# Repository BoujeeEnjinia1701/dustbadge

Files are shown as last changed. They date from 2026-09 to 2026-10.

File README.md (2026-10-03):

# DustBadge

     

**Area:** BioMedical · **TRL:** 3 of 9 (proof of concept on paper) · **Value-engineering target:** $91 USD · **Difficulty:** 3 of 5

A low-cost wearable dust monitor for workers in quarries, mines, stone fabrication and construction that estimates respirable dust exposure through the shift and warns before limits are reached.

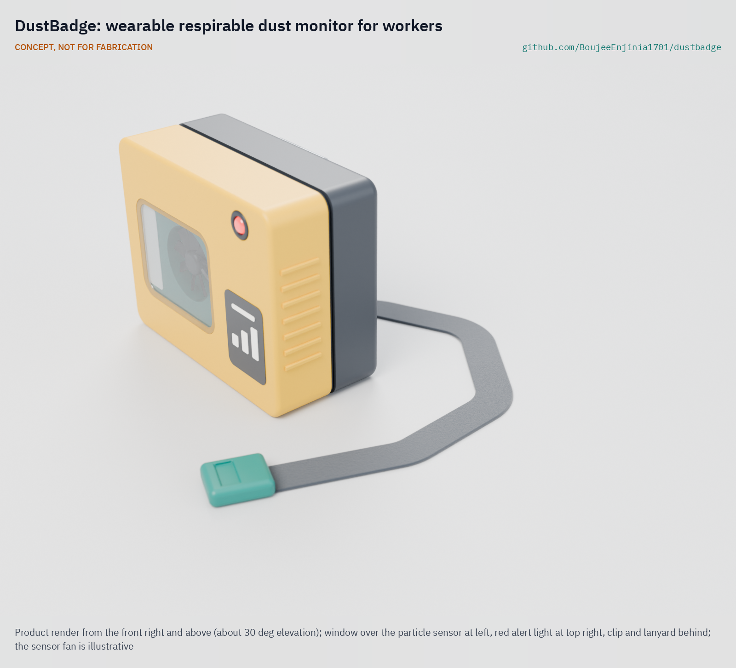
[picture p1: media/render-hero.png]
DustBadge: wearable respirable dust monitor for workers, product render


[Exploded render](media/render-exploded.png) · [Worn render](media/render-worn.png) · [Interactive 3D model](media/viewer.html) · [Concept blueprint (PDF)](media/concept-blueprint.pdf) · [General arrangement (PDF)](cad/drawings/DBG-DWG-001.pdf) · [Calculations](docs/04-calcs/01-sizing.md) · [Prototype build plan](docs/05-build-plan.md) · [Review note](docs/REVIEW.md)

## Concept rationale

A worker can only change what they can see. Filter sampling tells a site, days later, what one worker breathed on one day; a badge that vibrates when the shift average is heading over the limit tells the worker during the task, while there is still time to wet the cut, move upwind, put on a respirator or stop. An optical particle sensor cannot identify silica, so DustBadge measures respirable dust, corrects it with a site filter sample, and shows silica only as a labeled estimate. The result is a screening tool, not a compliance instrument. It is a research and educational prototype, not a medical device.

It is open and garage-buildable because the workers most exposed, in informal quarries, small stone workshops and artisanal mines, are the least likely to be covered by an employer's sampling program or to afford commercial personal dust monitors. One sensor module, one Bluetooth board, a phone-charger-sized cell and a 3D-printed case keep the parts at about $91, and worker organizations, clinics and universities can build, audit and adapt it under CERN-OHL-S-2.0.

## Burning platform

Silicosis killed more than 12,900 people worldwide in 2019 ([Chen, Liu and Xie, BMC Pulmonary Medicine, 2022](https://link.springer.com/article/10.1186/s12890-022-02040-9)), and it cannot be cured, only prevented. In the United States about 2.3 million workers are exposed to respirable crystalline silica, and OSHA estimated its 50 µg/m³ limit would prevent more than 600 deaths a year once fully effective ([US Department of Labor, 2016](https://www.dol.gov/newsroom/releases/osha/osha20160324)).

The burden is heaviest where monitoring is thinnest. An estimated 44 million people work in artisanal and small-scale mining, and a 2023 systematic review found a pooled silicosis prevalence of 23.9 % among those studied, with disease appearing after fewer than 6 years of work ([Howlett et al., PLOS Global Public Health, 2023](https://journals.plos.org/globalpublichealth/article?id=10.1371%2Fjournal.pgph.0002085)). Engineered stone has brought the disease back among young benchtop fabricators in high-income countries too: California's electronic case reporting found stone fabrication workers with silicosis in 2022 and 2023, one of whom died and two of whom needed lung transplants ([CDC MMWR, 2023](https://www.cdc.gov/mmwr/volumes/72/wr/mm7246a4.htm)).

## Where it could be used

### By industry

| Industry | Use |
| --- | --- |
| Quarrying and aggregates | Drillers, crusher and screen operators, and loader drivers checking exposure by task and location |
| Surface metal and non-metal mining | In-shift screening between regulatory samples (not underground coal or explosive atmospheres) |
| Stone benchtop fabrication | Warning when dry cutting, grinding or polishing pushes exposure up |
| Construction | Feedback when cutting concrete, brick, block or tile, and during demolition |
| Artisanal and small-scale mining | Low-cost exposure awareness for crews with no sampling at all, through NGOs and health programs |
| Occupational health research and training | A cheap, open screening tool for surveys, worker education and hygiene courses |

### By country or region

| Country or region | Why it matters there |
| --- | --- |
| India | A scoping review of Indian studies found a pooled silicosis prevalence of about 26 %, with 52 % radiological evidence among Rajasthan mine workers studied ([scoping review, PMC](https://pmc.ncbi.nlm.nih.gov/articles/PMC11776177/)). |
| South Africa | Among 14,221 employed gold miners surveyed, 3.8 % had silicosis, almost all more than 15 years after first exposure ([BMC Public Health, 2020](https://link.springer.com/article/10.1186/s12889-020-08876-2)). |
| Artisanal mining regions of Africa, Latin America and Asia | About 44 million artisanal and small-scale miners, with average respirable silica exposures reported from 0.19 to 89.5 mg/m³ in studies ([Howlett et al., 2023](https://journals.plos.org/globalpublichealth/article?id=10.1371%2Fjournal.pgph.0002085)). |
| United States | About 2.3 million exposed workers ([US Department of Labor, 2016](https://www.dol.gov/newsroom/releases/osha/osha20160324)); MSHA's 2024 rule applies a 50 µg/m³ limit and 25 µg/m³ action level to miners ([MSHA](https://www.msha.gov/regulations/rulemaking/silica)). |
| European Union | About 5.5 million workers are regularly exposed, mostly in construction, under a binding limit of 0.1 mg/m³ ([EU-OSHA OSHwiki](https://oshwiki.osha.europa.eu/en/themes/respirable-crystalline-silica)). |
| Australia | Banned the use, supply and manufacture of engineered stone benchtops, panels and slabs from 1 July 2024 after silicosis rose among fabricators ([SafeWork NSW](https://www.safework.nsw.gov.au/news/safework-public-notice/engineered-stone-prohibition-to-commence-1-july-2024)); removal and repair of installed stone still exposes workers. |

## What sparked the idea

The starting point was an instrument that already proves in-shift feedback works, and the narrow group it serves. Under MSHA's 2014 respirable coal mine dust rule, US underground coal operators have had to use the continuous personal dust monitor since February 1, 2016 for the miners in the dustiest occupations; the rule describes it as a device that "measures continuously, and in real-time, the concentration of respirable coal mine dust" and reports results during and at the end of the shift ([Federal Register, 79 FR 24814, 2014](https://www.federalregister.gov/documents/2014/05/01/2014-09084/lowering-miners-exposure-to-respirable-coal-mine-dust-including-continuous-personal-dust-monitors)). Quarry workers, stone fabricators and artisanal miners exposed to silica have no equivalent. DustBadge asks how much of that in-shift feedback an open, low-cost badge can deliver for silica, as a labeled estimate rather than a compliance measurement.

## Problem

Respirable crystalline silica causes silicosis, which is incurable. Personal exposure sampling is expensive and results arrive days later, so most workers never know their exposure.

## Concept

A chest-worn badge samples respirable dust (PM4) every second with an optical particle sensor, corrects it with a site filter sample, estimates silica from the site's silica fraction, keeps a running 8 h average and vibrates when the projected shift average is heading over the action level. The log goes to the worker's phone over Bluetooth, and the worker decides who sees it.

Full design precis: [docs/02-concept.md](docs/02-concept.md)

## Key components

- Optical particle sensor with a PM4 output (Sensirion SPS30 class, proposed)
- nRF52840 Bluetooth Low Energy module with flash for the shift log
- Vibration motor and red alert LED
- 2,000 mAh protected LiPo cell: 17.7 h of continuous sampling at the sensor's typical current, 12.8 h at its maximum current and 0 °C (DBG-CAL-001)
- Humidity and temperature sensor to flag readings that humidity or spray may bias
- 3D-printed high-visibility case with a downward, screened inlet and a spring clip, worn within 30 cm of the nose and mouth
- Phone app (web Bluetooth page or app) for the shift log

TRL 3 calculations ([DBG-CAL-001](docs/04-calcs/01-sizing.md)), updated for the recommendations Amish accepted on 2026-09-25 ([DBG-DDR-002](docs/decisions/0002-recommendations-accepted.md)): 64 x 52 x 31 mm (34 mm with the clip), about 121 g (limit 122 g), 17.7 h per charge typical and 12.8 h in the worst case, and an estimated $91.50 in parts, $0.50 over the $91 value-engineering target Amish set on 2026-09-26 (the foam pad of the worn version). On paper the design is not intrinsically safe. The working range is accepted as the sensor's 1 mg/m³ with over-range minutes flagged; accuracy at low dust levels depends on a larger reference sample and a per-task site factor; and in hot sun the badge must be worn shaded above 40 °C. See the [design precis](docs/02-concept.md) and [requirements](docs/03-requirements.md).

The working bill of materials is in [bom/bom.csv](bom/bom.csv).

## Building the prototype

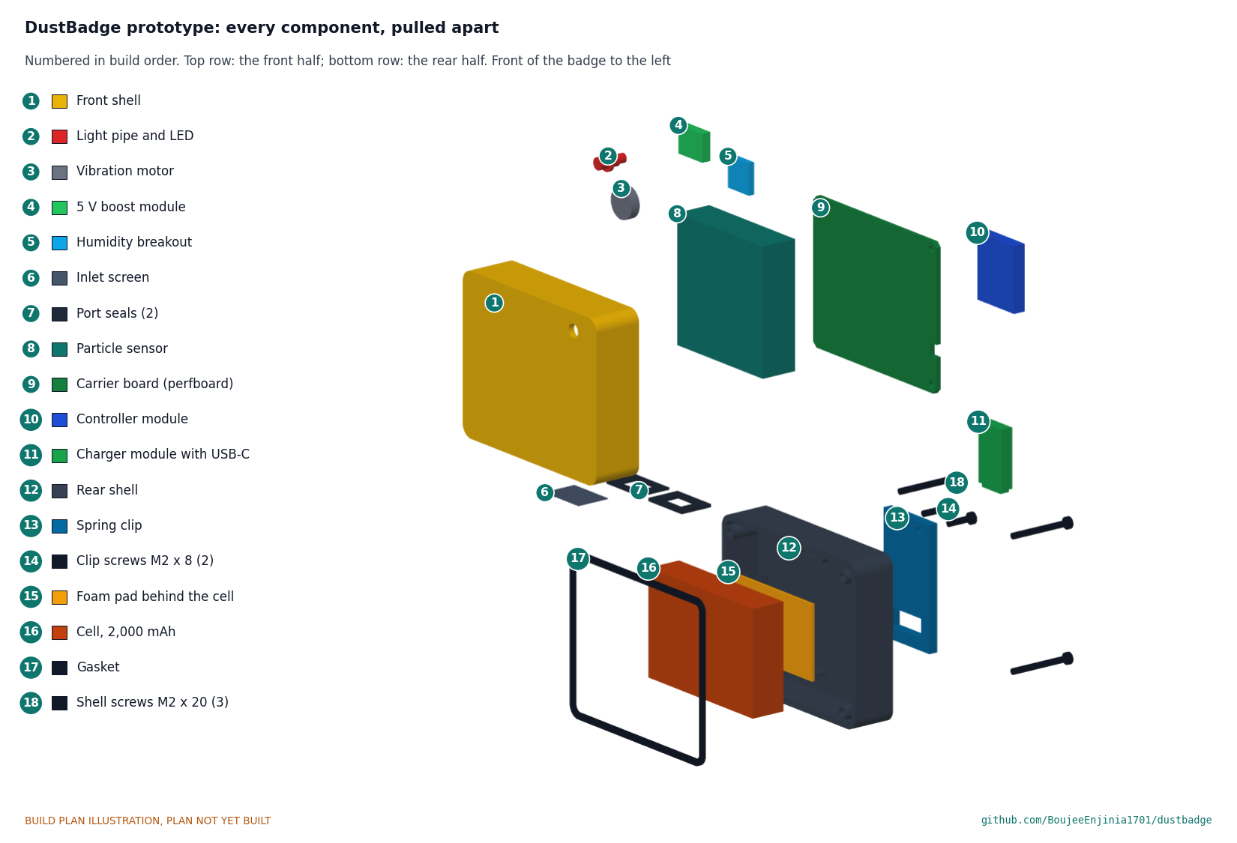
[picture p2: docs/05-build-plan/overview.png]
DustBadge prototype: every component pulled apart and numbered in build order


The [prototype build plan](docs/05-build-plan.md) (DBG-BLD-001) shows, in pictures, how to make each of the seventeen components and put them together in nine steps; nothing has been built yet. The made parts are two printed PETG shells, a printed TPU gasket and two port seals, a printed clear light pipe, a mesh inlet screen and a perfboard carrier; the sensor, cell, controller and small modules are bought and wired at block level. Writing the plan made the design buildable: the shells now close with three screws through a gasket, the sensor's ports are sealed to the floor slots, the sensor and cell are held by ribs, the clip is screwed on and the carrier board's modules have a place (DBG-DDR-003, open for Amish's review). Every picture is drawn from the model, and the model checks that each part touches what it should and clears what it should not.

## Safety

> A research and educational prototype, not a medical device and not certified monitoring or personal protective equipment. It does not replace regulatory sampling, dust controls or respirators, and a low reading does not mean the air is safe. It cannot measure silica directly; silica values are estimates.
>
> Not intrinsically safe: never use it in underground coal mines or anywhere flammable gas or combustible dust may be present.
>
> Lithium cells can overheat, vent and burn. Use a protected, fused cell, never charge the badge while it is worn, charge only between 0 and 45 °C, and never leave a first build charging unattended. In full sun above about 42 °C the badge can pass 60 °C; wear it shaded whenever the ambient is above 40 °C in full sun.

## Repository layout

| Folder | Contents |
| --- | --- |
| `docs/` | Problem, concept, requirements, calculations, prototype build plan, design decisions register and decision records |
| `cad/src/` | build123d Python source, the source of truth for all geometry |
| `cad/step/`, `cad/stl/` | Exported models for FreeCAD, other CAD tools and printing |
| `cad/drawings/` | 2D sketches and dimensioned drawings |
| `bom/` | Bill of materials |
| `electronics/` | KiCad schematics and PCB layouts |
| `firmware/` | Microcontroller code |
| `media/` | Renders, perspectives and photos |
| `build-log/` | Dated prototyping notes |

## Documentation

Controlled documents follow the portfolio [documentation standard](.kit/STANDARDS.md). Each carries a document ID (DBG-PRC-001 for the precis), a version and a revision history. Branded PDFs are built with `python .kit/render.py` and attached to GitHub Releases when a document is tagged, for example `DBG-PRC-001/v1.0`.

## Credits

Designed by Amish Chadha, with contributions from Dr. Geeti Chadha. See [CONTRIBUTORS.md](CONTRIBUTORS.md) for roles. To cite this design, use [CITATION.cff](CITATION.cff) (GitHub shows it as "Cite this repository").

AI assistance (Claude) was used to accelerate concept renders, prototype documentation and first-pass sizing calculations. Design direction and all decisions are Amish Chadha's, recorded in this repository's decision records (`docs/decisions/`).

## Licenses

- **Hardware** (CAD, drawings, BOM, electronics): [CERN-OHL-S v2](LICENSE)
- **Software** (firmware, scripts, notebooks): [MIT](LICENSE-SOFTWARE)

A project of the [Design Molecule](https://designmolecule.com) lab.

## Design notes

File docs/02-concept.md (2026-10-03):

---
doc_id: DBG-PRC-001
title: DustBadge design precis
project: DustBadge
doc_type: Design precis
version: "0.10"
status: Draft
date: '2026-10-02'
author: Amish Chadha
license: CERN-OHL-S-2.0
revisions:
- version: "0.1"
  date: '2026-09-25'
  author: Amish Chadha
  change: Initial scaffold
- version: "0.2"
  date: '2026-09-25'
  author: Amish Chadha
  change: Populate to TRL 2 (architecture, first-order numbers, safety, media)
- version: "0.3"
  date: '2026-09-25'
  author: Amish Chadha
  change: "TRL 3, design choices adopted per DBG-DDR-001; numbers checked against DBG-CAL-001; humidity sensor and thermistor charger added; general arrangement DBG-DWG-001"
- version: "0.4"
  date: '2026-09-25'
  author: Amish Chadha
  change: "Recommendations accepted by Amish (DDR-002): 2,000 mAh cell, R2 range accepted with over-range flag, R3 reference rule, sun use rule; numbers from DBG-CAL-001 v0.2; DBG-DWG-001 Rev P2"
- version: "0.5"
  date: '2026-09-26'
  author: Amish Chadha
  change: Budget approved by Amish; parts within the $91 budget
- version: "0.6"
  date: '2026-09-30'
  author: Amish Chadha
  change: "Design made constructable (DBG-DDR-003): fixings, gasket, seals and module positions; mass 119.9 g; build plan DBG-BLD-001 linked"
- version: "0.7"
  date: '2026-10-01'
  author: Amish Chadha
  change: Budget treated as a value-engineering target
- version: "0.8"
  date: '2026-10-01'
  author: Amish Chadha
  change: BioMedical area (DBG-DEC-001 v0.3); safety states a research and educational prototype, not a medical device
- version: "0.9"
  date: '2026-10-02'
  author: Amish Chadha
  change: 'Decisions of 2026-10-02 carried in: firmware on and off with a low-voltage cutoff, cell swelling rule, R9 at 122 g, site silica fraction method, first partner candidate'
- version: "0.10"
  date: '2026-10-02'
  author: Amish Chadha
  change: 'Worn version modelled (rear shell 1 mm deeper, foam pad): 120.7 g, 31 mm deep, USD 91.50; R15 over the target by USD 0.50; low-voltage cutoff 3.30 V'
---

# DustBadge design precis

## Summary

DustBadge is a chest-worn badge, 64 x 52 x 31 mm (34 mm with the clip) and about 121 g, that samples respirable dust continuously with an optical particle sensor, converts it to an estimate of respirable crystalline silica using a site calibration, keeps a running 8 h time-weighted average, and vibrates when the projected shift average is heading over the action level. The TRL 3 calculations (DBG-CAL-001 v0.7) show one off-the-shelf sensor, a Bluetooth module and a 2,000 mAh cell run a 12 h shift even at the sensor's maximum current and 0 °C (12.8 h; 17.7 h typical), for an estimated $91.50 in parts, $0.50 over the $91 value-engineering target Amish set on 2026-09-26 (DBG-DDR-002); the overage is the foam pad of the worn version. It cannot identify silica or replace compliance sampling. On paper it misses the hazardous-atmosphere requirement (R14) and, by $0.50, the cost requirement (R15); accuracy at low dust levels (R3) and operation in hot sun (R11) are at risk. The design choices below were decided by Amish on 2026-09-25 (DBG-DDR-002).

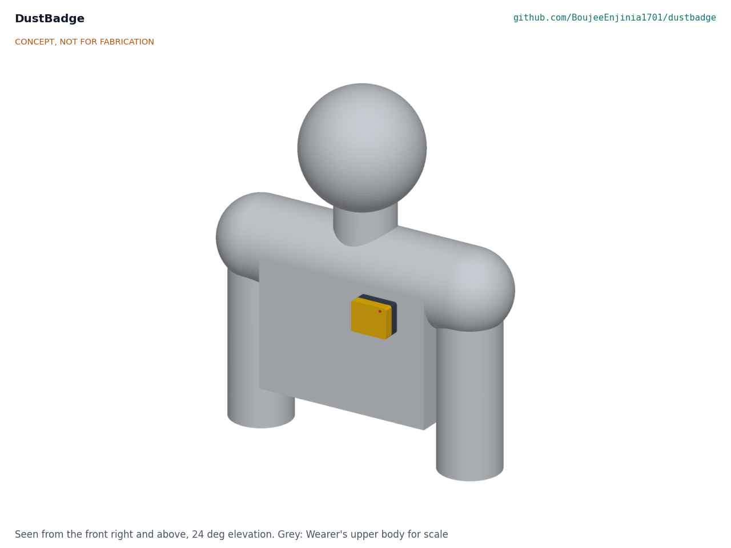
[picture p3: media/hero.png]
Figure 1. DustBadge worn on the upper chest, within the breathing zone. Grey is the wearer, for scale.


## How it works

1. **Sample.** A small fan in the particle sensor draws air in through a downward-facing screened inlet on the bottom of the badge. A laser counts and sizes particles, and the sensor reports mass concentration for particles up to 4 µm (PM4) every second.
2. **Calibrate.** A site factor, taken from at least one co-located filter sample, corrects the optical reading to a gravimetric respirable dust value. NIOSH notes that without such a factor, optical monitors can be off by up to 10 times ([Cauda, NIOSH, 2021](https://www.cdc.gov/niosh/nmam/pdf/chapter-am.pdf)). Chamber checks against a reference on the lab's CalRig calibration rig catch sensor drift between field samples.
3. **Estimate silica.** Calibrated respirable dust is multiplied by the site silica fraction (the quartz share of respirable dust for that site and task) to give an RCS estimate. With no fraction entered, the badge reports respirable dust only.
4. **Accumulate.** Every minute the firmware logs the 1 min average and updates the running TWA and a projection to the end of the shift at the current rate.
5. **Alert.** The badge vibrates and flashes when the projected 8 h RCS TWA passes the action level, and repeats at the limit. A short high peak (for example a dry cut) gives a separate brief alert so the worker can link the reading to the task.
6. **Sync.** At the end of the shift the worker's phone pulls the log over Bluetooth Low Energy (BLE). The worker decides whether to share it with a supervisor, hygienist or worker organization.

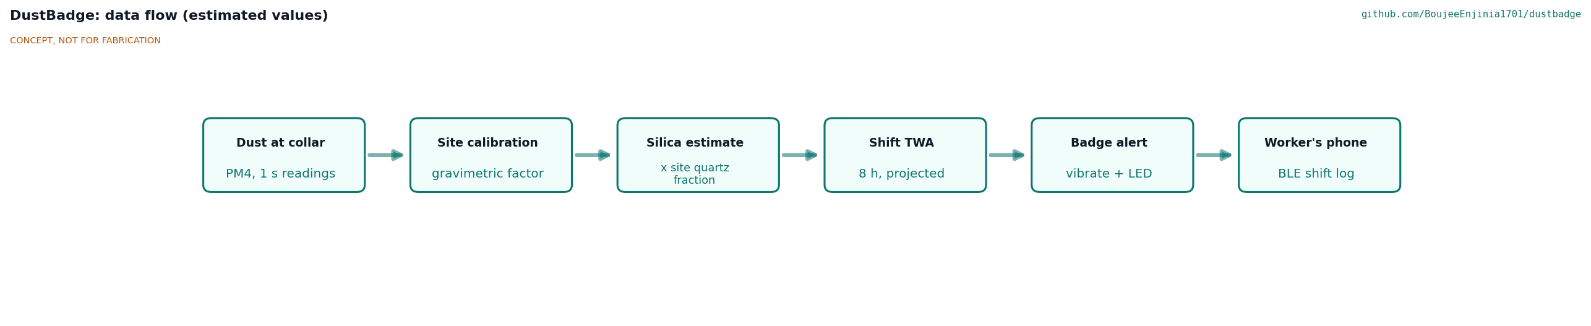
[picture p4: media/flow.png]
Figure 2. Data flow. Values are estimates.


## Main components

Table 1. Main components, numbered to match the exploded view and bom/bom.csv.

| # | Component | Proposed choice | Notes |
| --- | --- | --- | --- |
| 1 | Front shell | 3D-printed PETG, high-visibility yellow, with bottom inlet and outlet slots, USB-C opening and humidity vent; three screw bosses and two sensor stop ribs | Decided by Amish, 2026-09-25 (DBG-DDR-001, D7) |
| 2 | Inlet dust screen | Stainless mesh, about 1 mm aperture, a 16 x 11 mm square laid inside over the inlet slot and held by the inlet port seal | Keeps grit and splash out; must not act as a size selector for respirable particles |
| 3 | Particle sensor | Sensirion SPS30 class: PM1, PM2.5, PM4 and PM10 mass; 0 to 1,000 µg/m³; 41 x 41 x 12 mm; 26 g; 45 to 55 mA typical, 65 mA maximum at 5 V; PM4 precision ±25 µg/m³ below 100 µg/m³ and ±25 % above ([datasheet v2.0](https://sensirion.com/media/documents/8600FF88/64A3B8D6/Sensirion_PM_Sensors_Datasheet_SPS30.pdf)) | Chosen for its PM4 output. Decided by Amish, 2026-09-25 (DBG-DDR-001, D1) |
| 4 | Controller and BLE | nRF52840 module with 2 MB flash and LiPo charger (Seeed XIAO nRF52840 class) | Same module family as TremorTrace |
| 5 | Vibration motor | 10 mm coin motor, stuck to the inside of the front face | Felt through clothing when noise makes a beep useless |
| 6 | Alert LED | Red 3 mm LED in a printed clear light pipe with an inside flange, through the front face | Visible to the worker looking down and to coworkers |
| 7 | Carrier board | Perfboard carrying the controller and a 500 mA charger module with USB-C and a cell thermistor input; a 5 V boost module for the sensor and an SHT4x-class humidity and temperature breakout at a vent in the bottom face sit on the inside of the front face; polyfuse | Perfboard for the first build; humidity sensor and thermistor added at TRL 3 (DBG-CAL-001, sections B and C) |
| 8 | Battery | 2,000 mAh 3.7 V protected LiPo, about 50 x 34 x 11.5 mm, 38 g, with thermistor | Decided by Amish, 2026-09-25 (DBG-DDR-002, D8); was 1,500 mAh. Fills the space behind the carrier board; in the worn version 1.5 mm behind it, of which a 1 mm foam pad takes 1.0 mm (BOM line 13) |
| 9 | Rear shell | 3D-printed PETG with a flat printed TPU gasket and two TPU sensor port seals; three tubes that press the carrier board onto the front bosses, four cell locating ribs and two clip screw bosses | Holds the cell away from the body side; closed by three M2 x 20 screws from the rear face (DBG-DDR-003) |
| 10 | Clip | Stainless spring clip with strap loop, held by two M2 x 8 screws | For a shirt pocket, collar, harness or hi-vis vest |

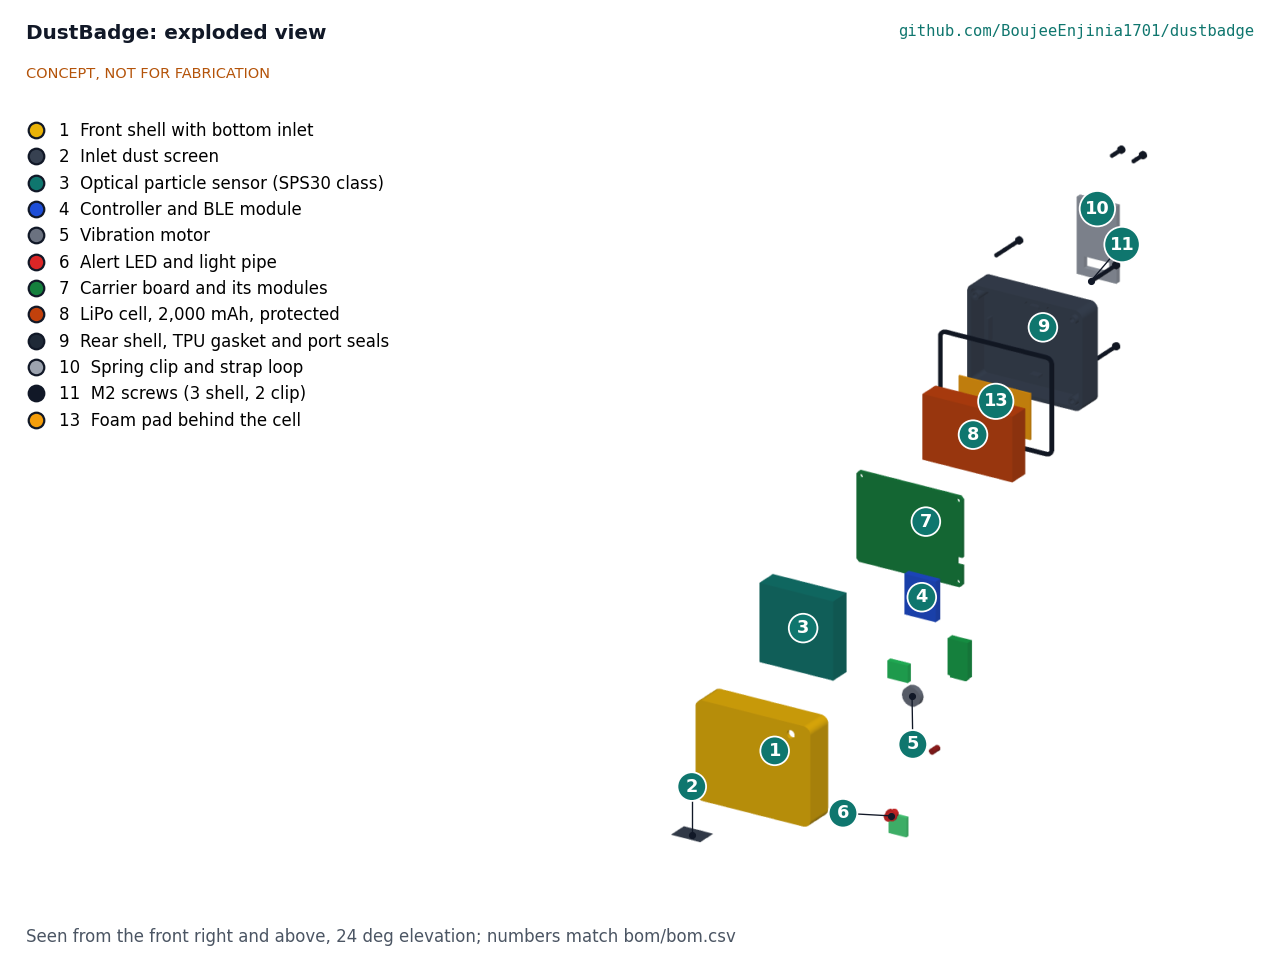
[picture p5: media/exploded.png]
Figure 3. Exploded view with BOM numbers.


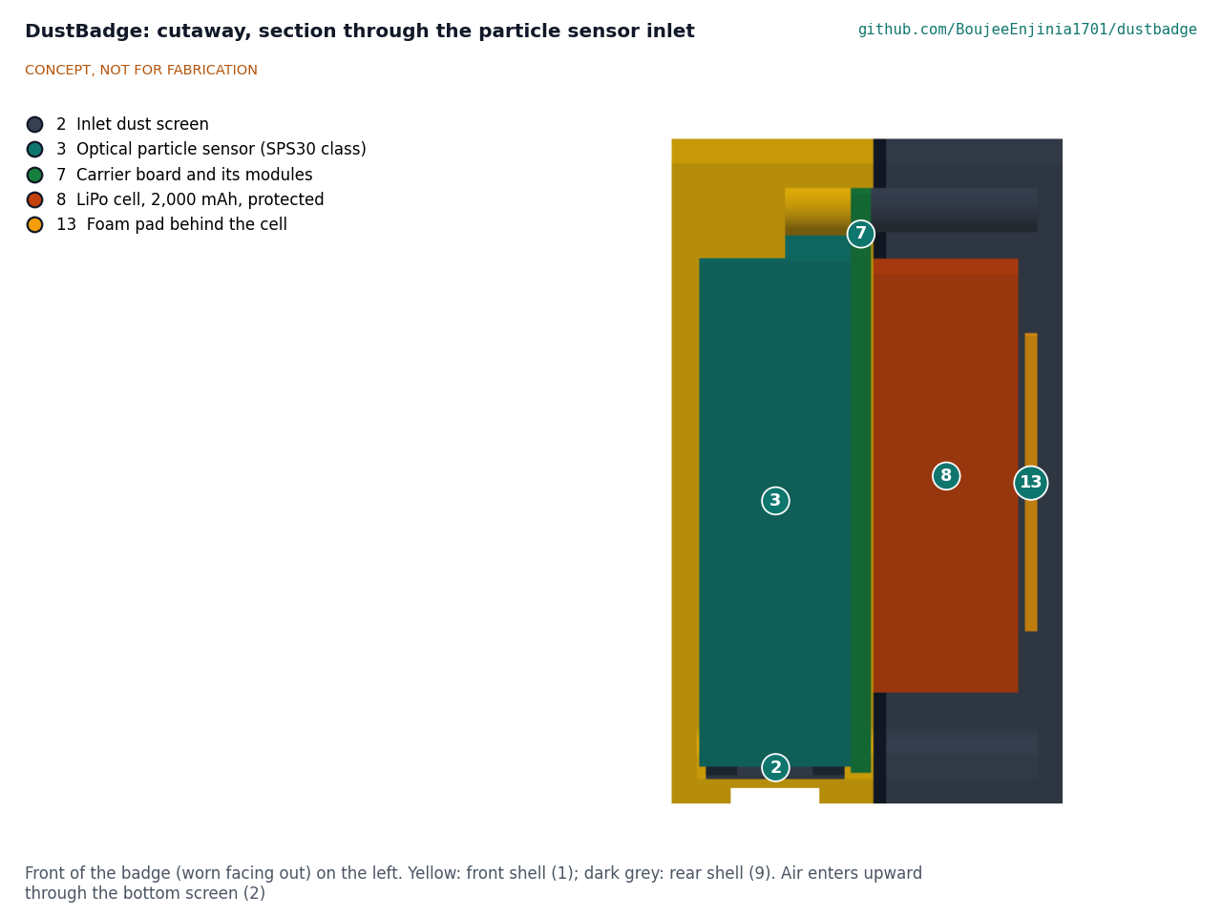
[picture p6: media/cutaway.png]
Figure 4. Section through the particle sensor, front of the badge on the left. Air enters through the bottom screen (2).


## Numbers checked at TRL 3

All values come from DBG-CAL-001 v0.2 and its script `docs/04-calcs/sizing.py`; the bracketed tags point to its output lines.

Table 2. Key numbers.

| Quantity | Value | Basis | Requirement |
| --- | --- | --- | --- |
| Power drawn from the cell | 335 mW typical, 393 mW maximum | Sensor 55 or 65 mA at 5 V through an 85 % boost, plus 11 mW for controller, BLE and humidity sensor [A3] | |
| Usable cell energy | 5.92 Wh; 5.03 Wh at 0 °C | 2,000 mAh x 3.7 V, 80 % usable, 85 % at 0 °C [A1] | |
| Run time, continuous sampling | 17.7 h typical; 12.8 h at maximum current and 0 °C | [A3] | R7 met |
| Cell for 12 h in the worst case | about 1,880 mAh; the 2,000 mAh cell gives a 7 % margin | [A4, A6] | |
| Charge time | 4.2 h at 500 mA | [B1] | |
| Shell temperature in full sun | about 48 °C at 30 °C ambient, 63 °C at 45 °C ambient; at most 57.8 °C under the use rule (shaded above 40 °C) | Solar and electrical heat against surface losses [C1, C3] | R11 at risk |
| Respirable dust at the action level | 250 µg/m³ at 10 % silica; 31 µg/m³ at 80 % silica | 25 µg/m³ RCS divided by the silica fraction [E2] | Within the 1 mg/m³ range |
| PM4 precision before site calibration | ±25 µg/m³ below 100 µg/m³ | Datasheet; 80 % of the dust level at the action level for quartz-rich stone [F4] | Site factor essential |
| Upper end of useful range | 1 mg/m³ with over-range flag; limit in range for silica fractions of 5 % or more | Sensor specification [E1, E3] | R2 met as restated |
| Shift average uncertainty after site calibration | ±21 to ±29 % (quarry); ±22 to ±30 % (quartz-rich stone with the 4.2 L/min, two-shift reference) | Root sum of squares, assumed terms [F2, F3] | R3 at risk |
| Log size | 11.5 kB per 12 h shift; about 182 shifts in 2 MB | 16-byte record each minute [H1] | R12 met |
| Inlet to nose and mouth | 242 mm | Model, collar or upper-strap mount [I1] | R8 met |
| Mass | 120.7 g | Shells, gasket and seals from model volume, parts from datasheets [J2] | R9 met against 122 g (relaxed from 120 g on 2026-10-02), 1.3 g margin with the deeper rear shell and foam pad needed before anyone wears the badge |
| Size | 64 x 52 x 31 mm; 34 mm deep with the clip | Model | R9 met |
| Parts cost | $91.50 | bom/bom.csv [L1, L2] | R15 not met: $0.50 over the value-engineering target ($91) |

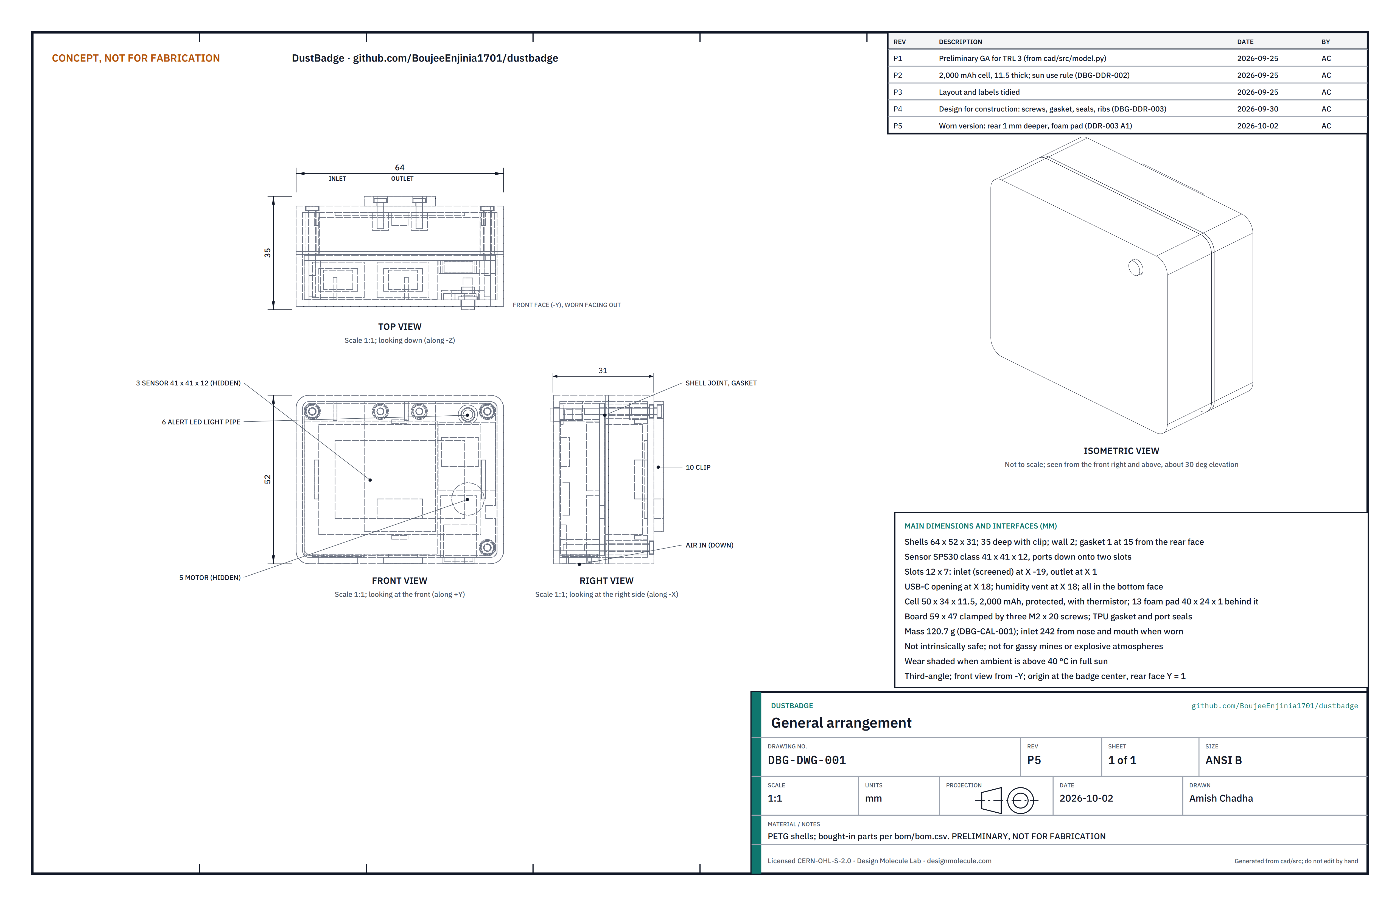
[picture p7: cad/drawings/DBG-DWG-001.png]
Figure 5. General arrangement DBG-DWG-001, Rev P3, from the parametric model.


## Key design choices

- **Estimate, never claim, silica.** The badge shows respirable dust as the measured quantity and RCS only as a labeled estimate from a site fraction. Decided by Amish, 2026-09-25 (DBG-DDR-001, D2).
- **PM4 sensor rather than a cheaper PM2.5 sensor.** The SPS30 class reports the size band closest to the respirable convention. A Plantower PMS5003 costs less but reports only up to PM10 with no PM4 bin. Decided by Amish, 2026-09-25 (DBG-DDR-001, D1).
- **Inlet facing down.** Reduces direct deposition of large chips and water spray into the sensor. Decided by Amish, 2026-09-25 (DBG-DDR-001, D7).
- **Continuous sampling.** Cutting and grinding tasks can last a minute or two, so the fan runs all shift rather than duty cycling, which the 2,000 mAh cell covers (R7 met on paper). Decided by Amish, 2026-09-25 (DBG-DDR-001, D4).
- **Default limits.** US OSHA and MSHA values by default (25 µg/m³ action level, 50 µg/m³ limit, 8 h TWA), configurable for other jurisdictions such as the EU 100 µg/m³. Decided by Amish, 2026-09-25 (DBG-DDR-001, D3).
- **Larger cell.** 2,000 mAh so that R7 holds at the sensor's maximum current and at 0 °C, at 8 g and $3. Decided by Amish, 2026-09-25 (DBG-DDR-002, D8).
- **Projected TWA alert.** Alerting on the projected shift average (dose so far plus the last 60 min mean rate) rather than on instantaneous readings avoids alarms every time a truck passes, while a separate brief peak alert (1 min mean over 250 µg/m³ RCS) still links dust to tasks. DBG-CAL-001 section G checks five scenarios.
- **Over-range readings count, not vanish.** A minute above the sensor's 1 mg/m³ range is logged at the range limit, flagged and counted toward the projection, so the badge alerts rather than going quiet. The 1 mg/m³ range with this flag is accepted for the first sectors (surface quarries and stone fabrication) instead of a wider-range sensor. Decided by Amish, 2026-09-25 (DBG-DDR-002, D11).
- **Reference sample at low-dust, high-silica sites.** Where respirable dust at the action level is below about 100 µg/m³, the site factor comes from a 4.2 L/min cyclone over two shifts, so the filter holds enough mass to weigh. Decided by Amish, 2026-09-25 (DBG-DDR-002, D9).
- **Sun use rule.** Wear the badge shaded, under a vest flap or out of direct sun, when the ambient is above 40 °C in full sun. A lighter shell is a later option, to be tested at TRL 4, which is on hold. Decided by Amish, 2026-09-25 (DBG-DDR-002, D10).
- **Humidity flag.** The added humidity sensor flags readings above 80 % RH, the sensor's best-performance limit, and sudden rises during wet cutting or spraying.
- **On and off in firmware.** There is no switch: the controller switches the boost off through its enable input and sleeps, waking on USB power, and a firmware low-voltage cutoff set above the cell protection threshold (3.30 V at the cell under load, against an assumed 2.75 V cut-out; DBG-CAL-001 [A7]) means the cell is never run down to the protection cut-out. Decided by Amish, 2026-10-02 (DBG-DDR-003, A2).
- **Cell swelling allowance.** The 0.7 mm of free depth round the cell is accepted only for bench work with nobody wearing the badge. Before anyone wears it, the badge is deepened 1 mm with a foam pad behind the cell, and R9 is relaxed to 122 g. The model and the drawings now show this worn version. Decided by Amish, 2026-10-02 (DBG-DDR-003, A1).
- **Site silica fraction.** By default, two or three cyclone filter samples per site go to an accredited laboratory for X-ray diffraction (as in NIOSH Method 7500), and the badge shows no silica estimate until a site fraction exists; field infrared analysis can come later where a partner has the instrument. Decided by Amish, 2026-10-02 (DBG-DDR-001, O2).
- **Worker-owned data.** Logs stay on the badge and the worker's phone unless the worker shares them, and are never used for discipline. Decided by Amish, 2026-09-25 (DBG-DDR-001, D5).

## Dependencies on other lab projects

- **CalRig** provides the chamber for periodic badge-to-badge and drift checks. Its TRL 2 design uses incense smoke from 5 to 300 µg/m³ and states that results will not transfer directly to mineral dust, so it cannot characterize the sensor above 1 mg/m³ or set a site factor. Field gravimetric samples are still needed for the site factor, because chamber aerosol is not site dust. The badge (64 x 52 x 33 mm) fits CalRig's 400 x 300 x 300 mm chamber.
- The badge does not use FieldNode, which is a fixed outdoor node; a FieldNode with the same sensor could log area dust at a site as a later option.

## Safety

> **Safety:** DustBadge is a research and educational prototype, not a medical device. It is not certified monitoring equipment or personal protective equipment, and it does not replace regulatory exposure sampling, engineering controls or respirators. A low reading does not mean the air is safe: the sensor cannot see silica directly, can drift, and can under-read outside its calibration.
>
> **Safety:** It is not intrinsically safe. Do not use it in underground coal mines or in any place where flammable gas or combustible dust may be present.
>
> **Safety:** The lithium cell is worn against the body. Use a protected cell with a fuse, never charge while worn, do not charge above 45 °C or below 0 °C, and stop use if the badge becomes warm or swollen or has been crushed. In full sun above about 42 °C ambient the shell can pass 60 °C (DBG-CAL-001, section C), above the cell's and the sensor's limits; wear it shaded or under a vest flap whenever the ambient is above 40 °C in full sun. Do not leave a first build charging unattended.
>
> **Safety:** Exposure logs are health-related personal data. Keep them with the worker, and never use them to discipline workers.

## Open questions

- Accuracy (R3): the error terms in DBG-CAL-001 section F are assumed, and a factor shared across badges misses ±25 % even with the larger reference. Measuring them is TRL 4 work, on hold.
- Range (R2): the sensor's response above 1 mg/m³ to mineral dust is unknown and cannot be checked on CalRig as designed.
- Humidity and water spray (R11): the size of the bias from wet cutting and dust suppression sprays is unknown; the badge can flag high humidity.
- Inlet: does the screened downward inlet change sampling efficiency for respirable particles when the worker moves?
- First co-design partner (DBG-DDR-001, O1): the first candidate to approach is a university industrial hygiene group that already samples respirable crystalline silica, for example one linked to a NIOSH Education and Research Center, with a stone fabrication shop or surface quarry as the site (decided by Amish, 2026-10-02); nothing is agreed.

Prototype build plan: [DBG-BLD-001](05-build-plan.md); design decisions: [DBG-DEC-001](06-design-decisions.md). Concept media: [blueprint sheet](../media/concept-blueprint.pdf), [interactive 3D model](../media/viewer.html). General arrangement: [DBG-DWG-001](../cad/drawings/DBG-DWG-001.pdf). Model: `cad/src/model.py`, exports in `cad/step/` and `cad/stl/`.

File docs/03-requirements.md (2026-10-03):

---
doc_id: DBG-REQ-001
title: DustBadge requirements
project: DustBadge
doc_type: Requirements
version: "0.9"
status: Draft
date: '2026-10-02'
author: Amish Chadha
license: CERN-OHL-S-2.0
revisions:
- version: "0.1"
  date: '2026-09-25'
  author: Amish Chadha
  change: Initial scaffold
- version: "0.2"
  date: '2026-09-25'
  author: Amish Chadha
  change: First measurable requirements for TRL 2, with status against the concept
- version: "0.3"
  date: '2026-09-25'
  author: Amish Chadha
  change: "TRL 3, status from DBG-CAL-001 for every requirement; R8 restated for the inlet; R6 defaults follow DBG-DDR-001 D3; R11 and R3 now not met, R10 not verifiable at TRL 3"
- version: "0.4"
  date: '2026-09-25'
  author: Amish Chadha
  change: "Recommendations accepted by Amish (DDR-002): R2 restated to 1 mg/m³ with over-range flag, R3 reference rule, R11 sun use rule; statuses from DBG-CAL-001 v0.2 with the 2,000 mAh cell"
- version: "0.5"
  date: '2026-09-26'
  author: Amish Chadha
  change: Budget approved by Amish; R15 target $91, status Not met to Met on paper
- version: "0.6"
  date: '2026-09-30'
  author: Amish Chadha
  change: "Design made constructable (DBG-DDR-003); R9 mass 119.9 g, 0.1 g margin; no status changed"
- version: "0.7"
  date: '2026-10-01'
  author: Amish Chadha
  change: Budget treated as a value-engineering target
- version: "0.8"
  date: '2026-10-02'
  author: Amish Chadha
  change: 'R9 relaxed to 122 g by Amish on 2026-10-02; site silica fraction assumption restated'
- version: "0.9"
  date: '2026-10-02'
  author: Amish Chadha
  change: 'R15 not met by USD 0.50 after the foam pad of the worn version; R9 met at 120.7 g against 122 g'
---

# DustBadge requirements

These are the requirements for the concept, with their status from the TRL 3 calculations in DBG-CAL-001 v0.7. On 2026-09-25 Amish accepted the review recommendations (DBG-DDR-002): R2 is restated to the sensor's 1 mg/m³ range with an over-range flag, R3 keeps ±25 % but requires a larger reference sample at low-dust, high-silica sites, R11 adds a use rule for full sun, and the cell grows to 2,000 mAh. On 2026-09-26 Amish set the value-engineering target at $91 to match the priced BOM (DBG-DDR-002, O3), so R15 was within the target. On 2026-10-02 the foam pad of the worn version took the parts cost to $91.50, so R15 is no longer met (by $0.50). On paper two requirements are not met (R14 intrinsic safety, out of scope, and R15 cost), two are at risk (R3 accuracy and R11 site conditions), one cannot be verified at TRL 3 (R10), and ten are met, six by calculation and four by design.

Table 1. Requirements and concept status.

| ID | Requirement | Target | Status at TRL 3 (DBG-CAL-001) | Verification (TRL 3 or later) |
| --- | --- | --- | --- | --- |
| R1 | Measure the respirable dust fraction | Mass concentration of particles up to 4 µm (PM4), a proxy for the ISO 7708 respirable convention | Met by design. PM4 is a proxy: for quartz, optical PM4 would include grains up to about 6.5 µm aerodynamic, while the sensor under-sees coarse grains (CAL-001, D) | Datasheet review; later comparison with a cyclone sampler |
| R2 | Cover the working range | 0 to 1 mg/m³ respirable dust; minutes above the range flagged, logged at the range limit and counted toward the projection. Restated from 0 to 5 mg/m³ for the first sectors in D6 (DBG-DDR-002 D11) | Met on paper. The RCS limit lies in range only for silica fractions of 5 % or more; above the range the badge reports only that dust was over range (CAL-001, E) | Calculation of expected site ranges; chamber test on CalRig |
| R3 | Accuracy after site calibration | Shift average within ±25 % of a co-located gravimetric sample. Where respirable dust at the action level is below about 100 µg/m³ (low-dust, high-silica sites such as quartz-rich stone), the reference is a 4.2 L/min cyclone over two shifts (DBG-DDR-002 D9) | **At risk.** Met on paper with a factor per task on the same badge: ±21 % (quarry), ±22 % (quartz-rich stone with the D9 reference). Not met with one factor shared across badges per site: ±29 to ±30 % (CAL-001, F). Error terms assumed | Error budget at TRL 3; later co-located field samples |
| R4 | Estimate silica exposure | RCS estimate = calibrated PM4 mass x site silica fraction, always labeled as an estimate; dust shown alone when no fraction is entered | Met by design | Firmware sketch review |
| R5 | Update often enough to catch tasks | 1 s readings, 1 min logged averages, running 8 h time-weighted average (TWA) updated every minute | Met by design; the sensor gives new readings every second | Firmware sketch review |
| R6 | Warn before a limit is reached | Vibration and LED when the projected 8 h RCS TWA exceeds the action level (default 25 µg/m³) and a repeated alert at the limit (default 50 µg/m³); both configurable | Met by design and on paper: five scenarios alert as intended, one early warning after a single heavy cut (CAL-001, G). Defaults per DBG-DDR-001 D3 | Firmware sketch review |
| R7 | Last a full shift | 12 h of continuous sampling per charge | Met on paper with the 2,000 mAh cell (DBG-DDR-002 D8): 17.7 h at the typical 55 mA and 25 °C; 12.8 h at the 65 mA maximum and 0 °C (CAL-001, A) | Power budget calculation |
| R8 | Wearable in the breathing zone | Inlet worn within 30 cm of the nose and mouth; clip or harness loop | Met on paper: inlet 242 mm from the nose and mouth at a collar or upper-strap mount; a mount more than 269 mm below them fails (CAL-001, I) | Massing model |
| R9 | Light and small | Mass 122 g or less (relaxed from 120 g by Amish, 2026-10-02, for the 1 mm deeper rear shell and foam pad needed before anyone wears the badge); no larger than 75 x 55 x 35 mm | Met on paper: 120.7 g with the worn version (rear shell 1 mm deeper, foam pad), a 1.3 g margin against 122 g; 64 x 52 x 34 mm with the clip (CAL-001, J) | Massing model, then weighing |
| R10 | Survive the site | Electronics splash and dust protected (IP54 target except the sensor air path); inlet facing down; survives a 1.5 m drop onto concrete | Not verifiable at TRL 3: 750 to 1,500 g deceleration on a 1.5 m drop; gasketed joint untested (CAL-001, K) | Design review; later drop and spray tests |
| R11 | Work in site conditions | 0 to 45 °C, 10 to 90 % RH non-condensing; readings flagged when humidity or spray may bias them. Use rule: worn shaded when the ambient is above 40 °C in full sun (DBG-DDR-002 D10) | **At risk.** Under the use rule the shell stays at or below 57.8 °C, 2.2 K under the sensor's 60 °C limit; without it, about 63 °C in full sun at 45 °C. Sensor best performance only to 40 °C and 80 % RH; humidity flag possible with the RH sensor (CAL-001, C) | Literature and datasheet review |
| R12 | Keep a shift log | At least 30 shifts of 1 min records on the badge; export over Bluetooth Low Energy to the worker's phone | Met on paper: 11.5 kB per 12 h shift, about 182 shifts in 2 MB (CAL-001, H) | Storage calculation |
| R13 | Protect the worker's data | Stored on the badge and the worker's phone; shared with an employer only by the worker's choice | Met by design (DBG-DDR-001 D5) | Design review |
| R14 | Safe in hazardous atmospheres | Certified intrinsically safe for gassy mines and explosive atmospheres | **Not met and out of scope** for this prototype; it must be labeled not for such use | Design review |
| R15 | Low cost and buildable | Parts $91 or less (was $90; DBG-DDR-002 O3); no custom PCB required for the first build | Not met: $91.50, $0.50 over the $91 target, because of the foam pad of the worn version (CAL-001, L) | Priced BOM |

## Assumptions

- The respirable convention in ISO 7708 has a 50 % cut near 4 µm aerodynamic diameter; PM4 from an optical sensor is used as a proxy.
- A site silica fraction (the quartz share of respirable dust) is available for each site and task from at least one filter sample analyzed by a laboratory or a field infrared method. Where no laboratory is near, two or three cyclone filter samples per site are sent to an accredited laboratory for X-ray diffraction (as in NIOSH Method 7500), and no silica estimate is shown until a site fraction exists (decided by Amish, 2026-10-02, DBG-DDR-001, O2).
- The wearer follows the sun use rule in R11; the badge cannot enforce it.
- Default limits follow US OSHA and MSHA (50 µg/m³ limit and 25 µg/m³ action level, 8 h TWA), decided by Amish on 2026-09-25 (DBG-DDR-001 D3, DBG-DDR-002). Other jurisdictions can be configured, for example the EU binding limit of 100 µg/m³.
- The calculation assumptions (sensor figures, cell, error terms, thermal coefficients) are listed in DBG-CAL-001, Table 1.
- Shifts are up to 12 h; the projected TWA is normalized to 8 h as the regulations define it.

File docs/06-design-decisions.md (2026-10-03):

---
doc_id: DBG-DEC-001
title: DustBadge design decisions register
project: DustBadge
doc_type: Design decisions register
version: "0.5"
status: Draft
date: '2026-10-02'
author: Amish Chadha
license: CERN-OHL-S-2.0
revisions:
  - version: "0.1"
    date: '2026-09-30'
    author: Amish Chadha
    change: Register opened with the open decisions from the review note, the decision records and the build plan work
  - version: "0.2"
    date: '2026-10-01'
    author: Amish Chadha
    change: Budget treated as a value-engineering target
  - version: "0.3"
    date: '2026-10-01'
    author: Amish Chadha
    change: Dr. Geeti Chadha added as a contributor and the project moved to the BioMedical (healthcare) area (decided by Amish)
  - version: "0.4"
    date: '2026-10-02'
    author: Amish Chadha
    change: 'Amish approved the recommendations for all ten open decisions (2026-10-02); DBG-DDR-003 accepted; moved to decisions made'
  - version: "0.5"
    date: '2026-10-02'
    author: Amish Chadha
    change: 'Worn version carried into the design: foam pad on the BOM (USD 91.50, USD 0.50 over the target); value engineering section restated; target change proposed'
---

# DustBadge design decisions register

Every design decision still to be made, and every decision made, in one place. Each decision is argued in full in its decision record under `docs/decisions/`; this register is the index Amish works from. The build plan (`docs/05-build-plan.md`) describes the design as it stands and does not list open decisions.

## Open decisions

| # | Decision | Options | Recommendation |
| --- | --- | --- | --- |
| 1 | Value-engineering target. The foam pad of the worn version (USD 0.50, BOM line 13) takes the estimated cost to USD 91.50, USD 0.50 over the USD 91 target, so R15 is not met. `budget_usd` is unchanged at 91. | (a) raise the target to USD 92; (b) keep USD 91 and look for USD 0.50 of savings when parts are bought; (c) keep USD 91 and accept R15 as not met. | (a), so that the target covers the worn version; the optional lanyard (about USD 1) would still sit outside it. **Proposed, awaiting Amish.** |

## To confirm when parts are bought

| # | What to confirm | Why it matters | Source |
| --- | --- | --- | --- |
| 1 | The cell, including its protection board, is no larger than 50 x 34 x 11.5 mm, its lead leaves at one short side, and its plug polarity matches the charger | The cell ribs, the swelling allowance (0.7 mm in the bench version, 1.7 mm with the foam pad of the worn version) and the board notch are sized for it | DBG-DDR-003, P8 |
| 2 | The charger module is no larger than 11 x 19 mm with its USB-C on a short edge, and its temperature window is 0 to 45 °C | It must fit beside the sensor with its USB-C in the opening, and the charge stop is part of the safety case | DBG-DDR-003, P6 |
| 3 | The boost module (11.4 x 9 mm or less, with an enable input) and the humidity breakout (10 x 10 mm or less, sensor at one edge) | They are taped into a strip 17 mm wide beside the sensor; the humidity sensor must sit over its vent | DBG-DDR-003, P6 |
| 4 | Where the particle sensor's cable leaves it, and the cable length | The model leaves room above and beside the sensor between the stop ribs; a connector on another face would need the ribs moved | DBG-DDR-003, P5 |
| 5 | The spring clip's base leaf is flat and wide enough for two holes 12 mm apart | The clip is held by two M2 x 8 screws | DBG-DDR-003, P9 |
| 6 | The pilot hole for the M2 thread-forming screws in PETG (1.7 mm assumed), from the screw maker's data | Too large a hole strips; too small cracks the boss | DBG-DDR-003, P1 |

## Value engineering

Value-engineering target: USD 91 (a hypothetical control target, not a limit). Estimated cost of the constructable design: USD 91.50 (USD 0.50 over the target). The estimate rests on indicative prices.

Main cost drivers: the optical particle sensor (USD 48.00, 52 % of the cost), the 2,000 mAh LiPo cell (USD 13.00; it added USD 3), the controller and BLE module (USD 10.00) and the carrier board (USD 9.00).

Savings worth trying: confirming prices when parts are bought. A 1,500 mAh cell would save USD 3 but returns R7 (a full shift) to at risk. The optional breakaway lanyard (decided on 2026-10-02 for TRL 4) would take the estimate about USD 1 over the target, and the foam pad of the deeper worn version (USD 0.50) is already in the estimate and is what takes it over the target.

## Decisions made

| Date | Decision | Decided by | Record |
| --- | --- | --- | --- |
| 2026-09-25 | TRL 2 review items D1 to D7: SPS30-class sensor, silica shown only as a labeled estimate, US OSHA and MSHA default limits, continuous sampling, worker-owned data, surface quarries and stone fabrication first, downward screened inlet with a yellow shell and clip | Amish: "i accept all your recommendations, go with them across all repos." | DBG-DDR-001, DBG-DDR-002 |
| 2026-09-25 | D8 to D11: 2,000 mAh cell; R3 reference rule (4.2 L/min cyclone over two shifts at low-dust, high-silica sites); sun use rule; R2 restated to 1 mg/m³ with an over-range flag | Amish, same instruction | DBG-DDR-002 |
| 2026-09-26 | Value-engineering target set to $91 to match the priced BOM (O3) | Amish: "i approve all the budget items." | DBG-DDR-002 v0.2 |
| 2026-10-01 | Dr. Geeti Chadha added as a contributor (CONTRIBUTORS.md, README Credits) and the project moved to the BioMedical (healthcare) area, with soft, non-clinical wording: a research and educational prototype, not a medical device | Amish: "yes add Dr. Geeti Chadha to breathebox and dustbadge and make those both healthcare projects" | `project.yaml`, `CONTRIBUTORS.md`, `README.md`, DBG-PRB-001 v0.7, DBG-PRC-001 v0.8 |
| 2026-10-02 | Design for construction accepted: P1 to P10 as made; the TRL 4 drop test also checks that the boost module, humidity board and motor stay on their foam tape | Amish: "i approve your recommendations for all 555 open decisions." | DBG-DDR-003, Table 1 |
| 2026-10-02 | Cell swelling: the 0.7 mm allowance (a) is accepted only for bench work with nobody wearing the badge; before anyone wears it, (b): the badge is deepened 1 mm with a foam pad behind the cell and R9 is relaxed to 122 g. Return to (a) only if the bought cell's datasheet states swelling under about 6 % | Amish: "i approve your recommendations for all 555 open decisions." | DBG-DDR-003, A1 |
| 2026-10-02 | On and off: firmware only (the boost switched off through its enable input, the controller asleep, waking on USB power), with a firmware low-voltage cutoff set above the cell protection threshold so the cell is never run down to the protection cut-out | Amish: "i approve your recommendations for all 555 open decisions." | DBG-DDR-003, A2 |
| 2026-10-02 | R9 mass margin: accepted, the prototype is weighed at TRL 4; with the deeper shell of the swelling decision the R9 limit is 122 g | Amish: "i approve your recommendations for all 555 open decisions." | DBG-DDR-003, A3; DBG-CAL-001 [J2] |
| 2026-10-02 | First co-design partner: a university industrial hygiene group that already samples respirable crystalline silica, for example one linked to a NIOSH Education and Research Center, working with a stone fabrication shop or surface quarry as the site. This is the first candidate type to approach, not an agreed partner | Amish: "i approve your recommendations for all 555 open decisions." | DBG-DDR-001, O1 |
| 2026-10-02 | Site silica fraction: by default two or three cyclone filter samples per site go to an accredited laboratory (X-ray diffraction, as in NIOSH Method 7500), and no silica estimate is shown until a site fraction exists; field infrared analysis is considered later where a partner has the instrument | Amish: "i approve your recommendations for all 555 open decisions." | DBG-DDR-001, O2 |
| 2026-10-02 | Clear front window: renders only; decided at TRL 4 | Amish: "i approve your recommendations for all 555 open decisions." | `docs/REVIEW.md`, 2026-09-26, item 1 |
| 2026-10-02 | Sensor fan in the renders: kept, with a caption saying it is illustrative | Amish: "i approve your recommendations for all 555 open decisions." | `docs/REVIEW.md`, 2026-09-26, item 2 |
| 2026-10-02 | Side grip ribs: appearance only; if adopted at TRL 4 they are recessed so the badge stays 64 mm wide | Amish: "i approve your recommendations for all 555 open decisions." | `docs/REVIEW.md`, 2026-09-26, item 4 |
| 2026-10-02 | Lanyard: an optional lanyard line is added at TRL 4, specified as breakaway only | Amish: "i approve your recommendations for all 555 open decisions." | `docs/REVIEW.md`, 2026-09-26, item 5 |

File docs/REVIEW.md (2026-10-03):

# Review note: DustBadge

## Session 2026-09-25: /populate to a strong TRL 2

### What was done

- `docs/01-problem.md` (DBG-PRB-001 v0.2): problem with cited burden figures, prior work and the gap, users and context, constraints, out of scope, open questions; co-design checklist kept.
- `docs/03-requirements.md` (DBG-REQ-001 v0.2): 15 measurable requirements (R1 to R15) with targets, status against the concept and planned verification; assumptions.
- `docs/02-concept.md` (DBG-PRC-001 v0.2): how it works, numbered components, first-order numbers (power, run time, range, mass, cost), design choices, dependencies on CalRig, safety, open questions.
- `cad/src/concept_media.py`: massing model of the badge (10 numbered parts) with the wearer's upper body as the scale context. The kit's cutaway cuts only across Y, so the script turns the badge 90 degrees and renders a labeled side section through the sensor itself.
- `media/`: `hero.png`, `concept-blueprint.png`, `.pdf` and `.svg`, `exploded.png` with BOM callouts, `cutaway.png`, `flow.png` (data flow), `model.glb` and `viewer.html`. Temporary `_views` folders removed.
- `bom/bom.csv`: 12 lines with indicative prices; lines 1 to 10 match the exploded view. `bom/bom-notes.md` updated.
- `README.md`: hero and links line; concept rationale, burning platform, industry and region tables, trigger, concept, key components and safety expanded with cited sources.
- `docs/pdf/`: branded PDFs of the three controlled documents.

### Key results (estimates, to be checked at TRL 3)

| Quantity | Estimate | Requirement |
| --- | --- | --- |
| Run time, continuous sampling | about 13 h typical, about 11 h worst case | R7 (12 h) at risk |
| Useful range | up to about 1 mg/m³ (sensor specification) | **R2 (5 mg/m³) not met** |
| Respirable dust at the RCS action level | about 250 µg/m³ at 10 % silica; about 30 to 50 µg/m³ for quartz-rich stone | Within range |
| Size and mass | 64 x 52 x 30 mm, about 110 g | R9 met, thin margin on mass |
| Distance to the nose | about 220 mm | R8 met |
| Shift log | about 12 kB per 12 h shift | R12 met |
| Parts cost | about $85 against the $90 budget | R15 met; no budget change proposed |

Requirements not met or unverified:

- **R2 (range) not met:** the SPS30 class is specified to 1 mg/m³; quarry and artisanal mining peaks can be far higher.
- **R14 (intrinsic safety) not met and out of scope:** the badge must not be used in underground coal or explosive atmospheres.
- **R7 (run time) at risk** at the sensor's maximum current.
- **R3 (±25 % accuracy after site calibration), R10 (ingress and drop) and R11 (humidity and spray bias)** are unverified.

`project.yaml` is unchanged: pitch and problem remain accurate. The problem line says results "arrive days later"; NIOSH FAST can give same or next day results, but it is not widely available, so the line was left as is.

### Proposed, awaiting Amish

Status update: items 1 to 7 are now "Decided by Amish, 2026-09-25: go with recommendation" (DBG-DDR-002); the partner in item 6 had no recommendation and stays "Proposed, awaiting Amish".

1. **Particle sensor.** Options: (a) Sensirion SPS30 class with a PM4 output, about $48; (b) Plantower PMS5003, about $15 to $20, no PM4 bin and larger; (c) a wider-range sensor to meet R2, likely over budget. Recommendation: (a), and characterize it above 1 mg/m³ on CalRig at TRL 3.
2. **How silica is shown.** Options: (a) respirable dust always, RCS only as a labeled estimate once a site silica fraction is entered; (b) respirable dust only. Recommendation: (a).
3. **Default limits and alerts.** Options: US OSHA and MSHA values (25 µg/m³ action level, 50 µg/m³ limit) by default, configurable for other jurisdictions such as the EU 100 µg/m³; or a stricter default. Recommendation: US values by default, configurable.
4. **Sampling mode.** Continuous (catches short tasks, about 13 h) or duty-cycled (longer life, misses short peaks). Recommendation: continuous.
5. **Data ownership.** Logs kept by the worker and shared only by consent, with a stated rule that they are not used for discipline. Recommendation: adopt.
6. **First sector and partner.** Surface quarries and stone fabrication first, through a worker organization, NGO or university hygiene group; underground coal and explosive atmospheres excluded. Recommendation: adopt, partner to be chosen by Amish.
7. **Case details.** Downward screened inlet, high-visibility yellow front shell, spring clip with strap loop. Recommendation: adopt for the TRL 3 model.

### Safety concerns

- False reassurance is the main hazard: a low reading from a drifted or uncalibrated sensor could lead a worker to skip a respirator. The documents say plainly that silica is estimated and that the badge does not replace controls, respirators or sampling.
- Not intrinsically safe; must be labeled against use in gassy mines or explosive atmospheres.
- LiPo cell worn on the body in hot, dusty sites: protected and fused cell, no charging while worn, charging between 0 and 45 °C only.
- Exposure logs are sensitive personal data and could be misused by an employer.

### Problems and notes

- `.kit/concept.py` centers its cutaway cutter on the origin, so assemblies placed far from the origin produce an empty cutaway. The badge is modeled at the origin and the wearer placed around it. Worth fixing in the kit.
- The legacy `cad/src/model.py` placeholder is untouched (TRL 3 work).
- Some prevalence figures come from studies of selected groups and should not be read as national rates.

### Recommended next step

Review this note and the media, then decide items 1, 2 and 6. If approved, run `/advance-trl3` to build the error budget for R3, the power budget for R7, the range question for R2 and the parametric model and drawing sheet.

## Session 2026-09-25: TRL 3

On 2026-09-25 Amish asked for this batch to be taken through the usual process with the instruction "you know the drill, nothing gets past TRL 3". He has not reviewed this repo's TRL 2 items one by one, so every item above that carried a recommendation is adopted as recommended for TRL 3 under that instruction and stays open for his review. This session ran `/advance-trl3` on that basis and stopped at TRL 3.

### What was done

- `docs/decisions/0001-trl2-review-decisions.md` (DBG-DDR-001 v0.1, status proposed): items D1 to D7 adopted as recommended for TRL 3 under Amish's 2026-09-25 instruction, open for his review; O1 and O2 left as "Proposed, awaiting Amish".
- `docs/04-calcs/01-sizing.md` (DBG-CAL-001 v0.1) and `docs/04-calcs/sizing.py`: power and run time, charging, badge temperature in sun, PM4 against the ISO 7708 respirable convention, working range, an error budget for the shift average, alert logic in five scenarios, log size, breathing zone, mass, drop loads and cost, with a status for every requirement. The script imports the model's parameters and mass breakdown and reads the BOM and `project.yaml`; every number in the note is printed by it. Sensor figures were checked against the Sensirion SPS30 datasheet v2.0 (June 2023) with WebFetch.
- `cad/src/model.py`: parametric build123d model (rounded shells with the joint, three screw bosses, inlet and outlet slots, screen, sensor with its ports over the slots, controller, motor, LED light pipe, carrier board with USB-C, cell, clip, plus the wearer interface parameters). Exports `cad/step/` and `cad/stl/` for `dustbadge-assembly`, `front-shell` and `rear-shell`. No part interferences.
- `cad/src/sheets.py` and `cad/drawings/DBG-DWG-001.svg`, `.pdf`, `.png`: general arrangement at Rev P1, 1:1, marked "CONCEPT, NOT FOR FABRICATION" and "PRELIMINARY, NOT FOR FABRICATION". DBG-DWG-001 was free because the concept blueprint is DBG-DWG-010.
- `bom/bom.csv` (12 lines, all priced with a supplier or supplier type, $88.00 against $90) and `bom/bom-notes.md`.
- `cad/src/concept_media.py` now builds from the model; all of `media/` was re-rendered and every image checked. The kit's cutaway cut at the mean part center, which fell on the outlet slot and hid the screen, so the script now cuts on the inlet plane itself (project-side; the kit is unchanged). The exploded view's LED and screen offsets were moved so their callouts no longer sit on the front shell.
- DBG-PRB-001, DBG-PRC-001 and DBG-REQ-001 revised to v0.3; `README.md` (TRL badge, numbers, links, one sun safety line; required sections kept in order) and `project.yaml` (`trl: 3`, `trl_target: 3`, evidence list) updated. PDFs rebuilt in `docs/pdf/`.

Design changes found necessary by the calculations: an SHT4x-class humidity and temperature sensor on the carrier board, because R11 requires a humidity flag and the TRL 2 design had no way to sense humidity; and a charger with a cell thermistor input, because nothing enforced the 0 to 45 °C charging rule. Together they add $3. The TRL 2 precis quoted the PM2.5 precision (±5 µg/m³ plus 5 %) for PM4; the datasheet gives ±25 µg/m³ below 100 µg/m³ for PM4, and the precis is corrected. R8 is restated to apply to the inlet (a clarification, not a relaxed target).

### Requirement status (DBG-CAL-001, Table 6)

4 not met, 1 at risk, 1 not verifiable at TRL 3, 5 met on paper, 4 met by design.

| ID | Status | Key number |
| --- | --- | --- |
| R2 Range | **Not met** | 0 to 1 mg/m³ against 5 mg/m³; the RCS limit is in range only for silica fractions of 5 % or more; over-range minutes flagged and counted |
| R3 Accuracy | **Not met** on paper | ±34 % for quartz-rich stone at the action level (the 8 h filter collects 0.037 mg); ±21 to ±29 % for a quarry at 10 % silica; ±22 % with a 4.2 L/min, two-shift reference. Error terms assumed |
| R11 Site conditions | **Not met** in full sun above about 42 °C | Shell about 63 °C at 45 °C in full sun (sensor limit 60 °C); best performance only to 40 °C and 80 % RH |
| R14 Hazardous atmospheres | **Not met**, out of scope | Must be labeled not for gassy mines or explosive atmospheres |
| R7 Run time | At risk | 13.3 h typical at 25 °C; 11.3 h at the 65 mA maximum or at 0 °C; worst case needs about 1,880 mAh |
| R10 Drop and ingress | Not verifiable at TRL 3 | 750 to 1,500 g on a 1.5 m drop; sensor needs 194 to 387 N of retention |
| R6, R8, R9, R12, R15 | Met on paper | Alert logic correct in five scenarios (one early warning); inlet 242 mm from nose and mouth; 111.8 g, 64 x 52 x 33 mm; 182 shifts in flash; $88.00 of $90 |
| R1, R4, R5, R13 | Met by design | PM4 proxy (its size cut is offset both ways for quartz); labeled RCS estimate; 1 s readings; worker-held data |

### Decisions recorded (DBG-DDR-001)

Adopted as recommended for TRL 3 under Amish's 2026-09-25 instruction, open for his review (now "Decided by Amish, 2026-09-25: go with recommendation", DBG-DDR-002): D1 SPS30-class sensor; D2 respirable dust always, RCS only as a labeled estimate; D3 US OSHA and MSHA defaults, configurable; D4 continuous sampling; D5 worker-owned data, never used for discipline; D6 surface quarries and stone fabrication first, underground coal and explosive atmospheres excluded; D7 downward screened inlet, yellow front shell, spring clip with strap loop. No budget change, pitch or problem rewording was recommended, so `budget_usd` stays at $90 and the pitch and problem lines are unchanged.

### Still awaiting Amish

Status update: items 3 to 6 are now "Decided by Amish, 2026-09-25: go with recommendation" (DBG-DDR-002, D8 to D11). Items 1 and 2 had no recommendation and stay "Proposed, awaiting Amish"; the budget figure in item 3 is a new open item (O3).

1. **O1, first co-design partner.** No recommendation was made.
2. **O2, how a site silica fraction is obtained.** DBG-PRB-001 proposed one filter sample per site and task analyzed by a partner laboratory; it was not in the TRL 2 review list, so it was not adopted.
3. **New, cell size (R7).** Options: (a) keep 1,500 mAh and accept R7 at risk; (b) a 1,900 to 2,000 mAh cell up to 11.5 mm thick, which fits the shells, adds about 8 g (119.8 g, 0.2 g under R9) and about $3 (about $91, $1 over `budget_usd`). Recommendation: (b), with the budget question for Amish. Not applied.
4. **New, R3 accuracy.** Options: (a) keep ±25 % and require a 4.2 L/min cyclone over two shifts for low-dust, high-silica sites (±22 % on paper); (b) relax R3 to ±35 % at dust levels below 100 µg/m³; (c) both. Recommendation: (a). Not applied.
5. **New, sun exposure (R11).** Options: a lighter shell color, a vented sun hood, or a use rule to wear the badge shaded above 40 °C. Recommendation: the use rule now, and a lighter shell tested at a later TRL. Not applied beyond a safety line.
6. **New, range (R2).** Options: accept the 1 mg/m³ range with the over-range flag (adopted in the firmware logic as a fail-safe), or a wider-range sensor, likely over budget. Recommendation: accept with the flag for the first sectors in D6.

### Cross-repo note (CalRig)

The TRL 2 recommendation for D1 said to characterize the SPS30 above 1 mg/m³ on CalRig. CalRig's TRL 2 design (CLR-PRC-001 v0.2, and its own review item 4) uses incense smoke decaying from 300 to 5 µg/m³ and says results will not transfer directly to mineral dust. The two are inconsistent: CalRig can serve DustBadge only for badge-to-badge and drift checks at low levels. Characterization above 1 mg/m³ with mineral dust needs a dust generator or a partner laboratory. The badge (64 x 52 x 33 mm) fits CalRig's 400 x 300 x 300 mm chamber. CalRig was not edited.

### Safety concerns

- False reassurance remains the main hazard. R3 is not met on paper at low dust levels, and the sensor under-sees coarse grains, so a low reading must never be read as safe air. Silica stays a labeled estimate.
- Heat: in full sun above about 42 °C the shell passes the sensor's 60 °C limit and typical LiPo discharge limits. A safety line was added to the precis and README.
- Lithium cell: charging is now blocked outside 0 to 45 °C by the thermistor charger; still never charge while worn.
- Not intrinsically safe; must be labeled against use in gassy mines or explosive atmospheres.
- Exposure logs are health-related personal data (D5).

### Gaps and notes

- Citations: the SPS30 datasheet figures were verified by WebFetch; the other citations were not listed as unchecked and were not re-fetched.
- Every error term in the R3 budget, the thermal coefficients and the drop crush distance are assumptions that only tests can settle.
- The kit's cutaway cuts at the mean part center; this repo now cuts on its own plane in `concept_media.py`. Worth fixing in the kit.
- The flow diagram content is unchanged from TRL 2.
- Existing material beyond TRL 3: `build-log/README.md` (scaffold) is present, untouched and not extended. No test, build or firmware material exists; the alert logic lives only in the calculation script.

### Recommended next step

TRL 4 is on hold by Amish's instruction; this repo stops at TRL 3. Amish's review is needed on D1 to D7 and on items 1 to 6 above, especially the cell size and budget. For the record only, TRL 4 would need: a bench build of the badge; a lab test report (TST, `environment: lab`) of run time at temperature, sensor response to mineral dust against a gravimetric reference including above 1 mg/m³, humidity and spray bias, shell temperature under a solar lamp, and drop and splash; and build log entries. None of this has been started.

## Session 2026-09-25: recommendations accepted

On 2026-09-25 Amish wrote: "i accept all your recommendations, go with them across all repos." Every item with a recommendation is now "Decided by Amish, 2026-09-25: go with recommendation", recorded in `docs/decisions/0002-recommendations-accepted.md` (DBG-DDR-002 v0.1). TRL stays at 3.

### Decisions applied and what changed

- **D1 to D7** (DBG-DDR-001 and the TRL 2 list): SPS30-class sensor, silica as a labeled estimate, US defaults, continuous sampling, worker-owned data, surface quarries and stone fabrication first, downward screened inlet with yellow shell and clip. Wording only; DBG-DDR-001 v0.1 to v0.2.
- **D8, cell size (R7):** option (b). Cell 1,500 mAh, 10 mm, 30 g to 2,000 mAh, 11.5 mm, 38 g in `cad/src/model.py` (STEP and STL re-exported, no interferences). Worst-case run time 9.6 h to 12.8 h; typical 13.3 h to 17.7 h; charge 3.4 h to 4.2 h; mass 111.8 g to 119.8 g; BOM line 8 $10.00 to $13.00, total $88.00 to $91.00 against $90.
- **D9, R3 accuracy:** option (a). ±25 % kept; a 4.2 L/min cyclone over two shifts required at low-dust, high-silica sites. Quartz-rich stone ±34 % to ±22 % (factor per task); shared-factor case ±39 % to ±30 %; quarry unchanged at ±21 to ±29 %.
- **D10, sun (R11):** use rule, wear shaded above 40 °C ambient in full sun. Worst shell temperature 62.8 °C to 57.8 °C, 2.2 K under the 60 °C limit. Added to R11, the precis safety note, the README and the GA notes. The lighter shell test is TRL 4, on hold.
- **D11, range (R2):** accepted. R2 restated from 0 to 5 mg/m³ to 0 to 1 mg/m³ with over-range minutes flagged and counted.
- `budget_usd` unchanged at $90; no pitch or problem rewording was recommended, so `project.yaml` only gains DBG-DDR-002 in `trl_evidence`.
- Documents: DBG-PRB-001 v0.4, DBG-PRC-001 v0.4, DBG-REQ-001 v0.4, DBG-CAL-001 v0.2 (script rerun, every table updated), DBG-DDR-001 v0.2, new DBG-DDR-002 v0.1; DBG-DWG-001 Rev P1 to P2 (cell note and sun rule); `bom/bom.csv` and `bom/bom-notes.md`; media regenerated from the model (key figures updated; the LED's exploded offset moved so its callout clears the front shell); all PDFs rebuilt.
- README: new "What sparked the idea" (MSHA's 2014 coal dust rule and the continuous personal dust monitor, required from February 1, 2016, which gives coal miners in-shift feedback that silica-exposed workers lack), replacing the text about a portfolio review. DBG-PRB-001 had no such attribution.
- Job 2: all generated files re-rendered so they show designmolecule.com; superseded PDFs removed from `docs/pdf/`.

### Requirement status (DBG-CAL-001 v0.2)

2 not met, 2 at risk, 1 not verifiable at TRL 3, 6 met on paper, 4 met by design (was 4, 1, 1, 5, 4).

| ID | Status | Key number |
| --- | --- | --- |
| R14 Hazardous atmospheres | **Not met**, out of scope | Not intrinsically safe |
| R15 Cost | **Not met** (was met) | $91.00 against $90 (O3) |
| R3 Accuracy | At risk (was not met) | ±21 to ±22 % with a factor per task; ±29 to ±30 % with a shared factor |
| R11 Site conditions | At risk (was not met) | Shell at most 57.8 °C under the use rule; relies on the wearer |
| R10 Drop and ingress | Not verifiable at TRL 3 | Cell now needs 280 to 559 N of retention |
| R2, R6, R7, R8, R9, R12 | Met on paper | 1 mg/m³ with flag; five alert scenarios; 12.8 h worst case; 242 mm; 119.8 g (0.2 g margin); 182 shifts |
| R1, R4, R5, R13 | Met by design | Unchanged |

### Still awaiting Amish

1. **O1, first co-design partner.** No recommendation.
2. **O2, how a site silica fraction is obtained where no laboratory is near.** No recommendation.
3. **O3, budget figure for the larger cell.** $91.00 against $90; no recommended figure, so `budget_usd` stays at $90 and R15 is not met. **Decided by Amish, 2026-09-26: budget set to $91** (DBG-DDR-002).

### Cross-repo actions

- **CalRig:** D1's recommendation to characterize the SPS30 above 1 mg/m³ on CalRig cannot be done with CalRig's incense-smoke chamber (5 to 300 µg/m³). CalRig's documents should say it serves DustBadge only for badge-to-badge and drift checks at low levels; mineral dust above 1 mg/m³ needs a dust generator or partner laboratory. CalRig was not edited from this repo.

### Safety

Unchanged hazards (false reassurance, heat, lithium cell, not intrinsically safe, personal data). The sun use rule lowers the heat risk only if the wearer follows it; the badge cannot enforce it. The heavier cell raises the retention load in a drop.

### TRL 4

TRL 4 remains on hold by Amish's instruction. Sensor characterization with mineral dust, the lighter shell under a solar lamp, drop and spray tests, a bench build, buying parts and firmware beyond a sketch are recorded as decided where recommended but not started.

## Session 2026-09-26: budget approved

Amish wrote on 2026-09-26: "i approve all the budget items." Budget set to $91 to cover the priced BOM: decided by Amish, 2026-09-26. This closes O3.

- `project.yaml` `budget_usd` $90 to **$91**. The priced BOM is unchanged at $91.00 (12 lines).
- R15 (cost): target $90 to $91; status **Not met to Met on paper**. Requirement status is now 1 not met (R14, out of scope), 2 at risk (R3, R11), 1 not verifiable at TRL 3 (R10), 7 met on paper, 4 met by design.
- Files changed: `project.yaml`, `README.md`, DBG-PRB-001 v0.5, DBG-PRC-001 v0.5, DBG-REQ-001 v0.5, DBG-CAL-001 v0.3 (`sizing.py` rerun), DBG-DDR-002 v0.2, `bom/bom-notes.md`, `cad/src/concept_media.py` (blueprint key figure); media and PDFs regenerated, temporary `media/_views*` folders deleted.
- Still awaiting Amish: O1 (co-design partner) and O2 (site silica fraction without a nearby laboratory). `trl: 3` and `trl_target: 3` are unchanged; TRL 4 remains on hold.

## Session 2026-09-26: product appearance model and photoreal renders

Amish chose this repo for the first batch of product renders on 2026-09-26. This session adds an appearance model for photoreal renders. It does not change the design, the BOM, the calculations or `cad/src/model.py`.

### What was added

- `cad/src/product_model.py`: `product_parts()` (28 parts: 11 shell, 10 internal, 3 accessory, 4 context), `TITLE` and `RENDER_VIEWS` (hero, exploded and worn). All main dimensions and interfaces come from `PARAMS`, `derived()` and `build_parts()` in `model.py`.
  - Filleted hi-vis yellow front shell (3 mm front perimeter) and dark rear shell (2.5 mm rear perimeter), with 0.6 mm fillets either side of the shell joint and a TPU gasket band showing in the parting line.
  - Ribbed grip texture on both side faces of the front shell.
  - Clear acrylic front window over the particle sensor, showing a sensor fan and a printed label on the sensor face.
  - Lit red alert light pipe (emissive) in a dark bezel; printed status label with three level bars.
  - Three M2 screws in the rear face; stainless inlet screen in the bottom inlet slot.
  - Internals rendered as finished parts: controller module with shield can, vibration motor, carrier board with components, 2,000 mAh pouch cell with label.
  - Stainless spring clip (riveted base leaf, hinge barrel, tongue with the strap-loop slot) inside the `model.py` clip envelope.
  - Accessory: webbing lanyard through the strap loop with a crimp and a teal breakaway buckle.
  - Context for the worn view: curved fabric chest panel with a harness strap, stitching and reflective tape.
- `README.md`: hero image now points to `media/render-hero.png`, with a link to `media/render-exploded.png`. The render files are produced separately.

### Differences from model.py (each Proposed, awaiting Amish)

1. **Front window over the sensor (30 x 24 mm).** `model.py` has a solid front face. The window shows the sensor for the renders but adds a sealing joint that bears on R10 (drop and ingress). Recommendation: keep it in the renders only; decide at TRL 4 whether to adopt it, and if so, add it to BOM line 1 and the drawing.
2. **Visible sensor fan.** An SPS30-class sensor encloses its fan; the recess and fan on the sensor face are illustrative. Recommendation: keep, and describe it as illustrative in any caption that calls out the fan.
3. **Rear screws at the three boss positions.** `model.py` has the bosses but no shell closure fasteners. Recommendation: adopt three M2 screws through the rear shell into the front bosses (BOM line 11 already covers M2 screws).
4. **Side grip ribs stand 0.6 mm proud**, so the rendered width is about 65.2 mm against 64 mm. Recommendation: accept for appearance; if adopted, recess the ribs so the 64 mm envelope holds.
5. **Lanyard and breakaway buckle** have no BOM line. A breakaway is the safer choice near rotating machinery. Recommendation: add an optional BOM line (about $1) at TRL 4, subject to the budget Amish approved.
6. **TPU gasket shown as a visible band.** BOM line 9 lists the gasket; `model.py` does not model it. Recommendation: accept as shown.

### Status

Appearance only: no tolerances, no fabrication detail, no PCB layout. `trl` and `trl_target` stay at 3, and TRL 4 remains on hold.

## Session 2026-09-27: kit 1.5.0 and image quality

- Kit 1.5.0 synced: STANDARDS v1.5 (sections 12 to 15: product renders, storefront images and image quality, public release, authorship and signing), `.kit/cards.py`, `.kit/image_qc.py`, `.kit/release_gate.py`, issue templates, and the `/render-product` and `/release` commands. `CLAUDE.md` now matches `.kit/CLAUDE.md`.
- Every `media/render-*.png` recaptioned from its original render with the new layout: the title, concept label and repository sit in a band above the render and the view note in a band below it, each line wrapped to the image width, so no text overlaps other text or the render or runs off the image. `media/card.png` and `media/social-preview.png` regenerated with the same rules.
- `python .kit/image_qc.py` and `python .kit/release_gate.py` pass. trl stays 3.

## Session 2026-09-30: kit 1.7.0, design for construction and the illustrated build plan

Under Amish's 2026-09-30 instruction ("If you are realising that the design cannot be built as per concept - fix the design assumptions to match and be physically feasible as you draw the illustrations"), the model was checked for how every part is made and fixed, made buildable, and the illustrated build plan written. Kit 1.7.0 installed; `CLAUDE.md` now matches `.kit/CLAUDE.md`. `trl` stays 3; `design_state: constructable`.

### Design changes made for construction (DBG-DDR-003, Draft, open for Amish's review)

1. **Shell closure:** three 4.5 mm tubes in the rear shell and three M2 x 20 thread-forming screws from the rear face (4.2 mm counterbores) clamp the rear shell, gasket and board onto the front bosses, which now reach the board (they stopped 0.2 mm short).
2. **Gasket:** a flat printed TPU frame, 1 mm squeezed; the rear shell is 1 mm shallower (13 mm) so the badge stays 30 mm deep.
3. **Sensor port seals:** two printed TPU seals (0.7 mm inlet, 1.0 mm outlet) join the sensor's ports to the floor slots; before, the fan could draw air from inside the badge.
4. **Inlet screen:** a 16 x 11 x 0.3 mm mesh square on the inner floor, held by the inlet seal (was a 1.2 mm screen loose in the slot; BOM line 2 was 30 x 8 mm).
5. **Sensor retention:** two 1.2 mm stop ribs in the front shell, 0.2 mm above the sensor.
6. **Electronics placed:** charger module with USB-C on the board's right strip; boost module, humidity breakout and vibration motor taped inside the front face; USB-C opening moved 16 to 18.1 mm right and enlarged to 9.6 x 3.8 mm; humidity vent moved from under the sensor (8 mm right) to 18.5 mm right, 3 mm behind the front face; controller moved 0.2 mm to clear the wall.
7. **Carrier board:** 56 x 44 to 59 x 47 mm with 1.5 mm corner cuts, so the screw holes no longer break its edges; a notch for the cell lead.
8. **Cell retention:** four locating ribs on the rear shell.
9. **Clip fixing:** two M2 x 8 screws through the clip's base leaf into two bosses above the cell.
10. **Light pipe:** printed clear PETG with an inside flange and a pocket for the 3 mm LED on leads.

The model now runs 43 constructability checks (`python cad/src/model.py --check`); all pass.

### Results and knock-ons

- Mass 119.8 to **119.9 g**; R9 margin 0.2 to **0.1 g** (gasket and seals now from the model volume in TPU). Cost unchanged at an estimated **$91.00** against the $91 value-engineering target; BOM specifications of lines 2, 6, 7, 9, 10 and 11 updated, no price changed. Requirement status unchanged: 1 not met (R14, out of scope), 2 at risk (R3, R11), 1 not verifiable at TRL 3 (R10), 7 met on paper, 4 met by design.
- Documents: DBG-CAL-001 v0.4, DBG-PRC-001 v0.6, DBG-REQ-001 v0.6, new DBG-DDR-003 v0.1, new DBG-BLD-001 v0.1 (`docs/05-build-plan.md`), new DBG-DEC-001 v0.1 (`docs/06-design-decisions.md`). DBG-DWG-001 Rev P3 to **P4**; making sketches DBG-DWG-101 to 108 added.
- Pictures: `cad/src/build_plan_media.py` writes the overview, 8 making sketches, 6 joint close-ups, 9 step pictures, the bottom-face layout and the wiring diagram. STEP, STL, `media/model.glb` and the concept media were regenerated from the model; the exploded view's key now names one part per BOM line.
- `README.md`: build plan link and a "Building the prototype" section. `project.yaml`: `design_state: constructable`, the DDR, build plan, register and overview picture added to `trl_evidence`.

### Proposed, awaiting Amish (all in DBG-DEC-001)

- Review of the design-for-construction changes (DBG-DDR-003).
- A1 cell swelling allowance (0.7 mm, about 6 %); A2 on and off control (no switch in the concept); A3 the 0.1 g mass margin.
- O1 co-design partner and O2 site silica fraction, still open.
- Product render differences 1, 2, 4 and 5 of 2026-09-26 (front window, visible fan, grip ribs, lanyard). Items 3 (rear screws) and 6 (gasket band) are now part of the design through DBG-DDR-003.

### Stale images (made on Amish's Mac, not regenerated here)

`media/render-hero.png`, `media/render-exploded.png`, `media/render-worn.png`, `media/card.png` and `media/social-preview.png` show the concept: the USB-C opening and humidity vent have moved, the clip now has two screws and the gasket is a flat 1 mm band. They need regenerating with `/render-product` on the Mac. `cad/src/product_model.py` still runs against the new model.

### Safety

The lithium cell now has a located, swappable position with a 0.7 mm swelling allowance (open decision 2), a polarity check and charge-stop checks before first charge (build plan section 6). The badge still has no switch (open decision 3). Not intrinsically safe; the readings remain research estimates.

### Kit notes

- The making sketches round dimensions to whole millimetres, so the 0.3 mm screen shows "0" and the 1.6 mm board "2"; the sketch notes and the build plan give the true sizes. The light pipe flange was made 6 mm (not 6.5 mm) so its sketch reads true. A finer dimension format in `.kit/drawing.py` would help small parts.
- `build123d.scale` keeps a located box at its original position, so scaled pictures misplace simple parts; `cad/src/build_plan_media.py` scales with an OCP transform instead.

### Recommended next step

Amish reviews DBG-DDR-003 and the open decisions in DBG-DEC-001. TRL 4 (buying parts and building to DBG-BLD-001) stays on hold until he says otherwise.

## Session 2026-10-01: Dr. Geeti Chadha added; BioMedical (healthcare) area

Instruction from Amish, 2026-10-01: "yes add Dr. Geeti Chadha to breathebox and dustbadge and make those both healthcare projects". Matched to the TremorTrace worked example.

### What was done

- `project.yaml`: `area` changed from Mining to BioMedical, the portfolio's healthcare area; tags now lead with `biomedical`, keeping `mining` after it.
- `CONTRIBUTORS.md`: row added for Dr. Geeti Chadha, Contributor.
- `README.md`: area line now BioMedical; Credits name Dr. Geeti Chadha as contributors; the concept rationale and the Safety section state that DustBadge is a research and educational prototype, not a medical device.
- `CITATION.cff`: `biomedical` keyword added. Dr. Geeti Chadha is not added to the authors, matching TremorTrace, where only Amish is listed.
- `docs/01-problem.md` (DBG-PRB-001 v0.7) and `docs/02-concept.md` (DBG-PRC-001 v0.8): the not-a-medical-device statement added to the existing scope and safety wording.
- `docs/06-design-decisions.md` (DBG-DEC-001 v0.3): the decision recorded under "Decisions made".
- `docs/pdf/`: PDFs of the changed controlled documents rebuilt.

### Wording

No clinical claims were found that needed softening: the documents already call the badge a screening tool, not a compliance instrument, that estimates exposure and does not replace sampling, controls or respirators. The changes add the not-a-medical-device statement only. Design, requirements, numbers and safety content are unchanged.

### Stale media (on Amish's Mac; not regenerated here)

`media/card.png` and `media/social-preview.png` show the area (Mining) and must be regenerated on Amish's Mac with `python .kit/cards.py .`.

### Proposed, awaiting Amish

- None new. The `pitch` and `problem` lines in `project.yaml` are unchanged.

### Recommended next step

Regenerate the card and social preview on the Mac, then continue with the open items in DBG-DEC-001.

## Session 2026-10-02: open decisions decided by Amish

Authority: Amish, 2026-10-02: "i approve your recommendations for all 555 open decisions." The recommendations approved are those written for the open decisions in the design decisions register. No model, BOM quantity or price, or picture was changed; where a decision needs one, it is listed below as a follow-up. `trl` and `trl_target` stay at 3. No commit or push.

### Decisions recorded

10, all moved to "Decisions made" in `docs/06-design-decisions.md`, dated 2026-10-02:

1. Design for construction (DBG-DDR-003) accepted: P1 to P10, with the TRL 4 drop test also checking that the boost module, humidity board and motor stay on their foam tape.
2. Cell swelling: the 0.7 mm allowance only for bench work with nobody wearing the badge; before anyone wears it, the badge is deepened 1 mm with a foam pad and R9 is relaxed to 122 g.
3. On and off: firmware only, with a low-voltage cutoff above the cell protection threshold.
4. R9 mass margin: accepted, weighed at TRL 4; limit 122 g with the deeper shell.
5. First co-design partner: first candidate type a university industrial hygiene group sampling respirable crystalline silica (for example one linked to a NIOSH Education and Research Center), with a stone fabrication shop or surface quarry as the site.
6. Site silica fraction: two or three cyclone filter samples per site to an accredited laboratory (X-ray diffraction, NIOSH Method 7500); no silica estimate until a site fraction exists.
7. Clear front window: renders only; decided at TRL 4.
8. Sensor fan in the renders: kept, captioned as illustrative.
9. Side grip ribs: appearance only; recessed to keep 64 mm if adopted at TRL 4.
10. Lanyard: optional line at TRL 4, breakaway only.

### Documents changed

- `docs/06-design-decisions.md` (DBG-DEC-001 v0.4)
- `docs/decisions/0003-design-for-construction.md` (DBG-DDR-003 v0.3): accepted; A1 to A3 recorded; status stays Draft
- `docs/decisions/0001-trl2-review-decisions.md` (DBG-DDR-001 v0.3): O1 and O2 decided
- `docs/decisions/0002-recommendations-accepted.md` (DBG-DDR-002 v0.3): O1 and O2 decided
- `docs/02-concept.md` (DBG-PRC-001 v0.9): firmware on and off, swelling rule, silica fraction method, partner candidate, R9
- `docs/03-requirements.md` (DBG-REQ-001 v0.8): R9 relaxed to 122 g; silica fraction assumption
- `docs/04-calcs/01-sizing.md` (DBG-CAL-001 v0.6): R9 target in the requirement table
- `docs/05-build-plan.md` (DBG-BLD-001 v0.3): safety stop S7: bench work only until the deeper shell and foam pad are fitted

### Follow-up actions to carry approved decisions into the design

1. Decision 1 (docs): Add to the TRL 4 drop test (when a test plan is written) a check that the boost module, humidity board and motor stay on their foam tape; record it in the build plan's first checks if Amish wants it there now.
2. Decision 2 (model): Model the worn version: rear shell 1 mm deeper with a foam pad behind the cell, in `cad/src/model.py`, with the constructability checks re-run.
3. Decision 2 (drawings): Regenerate DBG-DWG-001 and the rear shell making sketch for the deeper shell.
4. Decision 2 (bom): Add the foam pad to the BOM with a price.
5. Decision 2 (calcs): Add the deeper shell and foam pad to the mass estimate (about 1.5 g) and re-judge R9 against 122 g and R15 against the value-engineering target in DBG-CAL-001.
6. Decision 3 (calcs): Write the low-voltage cutoff, set above the cell protection threshold, into the firmware sketch and its threshold into DBG-CAL-001.
7. Decision 8 (pictures): Caption the sensor fan as illustrative in the photoreal renders (`media/render-*.png`) when they are regenerated on Amish's Mac.
8. Decision 10 (bom): At TRL 4, add an optional breakaway-only lanyard line to the BOM (about USD 1).

### Points found in the review

- The USD 91 value-engineering target was set on 2026-09-26 to equal the priced BOM, so 'on target' carries no information; any addition (the lanyard, a foam pad) goes over it.
- Items 2 and 4 are linked: the swelling allowance and the R9 mass margin cannot both be decided as recommended in the register, since (b) on item 2 breaks R9.
- Decided on 2026-10-02 together as linked: decision 2 takes option (b) before anyone wears the badge, and decision 4 moves the R9 limit to 122 g with it.

## Session 2026-10-02: approved follow-ups carried out

Authority: Amish, 2026-10-02, approved every follow-up action from the open-decision sign-off. `trl` and `trl_target` stay at 3; `budget_usd` is unchanged at 91. No commit or push.

### Follow-ups

1. Decision 1, drop test check on the foam-taped parts: not done, TRL 4 test plan work (no test plans at TRL 3). Not added to the build plan's first checks either, pending Amish.
2. Decision 2, model: done. `cad/src/model.py` now models the worn version: rear shell 1 mm deeper (rear face 1 mm further back, tubes, bosses and cell ribs lengthened to suit), a 40 x 24 x 1 mm foam pad on the rear wall, 0.5 mm clear of the cell. Constructability checks: 47 of 47 pass (4 new for the pad). STEP and STL regenerated.
3. Decision 2, drawings: done. DBG-DWG-001 now Rev P5; DBG-DWG-102 (rear shell making sketch), overview, joint pictures, steps 8 and 9, bottom-face picture and the concept media regenerated.
4. Decision 2, BOM: done. Line 13, foam pad, USD 0.50 (basis in the BOM note: a 1 mm adhesive-backed sheet at about USD 6 to 8 gives many pads; allowance for a part-used sheet). Total USD 91.50.
5. Decision 2, calcs: done. Mass 120.7 g (the worn version adds 0.8 g, not the 1.5 g first estimated), margin 1.3 g to the 122 g limit, so R9 stays met. R15 re-judged: not met.
6. Decision 3, low-voltage cutoff: threshold done in DBG-CAL-001 and `sizing.py` [A7]: 3.30 V at the cell under load, restart above 3.50 V, against an assumed 2.75 V protection cut-out. The firmware sketch part is not done: the repo has no firmware (TRL 3 cap), so the figure is recorded for the sketch to use later.
7. Decision 8, caption the fan as illustrative: done in the render scenes (all three view notes in `cad/src/product_model.py` now say so); the captions are applied when the renders are made on Amish's Mac.
8. Decision 10, optional breakaway lanyard line: not done, TRL 4 (about USD 1; not in the estimate).

### Requirement status changes

- R15 (cost): met on paper to **not met**, by USD 0.50 (USD 91.50 against the USD 91 target). Value-engineering target: USD 91. Estimated cost of the constructable design: USD 91.50 (USD 0.50 over the target).
- R9 (mass and size): stays met; 120.7 g against 122 g, 64 x 52 x 34 mm with the clip (35.0 mm with the light pipe, exactly the limit).
- No other status changed.

### Documents changed and new versions

DBG-CAL-001 v0.7; DBG-REQ-001 v0.9; DBG-PRC-001 v0.10; DBG-PRB-001 v0.8; DBG-BLD-001 v0.4 (worn version, pad making and step 8, no bench-only wording); DBG-DEC-001 v0.5 (value engineering restated; one decision proposed, awaiting Amish: raise the target to USD 92, or keep USD 91). Also `README.md`, `bom/bom.csv`, `bom/bom-notes.md`, `cad/src/model.py`, `sheets.py`, `build_plan_media.py`, `concept_media.py`, `product_model.py`, `docs/04-calcs/sizing.py`.

### Render scenes

`cad/src/product_model.py` updated to the worn version (rear-side parts moved with the deeper shell, foam pad added). Scenes exported to `/home/claude/renders/dustbadge` for the views hero, exploded and worn, with `dustbadge__jobs.json`. Photoreal images, `card.png` and `social-preview.png` are to be made on Amish's Mac.

### Cross-repo actions

None for other repos.

### Decisions proposed and awaiting Amish

- Value-engineering target: raise to USD 92 (recommended), or keep USD 91 and find USD 0.50, or accept R15 not met.

## 2026-10-02: photoreal renders redone on the constructable design

Rendered with Blender Cycles on Amish's Mac from the updated appearance model; captioned with `.kit/photo_caption.py`; `media/card.png` and `media/social-preview.png` regenerated with `.kit/cards.py`. Views: hero, exploded, worn. image_qc passes. Appearance deviations are those logged above as proposed, awaiting Amish.

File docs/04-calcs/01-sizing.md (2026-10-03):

---
doc_id: DBG-CAL-001
title: DustBadge sizing calculations
project: DustBadge
doc_type: Calculation
version: "0.7"
status: Draft
date: '2026-10-02'
author: Amish Chadha
license: CERN-OHL-S-2.0
revisions:
- version: "0.1"
  date: '2026-09-25'
  author: Amish Chadha
  change: First issue for TRL 3 (power and run time, charging, badge temperature, PM4 against the respirable convention, range, error budget, alert logic, log, breathing zone, mass, drop, cost)
- version: "0.2"
  date: '2026-09-25'
  author: Amish Chadha
  change: "Recommendations accepted by Amish (DDR-002): 2,000 mAh cell, R2 restated, R3 reference rule, R11 sun use rule; results table updated"
- version: "0.3"
  date: '2026-09-26'
  author: Amish Chadha
  change: Budget approved by Amish; budget $91 covers the priced BOM, so R15 is met (DBG-DDR-002 v0.2)
- version: "0.4"
  date: '2026-09-30'
  author: Amish Chadha
  change: "Design made constructable (DBG-DDR-003): shell screws, gasket, port seals, ribs and clip screws added; mass 119.9 g, margin 0.1 g; drop retention paths stated"
- version: "0.5"
  date: '2026-10-01'
  author: Amish Chadha
  change: Budget treated as a value-engineering target
- version: "0.6"
  date: '2026-10-02'
  author: Amish Chadha
  change: 'R9 target 122 g (decided by Amish, 2026-10-02) in the requirement table'
- version: "0.7"
  date: '2026-10-02'
  author: Amish Chadha
  change: 'Worn version in the mass estimate (rear shell 1 mm deeper, foam pad): 120.7 g against 122 g; cost USD 91.50, USD 0.50 over the target, so R15 is not met; low-voltage cutoff threshold added (section A)'
---

# DustBadge sizing calculations

On paper, DustBadge meets ten of its fifteen requirements (six by calculation, four by design), has two at risk, cannot verify one at TRL 3 and misses two (R14 and, by USD 0.50 against the value-engineering target, R15). This version applies the recommendations Amish accepted on 2026-09-25 (DBG-DDR-002). The 2,000 mAh cell (was 1,500 mAh) runs 12.8 h at the sensor's maximum current and 0 °C (was 9.6 h), so R7 moves from at risk to met, at the cost of 8 g and $3. The design for construction (DBG-DDR-003, v0.4 of this note) adds the shell and clip screws, the gasket, the port seals and the locating ribs, which brought the badge to 119.9 g against 120 g and the estimated parts cost to $91.00, $1 over the $90 value-engineering target; on 2026-09-26 Amish set the target at $91 to match the priced BOM (DBG-DDR-002). The worn version decided on 2026-10-02 (v0.7 of this note) deepens the rear shell by 1 mm and adds a foam pad behind the cell: the badge is 120.7 g against the relaxed limit of 122 g, so R9 stays met, but the parts cost is $91.50, $0.50 over the $91 target, so R15 is no longer met. The firmware low-voltage cutoff is set at 3.30 V (section A). R2 is restated to the sensor's 0 to 1 mg/m³ range with over-range minutes flagged and counted, and is met on paper. R3 keeps ±25 % with a 4.2 L/min, two-shift reference at low-dust, high-silica sites: ±21 to ±22 % with a factor per task on the same badge, but ±29 to ±30 % with one factor shared across badges, so it is at risk. R11 now carries the use rule to wear the badge shaded above 40 °C in full sun, which keeps the shell at or below 57.8 °C, under the sensor's 60 °C limit; it is at risk because the rule depends on the wearer and the sensor is outside its best-performance range in sun above about 22 °C. Intrinsic safety (R14) remains not met and out of scope. The TRL 3 calculations had already added a humidity and temperature sensor and a thermistor charger to the TRL 2 concept. Every number in this note is printed by `docs/04-calcs/sizing.py`; the tag in brackets, for example [A3], is the line of that script's output that carries it.

> **Safety:** These are first-principles estimates for a paper proof of concept. They do not show that a worker's air is safe, and they are not a substitute for co-located filter sampling, chamber checks or electrical safety checks on the lithium cell. See DBG-PRC-001, Safety.

## Scope and method

The note checks every requirement in DBG-REQ-001 v0.4 against the design in DBG-PRC-001 v0.4 and the parametric model `cad/src/model.py`. The script imports the model's `PARAMS`, derived dimensions and mass breakdown, so the envelope, shell volumes, inlet position and cell space used here are the ones in the STEP files and in drawing DBG-DWG-001. It also reads `bom/bom.csv` and `budget_usd` in `project.yaml`. Run it from the repo root with `python docs/04-calcs/sizing.py`.

The design case is a worker in a surface quarry or a stone fabrication shop on a 12 h shift, badge worn at the collar or on an upper harness strap, ambient 0 to 45 °C, 10 to 90 % RH, US OSHA and MSHA limits by default (decision D3 in DBG-DDR-001, decided by Amish on 2026-09-25 in DBG-DDR-002).

## Assumptions

*Table 1. Main assumptions.*

| Area | Assumption | Basis |
| --- | --- | --- |
| Particle sensor | 45 to 55 mA typical and 65 mA maximum at 4.5 to 5.5 V; 0 to 1,000 µg/m³; PM4 precision ±25 µg/m³ below 100 µg/m³ and ±25 % from 100 to 1,000 µg/m³; drift 1.25 µg/m³ or 1.25 % per year; best performance at 10 to 40 °C and 20 to 80 % RH; operating -10 to 60 °C and 0 to 95 % RH; new readings every second; 26.3 g | [Sensirion SPS30 datasheet, v2.0, June 2023](https://sensirion.com/media/documents/8600FF88/64A3B8D6/Sensirion_PM_Sensors_Datasheet_SPS30.pdf) |
| Electronics | 5 V boost 85 % efficient; controller, BLE and humidity sensor 3 mA from the cell; vibration motor 80 mA at 3 V, 20 alerts of 2 s per shift | Typical module figures; to confirm by measurement at a later TRL |
| Cell | 2,000 mAh, 3.7 V, 11.5 mm thick, 38 g (DBG-DDR-002 D8; was 1,500 mAh, 30 g); 80 % usable; 85 % of capacity at 0 °C; charged at 500 mA; protection cut-out assumed at 2.75 V | Typical LiPo data; the protection value is to be taken from the bought cell's datasheet |
| Badge temperature | Combined surface coefficient 10 W/(m²·K); solar absorptance of yellow PETG 0.45; 1,000 W/m² on the front face; rear face against the wearer treated as adiabatic | Screening values (assumed) |
| Reference sample | Cyclone at 2.5 L/min for 8 h; at low-dust, high-silica sites a 4.2 L/min cyclone over two shifts (DBG-DDR-002 D9); weighing and blank uncertainty 0.010 mg per filter; gravimetric method ±10 % | Assumed typical values |
| Error terms | Site factor change between days and tasks ±10 % (factor per task) or ±20 % (per site); position and screen ±10 %; humidity below 80 % RH ±5 %; non-linearity after the site factor ±10 %; badge-to-badge after a CalRig check ±10 % | Assumed; each to be measured |
| Silica fractions | 10 % for a typical quarry, 80 % for quartz-rich engineered stone | Assumed for illustration; a site filter sample sets the real value |

## A. Power and run time (R7)

The 2,000 mAh cell holds 7.40 Wh, of which 5.92 Wh is usable, and 5.03 Wh at 0 °C [A1]. The motor adds only 2.7 mWh per shift [A2]. The sensor's fan and laser dominate.

*Table 2. Run time by sensor current [A3].*

| Sensor current | Power from the cell | Run time at 25 °C | Run time at 0 °C |
| --- | --- | --- | --- |
| 45 mA (typical, low) | 276 mW | 21.5 h | 18.2 h |
| 55 mA (typical, high) | 335 mW | 17.7 h | 15.0 h |
| 65 mA (maximum) | 393 mW | 15.0 h | 12.8 h |

Covering 12 h at the maximum current and 0 °C needs about 1,880 mAh [A4], or about 1,600 mAh at 25 °C [A5]. The 2,000 mAh cell, 11.5 mm thick, leaves 1.5 mm to the rear wall in the worn version (0.5 mm in the bench version), of which the 1 mm foam pad takes 1.0 mm, and a 122 mAh (7 %) margin over the worst case [A6]. With the 1,500 mAh cell of v0.1 the run time was 13.3 h typical and 9.6 h in the worst case, and R7 was at risk. R7 is now met on paper.

The firmware stops the cell short of its own protection cut-out (decision of 2026-10-02, DBG-DDR-003 A2): the controller switches the boost off through its enable input and sleeps when the cell reaches 3.30 V under load, which is 0.55 V above the assumed protection cut-out of 2.75 V, and it restarts the boost only above 3.50 V or on USB power [A7]. The cutoff does not change the 80 % usable fraction behind the run times above; that is an assumption to confirm against the bought cell's discharge curve. The threshold is the figure a future firmware sketch must use; no firmware exists at TRL 3.

## B. Charging

At 500 mA (0.25 C) the 2,000 mAh cell charges in about 4.2 h, 3.2 h at constant current plus about 1 h of taper [B1] (3.4 h for the 1,500 mAh cell), so a badge charged after a 12 h shift is still ready for the next. The charger module now takes the cell's thermistor so that charging stops outside 0 to 45 °C; at TRL 2 this rule was written but nothing enforced it.

## C. Badge temperature (R11)

In shade the electronics warm the badge by 3.3 K. In full sun on the front face the rise is 17.8 K: the shell reaches about 48 °C at 30 °C ambient and about 63 °C at 45 °C ambient [C1]. The sensor's 60 °C operating limit is therefore passed in full sun above about 42 °C ambient, and its 40 °C best-performance limit above about 22 °C ambient [C2]. The sensor draws outside air through its own path, so the air it measures stays near ambient, but its electronics and the cell sit at shell temperature. Without a rule, R11 is not met in full sun at 45 °C. Amish accepted the use rule on 2026-09-25 (DBG-DDR-002 D10): wear the badge shaded, under a vest flap or out of direct sun, when the ambient temperature is above 40 °C in full sun. The worst case is then 57.8 °C in full sun at 40 °C, or 48.3 °C shaded at 45 °C, both under the 60 °C operating limit with a 2.2 K margin [C3]. R11 is at risk: the rule depends on the wearer, the margin is small and the screening coefficients are assumed, and in sun above about 22 °C the sensor's electronics are above their 40 °C best-performance limit. A lighter shell tested under a solar lamp is TRL 4 work and is on hold.

## D. PM4 against the respirable convention (R1)

The ISO 7708 respirable convention passes half of particles at 4.0 µm aerodynamic diameter [D1]. For quartz (2.65 g/cm³), geometric and aerodynamic diameters differ by a factor of about 1.6: a 2.5 µm grain is 4.1 µm aerodynamic and about half respirable, and a 4 µm grain is 6.5 µm aerodynamic and only 12 % respirable [D2]. An optical PM4 channel would therefore over-include coarse quartz if it sized it correctly. In practice the SPS30 calculates PM4 from the distribution of the particles it detects best, which are fine, so it tends to under-see coarse grains. The two errors act in opposite directions and neither is known for site dust [D3]. PM4 remains the closest available output, so R1 is met by design as a proxy, and the site factor must absorb the difference.

## E. Working range (R2)

The sensor covers 0 to 1,000 µg/m³. R2 is restated (DBG-DDR-002 D11) to this range with over-range minutes flagged and counted, for the first sectors in D6; the TRL 2 target of 5 mg/m³ was only 20 % covered [E1]. What matters for the alert is where the silica limits fall in dust terms.

*Table 3. Respirable dust at the RCS action level and limit, by silica fraction [E2].*

| Silica fraction | Dust at the 25 µg/m³ action level | Dust at the 50 µg/m³ limit | Limit in range |
| --- | --- | --- | --- |
| 2.5 % | 1,000 µg/m³ | 2,000 µg/m³ | No |
| 5 % | 500 µg/m³ | 1,000 µg/m³ | Yes, at the edge |
| 10 % | 250 µg/m³ | 500 µg/m³ | Yes |
| 30 % | 83 µg/m³ | 167 µg/m³ | Yes |
| 80 % | 31 µg/m³ | 62 µg/m³ | Yes |

For dust with 5 % silica or more the limit lies inside the range, and for 2.5 % or more the action level does [E3]. Above the range, readings are not trustworthy, so the firmware logs an over-range minute at the range limit, flags it and counts it toward the projection at no less than that limit, which makes the badge alert rather than go quiet [E4]. R2 as restated is met on paper. Peaks in quarries and artisanal mines can be far above 1 mg/m³, and the badge will report only that they were over range; for dust below 5 % silica the limit lies above the range, so the badge can say only that the dust was over range, not by how much.

## F. Error budget for the shift average (R3)

A site factor from a co-located filter sample is what turns the optical reading into a respirable dust value. The filter sample itself limits the result at low concentrations: 2.5 L/min for 8 h draws 1.20 m³ of air [F1], so at the action level for quartz-rich stone (31 µg/m³ of dust) the filter collects only 0.037 mg, and a 0.010 mg weighing uncertainty is already 27 %.

*Table 4. Combined uncertainty of the shift average at the action level (root sum of squares) [F2, F3].*

| Case | Dust | Filter mass | Same badge, factor per task | Factor shared across badges, per site |
| --- | --- | --- | --- | --- |
| Quartz-rich stone, 80 % silica | 31 µg/m³ | 0.037 mg | ±34 % | ±39 % |
| Quarry, 10 % silica | 250 µg/m³ | 0.300 mg | ±21 % | ±29 % |
| Quartz-rich stone, 4.2 L/min cyclone over 2 shifts (D9 rule) | 31 µg/m³ | 0.126 mg | ±22 % | ±30 % |

Amish accepted on 2026-09-25 keeping the ±25 % target and requiring a 4.2 L/min cyclone over two shifts at low-dust, high-silica sites (DBG-DDR-002 D9). With that rule the target is met on paper in both cases when the reference is taken on the same badge for each task (±21 % quarry, ±22 % quartz-rich stone), and missed when one factor is shared across badges per site (±29 %, ±30 %) [F2, F3]. Without any site factor the PM4 precision alone is ±25 µg/m³, 80 % of the dust level at the action level for quartz-rich stone [F4]. R3 is at risk. Every term except the sensor's own figures is assumed and must be measured.

## G. Silica estimate and alert logic (R4, R5, R6)

The sensor gives new readings every second; the firmware logs 1 min means, multiplies calibrated PM4 by the site silica fraction to give the RCS estimate, and projects the 8 h TWA as the dose so far plus the last 60 min mean rate for the rest of the shift. The projection starts once 60 min of data exist; before that the badge alerts only on the dose so far and on peaks. A brief peak alert fires when a 1 min mean exceeds 250 µg/m³ RCS, ten times the action level [G2]. Five scenarios on an 8 h shift test the logic [G1].

*Table 5. Alert behavior in five scenarios (RCS, µg/m³) [G1].*

| Scenario | 8 h TWA | Action-level alert | Limit alert | Peak alerts | Correct? |
| --- | --- | --- | --- | --- | --- |
| S1 steady 30 all shift | 30.0 | Minute 60 | None | 0 | Yes |
| S2 background 10, 2 min dry cut at 1,000 each hour | 43.0 | Minute 60 | None | 8 | Yes |
| S3 background 15, one 1 min truck pass at 110 | 15.2 | None | None | 0 | Yes, no nuisance alert |
| S4 background 5 | 5.0 | None | None | 0 | Yes |
| S5 background 10, one 2 min dry cut at 1,000 | 14.1 | Minute 60 | None | 1 | Early warning; the shift ends below the action level |

The logic warns before the limit in every case where the shift ends above the action level, and it ignores a passing truck. S5 shows the cost of projecting: a single heavy cut in the first hour projects over the action level although the shift ends at 14 µg/m³. That is acceptable for a warning, since the same cut repeated each hour gives S2, but workers should be told what the alert means. R4, R5 and R6 are met by design; R6 is also met on paper for these scenarios.

## H. Shift log (R12)

At 16 bytes per minute a 12 h shift takes 11.5 kB, and 30 shifts take 346 kB, 16 % of the module's 2 MB flash, so the badge holds about 182 shifts [H1]. At a conservative 2 kB/s a shift transfers to a phone in about 6 s [H2]. R12 is met on paper.

## I. Breathing zone (R8)

With the badge worn 210 mm below and 70 mm to the side of the nose and mouth, the inlet is 242 mm from them [I1]. The badge center may sit up to 269 mm below the nose and mouth before the 300 mm limit is passed [I2], so a collar or upper-strap position meets R8 and a low shirt pocket may not. R8 is met on paper for the stated mount.

## J. Size and mass (R9)

The printed shells weigh 16.5 g (front) and 16.0 g (rear) from the model volumes. The rear shell was 15.4 g in the bench version; the worn version (decided on 2026-10-02, DBG-DDR-003 A1) deepens it by 1 mm and lengthens its tubes, bosses and locating ribs to suit. The foam pad behind the cell adds 0.2 g. The gasket and the two port seals, from the model volume in TPU, weigh 0.8 g. The sensor (26.3 g) and the 2,000 mAh cell (38 g) are more than half the badge [J1]. The total is 120.7 g (119.9 g in the bench version), 1.3 g under the relaxed 122 g limit and 0.7 g over the former 120 g; the worn version adds 0.8 g, not the 1.5 g first estimated in DBG-DDR-003. The envelope is 64 x 52 x 34 mm including the clip against 75 x 55 x 35 mm [J2, J3]; the light pipe stands 1 mm proud of the front face, so the greatest depth is 35.0 mm, exactly the limit and the same 1 mm that was there in the bench version. R9 is met on paper against 122 g.

## K. Drop and ingress (R10)

A 1.5 m drop reaches 5.42 m/s with 1.78 J. If the shell corner crushes 1 to 2 mm, the mean deceleration is 750 to 1,500 g, so the sensor needs 194 to 387 N of retention and the heavier cell 280 to 559 N (was 221 to 441 N) [K1]. The model now gives each a load path (DBG-DDR-003): the sensor sits on its two port seals, under two stop ribs in the front shell, with the carrier board behind it; the board is clamped between the three front bosses and three tubes in the rear shell by M2 screws; the cell sits between the board and the rear shell, located by four ribs; whether PETG bosses and a foam-backed cell survive these loads, and whether the gasketed joint reaches IP54 for the electronics, cannot be shown without a test. R10 is not verifiable at TRL 3.

## L. Cost (R15)

The BOM has 13 lines totaling an estimated $91.50 against the value-engineering target of $91 (`budget_usd`, a hypothetical control target, not a limit), $0.50 over it; the particle sensor is 52 % of the cost [L1]. Value-engineering target: USD 91. Estimated cost of the constructable design: USD 91.50 (USD 0.50 over the target) [L2]. The $0.50 is the foam pad (line 13) added for the worn version on 2026-10-02; the extra PETG in the deeper rear shell is about a cent and is inside line 9. The 2,000 mAh cell added $3 earlier (was $88.00), and Amish moved the target to $91 on 2026-09-26 to match the priced BOM (DBG-DDR-002, O3). R15 is not met on paper: raising the target to $92 is proposed to Amish in the design decisions register. The optional breakaway lanyard decided for TRL 4 (about $1) is not in this estimate.

## M. Results against every requirement

*Table 6. Requirement status from this note (v0.7).*

| ID | Requirement | Value | Target | Status |
| --- | --- | --- | --- | --- |
| R14 | Safe in hazardous atmospheres | Not intrinsically safe | Certified intrinsically safe | **Not met**, out of scope |
| R3 | Accuracy after site calibration | ±21 % (quarry), ±22 % (quartz-rich stone, D9 reference) with a factor per task; ±29 to ±30 % with a shared factor | ±25 % of a gravimetric shift average; D9 reference at low-dust, high-silica sites | **At risk** (was not met; assumed terms) |
| R11 | Work in site conditions | Shell at most 57.8 °C under the use rule; best performance only to 40 °C and 80 % RH; humidity flag | 0 to 45 °C, 10 to 90 % RH, readings flagged; worn shaded above 40 °C in full sun | **At risk** (was not met) |
| R10 | Survive the site | 750 to 1,500 g on a 1.5 m drop; IP54 by gasket, untested | IP54 electronics; 1.5 m drop | Not verifiable at TRL 3 |
| R2 | Cover the working range | 0 to 1,000 µg/m³; over-range flagged and counted | 0 to 1 mg/m³ with over-range flag (restated) | Met on paper (was not met against 5 mg/m³) |
| R6 | Warn before a limit is reached | Five scenarios behave as intended; one early warning (S5) | Projected TWA alerts at 25 and 50 µg/m³ | Met on paper |
| R7 | Last a full shift | 17.7 h typical at 25 °C; 12.8 h at maximum current and 0 °C | 12 h continuous | Met on paper (was at risk) |
| R8 | Wearable in the breathing zone | Inlet 242 mm from nose and mouth | 300 mm or less | Met on paper |
| R9 | Light and small | 120.7 g with the worn version; 64 x 52 x 34 mm | 122 g (relaxed from 120 g by Amish, 2026-10-02); 75 x 55 x 35 mm | Met on paper, 1.3 g margin |
| R12 | Keep a shift log | 11.5 kB per shift; 182 shifts; 6 s transfer | 30 shifts; BLE export | Met on paper |
| R15 | Low cost and buildable | $91.50; perfboard carrier | $91; no custom PCB | **Not met** by $0.50 (foam pad added 2026-10-02; was within the target at $91.00) |
| R1 | Measure the respirable fraction | PM4 as proxy; size cut offset in both directions (section D) | PM4 as ISO 7708 proxy | Met by design |
| R4 | Estimate silica exposure | Calibrated PM4 x site fraction, labeled | As stated | Met by design |
| R5 | Update often enough | 1 s readings, 1 min log, TWA every minute | As stated | Met by design |
| R13 | Protect the worker's data | Badge and phone only; sharing by the worker | As stated | Met by design |

Counts: 2 not met (R14, R15), 2 at risk, 1 not verifiable at TRL 3, 6 met on paper, 4 met by design (v0.6: 1 not met, 2 at risk, 1 not verifiable, 7 met on paper, 4 met by design; v0.1: 4 not met, 1 at risk, 1 not verifiable, 5 met on paper, 4 met by design).

## Checks against the TRL 2 figures

*Table 7. TRL 2 claims checked (as issued in v0.1, with the 1,500 mAh cell; the v0.2 values are in Table 6).*

| TRL 2 claim (DBG-PRC-001 v0.2) | This note | Action |
| --- | --- | --- |
| About 335 mW from the cell | 335 mW at 55 mA; 393 mW at 65 mA | Stands |
| About 13 h typical, about 11 h worst case | 13.3 h and 11.3 h; also 11.3 h at 0 °C | Precis updated with the cold case |
| Charge about 3.5 h | 3.4 h | Stands |
| Sensor precision ±5 µg/m³ plus 5 % at the action level for quartz-rich stone | That is the PM2.5 figure; PM4 is ±25 µg/m³ below 100 µg/m³ | Precis corrected |
| Log about 12 kB per shift, 30 shifts about 350 kB | 11.5 kB and 346 kB | Stands |
| About 220 mm from badge to nose | Inlet 242 mm from the nose and mouth midpoint | Precis and requirements updated |
| About 110 g | 111.8 g | Precis updated |
| 64 x 52 x 30 mm | 64 x 52 x 30 mm shells, 33 mm with the clip | Precis updated |
| About $85 | $88.00 with the humidity sensor and thermistor charger | Precis, BOM notes and README updated |
| Badge temperature not estimated | About 63 °C shell in full sun at 45 °C | R11 status changed to not met |

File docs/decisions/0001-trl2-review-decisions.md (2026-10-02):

---
doc_id: DBG-DDR-001
title: DustBadge TRL 2 review decisions
project: DustBadge
doc_type: Design decision record
version: "0.3"
status: Draft
date: '2026-10-02'
author: Amish Chadha
license: CERN-OHL-S-2.0
revisions:
- version: "0.1"
  date: '2026-09-25'
  author: Amish Chadha
  change: Record the TRL 2 review recommendations adopted for TRL 3 work under Amish's 2026-09-25 instruction, and the items that remain open
- version: "0.2"
  date: '2026-09-25'
  author: Amish Chadha
  change: "Recommendations accepted by Amish (DDR-002): D1 to D7 decided; O1 and O2 stay open"
- version: "0.3"
  date: '2026-10-02'
  author: Amish Chadha
  change: 'O1 and O2 decided by Amish on 2026-10-02'
---

# 0001: TRL 2 review decisions

- **Date:** 2026-09-25
- **Status:** items D1 to D7 decided by Amish on 2026-09-25 ("i accept all your recommendations, go with them across all repos"), recorded in DBG-DDR-002; items O1 and O2 decided by Amish on 2026-10-02 ("i approve your recommendations for all 555 open decisions."), recorded in DBG-DEC-001.

## Context

The TRL 2 review note (`docs/REVIEW.md`, session 2026-09-25, /populate) listed seven items as "Proposed, awaiting Amish", each with options and a recommendation. On 2026-09-25 Amish asked for this batch of repos to be taken through the usual process with the instruction "you know the drill, nothing gets past TRL 3". He has not reviewed this repo's items one by one. Every item that carries a recommendation is therefore adopted as recommended for TRL 3 under that instruction and stays open for his review. Items without a recommendation stay "Proposed, awaiting Amish". Later on 2026-09-25 Amish accepted all the recommendations, so D1 to D7 are now decided (DBG-DDR-002).

## Options considered

The options for each item are those listed in `docs/REVIEW.md` (session 2026-09-25, /populate) and in DBG-PRC-001 v0.2, Key design choices.
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

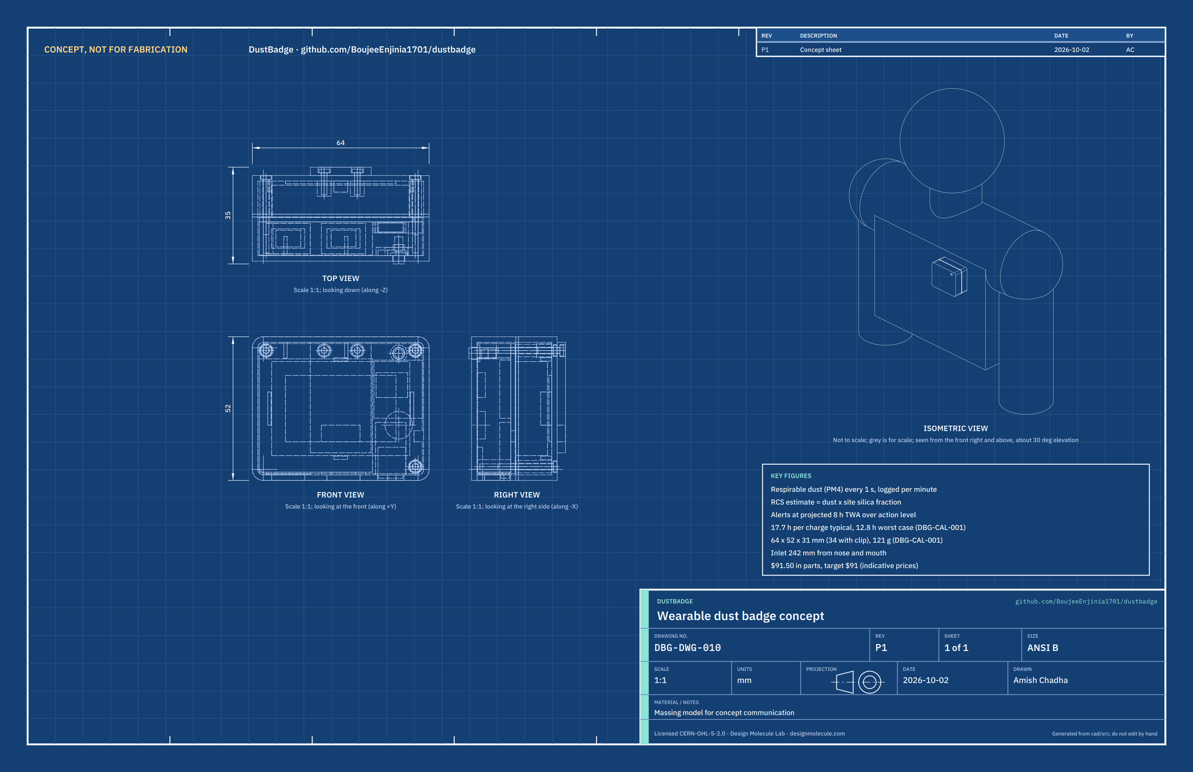
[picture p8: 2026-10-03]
media/concept-blueprint.png

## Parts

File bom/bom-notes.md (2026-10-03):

# BOM notes

- Prices are indicative single-unit prices in USD from September 2026 catalog searches and typical distributor listings. They are not quotes.
- Line numbers 1 to 11 and 13 match the numbered callouts in `media/exploded.png`; line 12 is software and is not modeled.
- Every line is priced. Total parts cost is now $91.50 (see the 2026-10-02 change below); it was $91.00, equal to the $91 `budget_usd` (approved by Amish on 2026-09-26 to cover the priced BOM, DBG-DDR-002; it was $90), as checked by `docs/04-calcs/sizing.py` (DBG-CAL-001 v0.2, section L). The particle sensor is 53 % of the cost; the SPS30 class was decided by Amish on 2026-09-25 (DBG-DDR-001, D1; DBG-DDR-002).
- TRL 3 change: line 7 now includes an SHT4x-class humidity and temperature sensor (R11 flag) and a charger with a cell thermistor input (0 to 45 °C charging), adding $3. Line 8 specifies a cell with a thermistor lead.
- 2026-09-25 change (DBG-DDR-002, D8): line 8 is now a 2,000 mAh cell, 11.5 mm thick, at $13.00 (was 1,500 mAh at $10.00), so R7 is met in the worst case. It takes the total from $88.00 to $91.00. The budget figure for the larger cell (DBG-DDR-002, O3) was decided by Amish on 2026-09-26: `budget_usd` $90 to $91.
- Supplier types are given where no single supplier is needed; the SPS30 and SHT4x are sold by major electronics distributors.
- Not included: the filter sample and laboratory analysis needed to set a site silica fraction, and access to CalRig for chamber checks.
- 2026-09-30 change (DBG-DDR-003, design for construction): specifications of lines 2, 6, 7, 9, 10 and 11 now describe the parts as the build plan uses them (screen size, flanged light pipe, the carrier board's modules, the TPU gasket and port seals, the drilled clip, the five M2 screws and foam tape). No price changed: the gasket and seals are printed from the TPU already in line 9, and the screws and tape fall within line 11. The total stays $91.00.
- 2026-10-02 change (DBG-DDR-003 A1, worn version): line 13, a 40 x 24 x 1 mm closed-cell foam pad behind the cell, USD 0.50 (a 1 mm adhesive-backed sheet at about USD 6 to 8 gives many pads; the price allows for a part-used sheet). The 1 mm deeper rear shell adds about a cent of PETG inside line 9. The total is $91.50, $0.50 over the $91 value-engineering target (DBG-CAL-001 v0.7, section L). The optional breakaway lanyard (about $1) is decided for TRL 4 and is not in the total.

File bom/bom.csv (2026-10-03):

item | qty | spec | supplier | unit_cost_usd | make_buy | notes
1 Front shell with bottom inlet | 1 | 3D-printed PETG, high-visibility yellow, about 64 x 52 x 16 mm | Self | 1.50 | make | Material cost only
2 Inlet dust screen | 1 | Stainless mesh, about 1 mm aperture, cut to a 16 x 11 mm square | Hardware store | 1.00 | buy | Indicative price
3 Optical particle sensor | 1 | Sensirion SPS30 class, PM1 to PM10 including PM4, 0 to 1000 ug/m3, 5 V | Electronics distributor | 48.00 | buy | Indicative price; adopted for TRL 3 (DBG-DDR-001 D1)
4 Controller and BLE module | 1 | nRF52840 with 2 MB flash and LiPo charger (Seeed XIAO nRF52840 class) | Seeed Studio or distributor | 10.00 | buy | Indicative price
5 Vibration motor | 1 | 10 mm coin, 3 V | Online retailer | 1.50 | buy | Indicative price
6 Alert LED and light pipe | 1 | Red 3 mm LED; light pipe printed in clear PETG, 4 mm rod with a 6 mm flange | Electronics distributor | 0.50 | buy | Indicative price
7 Carrier board | 1 | Perfboard 59 x 47 mm; 500 mA charger module with USB-C and cell thermistor input (about 11 x 19 mm); 5 V boost module with enable input (about 11 x 9 mm); polyfuse; small N-MOSFET, diode and resistors for the motor and LED; SHT4x-class humidity and temperature breakout (about 10 x 10 mm) | Electronics distributor | 9.00 | buy | Indicative price; humidity sensor and thermistor charger added at TRL 3 (DBG-CAL-001 sections B and C); no custom PCB for the first build; modules placed for construction (DBG-DDR-003)
8 LiPo cell | 1 | 2000 mAh 3.7 V protected, about 50 x 34 x 11.5 mm, with 10 kohm thermistor lead | Hobby electronics distributor | 13.00 | buy | Indicative price; 2000 mAh adopted (DBG-DDR-002 D8; was 1500 mAh at $10.00)
9 Rear shell | 1 | 3D-printed PETG, about 64 x 52 x 13 mm, with a printed TPU flat gasket (1 mm) and two printed TPU sensor port seals | Self | 1.50 | make | Material cost only
10 Spring clip and strap loop | 1 | Stainless spring clip, about 40 mm, base leaf drilled for two M2 screws 12 mm apart | Online retailer | 2.00 | buy | Indicative price
11 Hardware and consumables | 1 | Three M2 x 20 and two M2 x 8 thread-forming pan-head screws, wire, heat shrink, double-sided foam tape, adhesive | Self | 3.00 | buy | Indicative price; screws modeled from DBG-DDR-003
12 Phone app for shift log | 1 | Open-source web Bluetooth page or app (software) | Self | 0.00 | make | Software; no parts cost
13 Foam pad behind the cell | 1 | Closed-cell polyethylene foam, 1 mm, adhesive backed, cut to 40 x 24 mm and stuck to the inside of the rear wall behind the cell | Online retailer | 0.50 | buy | Indicative price: a 1 mm adhesive-backed sheet sold for about USD 6 to 8 gives many 40 x 24 mm pads; USD 0.50 allows for a part-used sheet; added 2026-10-02 for the worn version (DBG-DDR-003 A1)

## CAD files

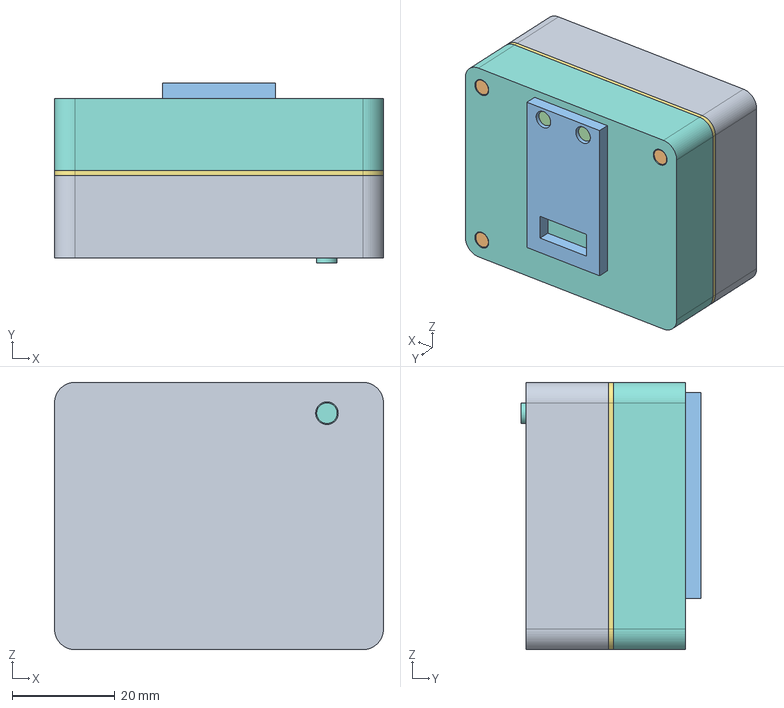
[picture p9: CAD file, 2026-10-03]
cad/step/dustbadge-assembly.step
64.0 x 35.0 x 52.0 mm

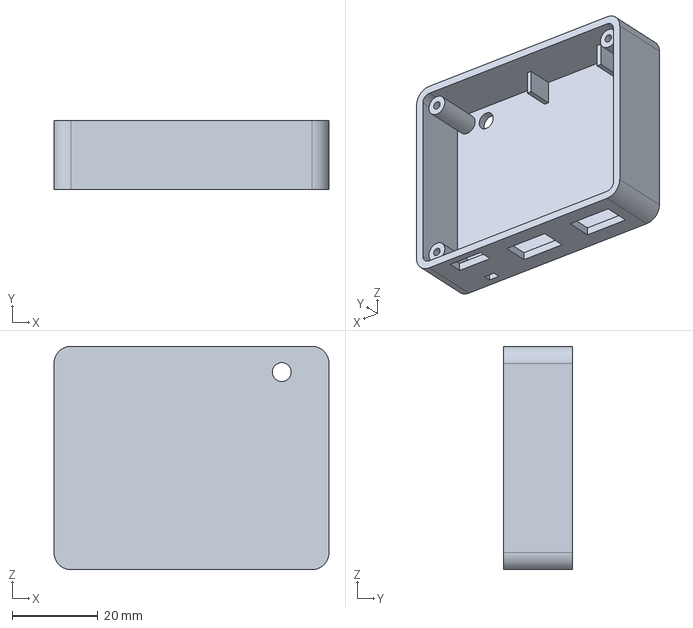
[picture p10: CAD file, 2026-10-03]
cad/step/front-shell.step
64.0 x 16.0 x 52.0 mm

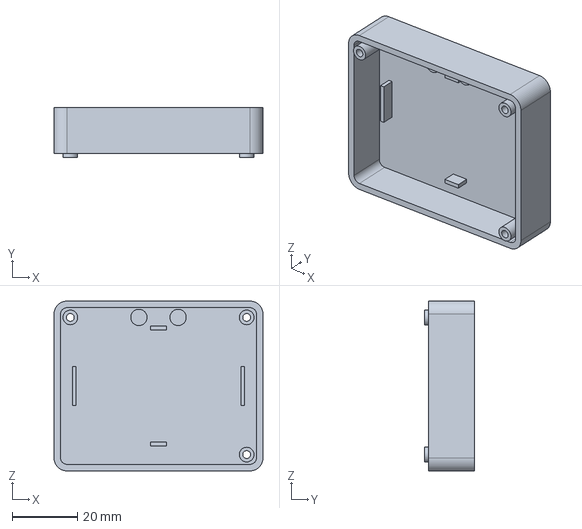
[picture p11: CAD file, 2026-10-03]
cad/step/rear-shell.step
64.0 x 15.2 x 52.0 mm

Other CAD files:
cad/stl/dustbadge-assembly.stl
cad/stl/front-shell.stl
cad/stl/rear-shell.stl

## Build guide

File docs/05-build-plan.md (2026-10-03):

---
doc_id: DBG-BLD-001
title: DustBadge prototype build plan
project: DustBadge
doc_type: Build plan
version: "0.4"
status: Draft
date: '2026-10-02'
author: Amish Chadha
license: CERN-OHL-S-2.0
revisions:
  - version: "0.1"
    date: '2026-09-30'
    author: Amish Chadha
    change: First build plan; design made constructable (DBG-DDR-003)
  - version: "0.2"
    date: '2026-10-01'
    author: Amish Chadha
    change: Budget treated as a value-engineering target; cross-references updated
  - version: "0.3"
    date: '2026-10-02'
    author: Amish Chadha
    change: 'Safety stop S7: badge as built is for bench work only; deeper rear shell and foam pad before anyone wears it (decided by Amish, 2026-10-02)'
  - version: "0.4"
    date: '2026-10-02'
    author: Amish Chadha
    change: 'Worn version: rear shell 1 mm deeper (64 x 52 x 31 mm), foam pad behind the cell (BOM line 13), pictures regenerated; bench-only note removed from S7'
---

# DustBadge prototype build plan

**Plan, not yet built.** How to build the first proof-of-concept prototype, component by component. Building and testing to it is TRL 4 work. Decisions are kept in the design decisions register ([docs/06-design-decisions.md](06-design-decisions.md)), not here.

## 1. What you are building

Figure 1. Every component, pulled apart and numbered in build order

*Figure 1. Every component pulled apart and numbered in build order: the front half above, the rear half below.*

The prototype is one DustBadge: a hi-vis yellow printed front shell and a dark printed rear shell, 64 x 52 x 31 mm, closed by three small screws from the back, with a spring clip on the back for a collar, pocket or harness strap. Inside, a bought particle sensor sits on two soft seals over two slots in the bottom face, so its fan draws air up through a mesh screen; behind it a perfboard carries the controller and a charger, and behind that a 2,000 mAh lithium polymer cell sits in the rear shell. A coin motor, a 5 V boost module and a humidity sensor are taped to the inside of the front face, and a red LED shines through a light pipe. Figure 1 shows the 18 components in the order you make or fit them. Six are printed (the two shells, the gasket, two port seals and the light pipe), the screen is cut from mesh, the foam pad is cut from a foam sheet, the perfboard is cut and drilled and the bought clip may need two holes; everything else is bought and wired. The work is 3D printing in PETG and TPU, cutting and drilling perfboard, small soldering, and fitting with screws and tape. The parts cost about $91.50 from the bill of materials.

> **Safety:** The badge holds a 2,000 mAh lithium polymer cell and is worn against the body. Keep the cell out of the badge until the stop points of section 6 say otherwise, never charge it while worn, below 0 °C or above 45 °C, and never leave a first build charging unattended. The badge is not intrinsically safe: do not take it into a gassy mine or any place with flammable gas or combustible dust. Its readings are a research estimate, not a safety measurement. Soldering and printing give off fumes; work in a ventilated space.

## 2. What changed to make it buildable

The concept showed what the badge does; some of its parts could not be made, fixed or sealed as drawn. Each change below keeps what the badge does and its size, and all of them are recorded in decision record DBG-DDR-003, accepted by Amish on 2026-10-02.

*Table 1. Changes from the concept.*

| Component | The concept had | The buildable design has | Why |
| --- | --- | --- | --- |
| Shell closure | Bosses in the front shell only, with a 14 mm gap behind the board and no screws | Three tubes in the rear shell and three M2 x 20 screws from the rear face that clamp the rear shell, gasket and board onto the front bosses (Figure 15) | The badge closes, and the board is held, with one set of screws |
| Gasket | Listed, but no room for it | A flat printed TPU frame 1 mm thick between the rims; the rear shell is 1 mm shallower (Figure 18) | Seals the joint |
| Sensor air path | Sensor ports 1 mm above the slots, open to the inside | Two printed TPU seals between the ports and the slots (Figure 7) | The fan draws only outside air |
| Inlet screen | A 1.2 mm screen sitting loose in the slot | A 16 x 11 mm mesh square on the inner floor, held by the inlet seal (Figure 7) | Held and sealed without glue in the air path |
| Sensor and cell | Nothing holding the sensor up or the cell sideways | Two stop ribs over the sensor; four ribs round the cell (Figures 11 and 14) | Each has a load path for a drop |
| Electronics | Boost, charger and humidity sensor not placed; the humidity vent opened under the sensor | Charger with USB-C on the board; boost, humidity sensor and motor taped inside the front face; USB-C opening and vent moved (Figures 3 and 12) | The only free space is beside the sensor; the vent now opens under the humidity sensor |
| Carrier board | 56 x 44 mm, screw holes breaking its edges | 59 x 47 mm with cut corners and a notch for the cell lead (Figure 9) | Material round every hole |
| Clip | No fixing | Two M2 x 8 screws into bosses above the cell (Figure 17) | The only place above the cell clear of the shell screws |
| Cell room | 0.7 mm of free depth round the cell | The rear shell is 1 mm deeper and a 1 mm foam pad is stuck behind the cell (Figures 13 and 14); the badge is 31 mm deep, 34 mm with the clip | Room for the cell to swell as it ages; this is the version to wear |
| Light pipe | A loose rod with no LED behind it | A printed clear pipe with an inside flange and a pocket for the LED (Figure 5) | Held in, and lit where it needs to be |

## 3. Making the components

Make and check each component before the assembly step that needs it. Sizes are in millimetres. "Left" and "right" are as seen looking at the front of the badge (the yellow face, worn facing out); "up" is toward the top edge as worn. Print tolerance is 0.2 mm unless a step says otherwise; drawings do not carry tolerances before TRL 4.

### 3.1 Front shell

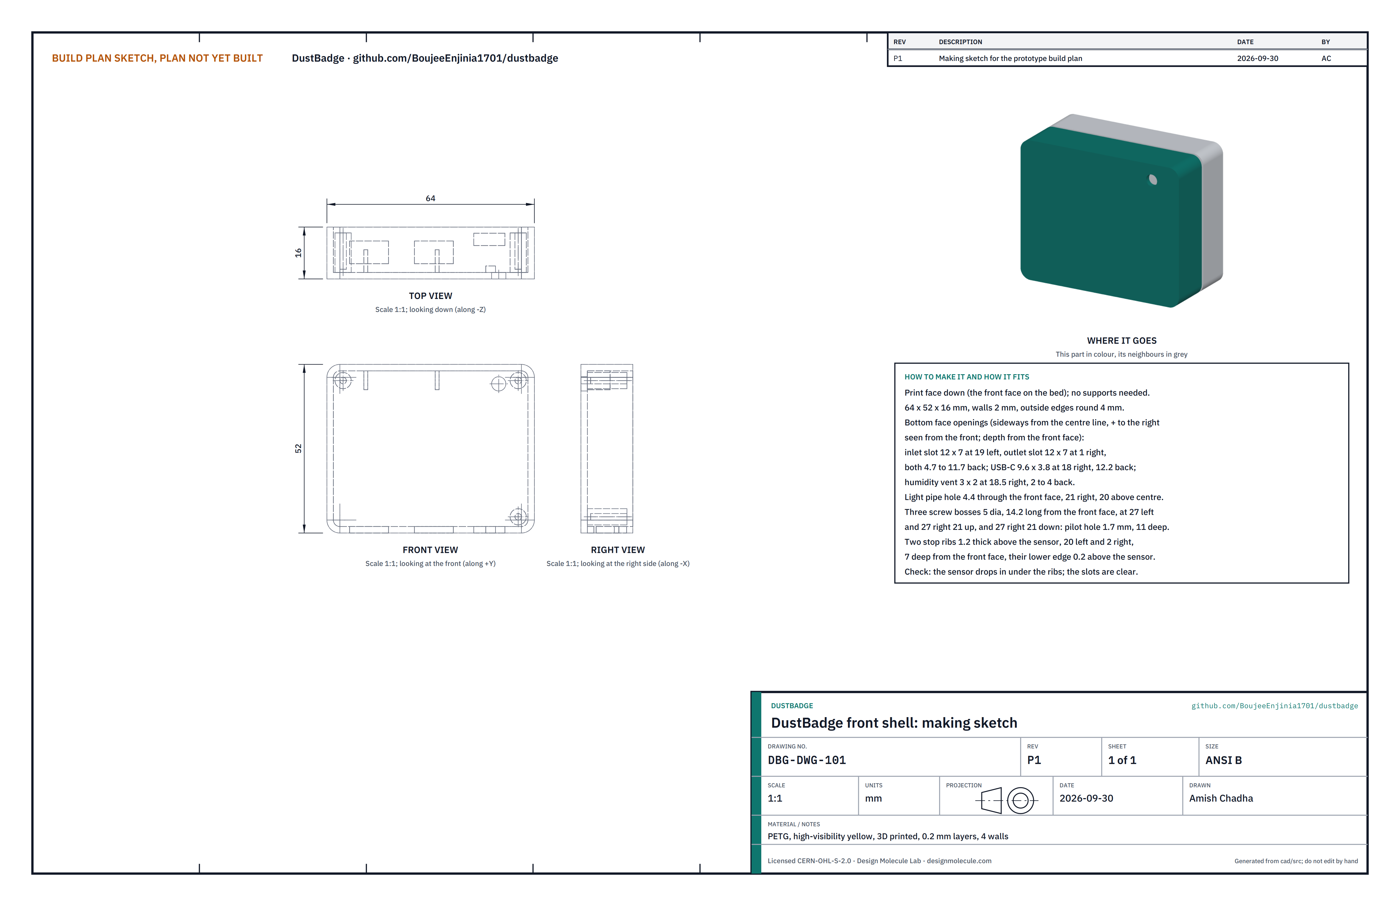
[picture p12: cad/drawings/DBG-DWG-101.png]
Figure 2. Making sketch of the front shell


*Figure 2. Front shell making sketch (DBG-DWG-101).*

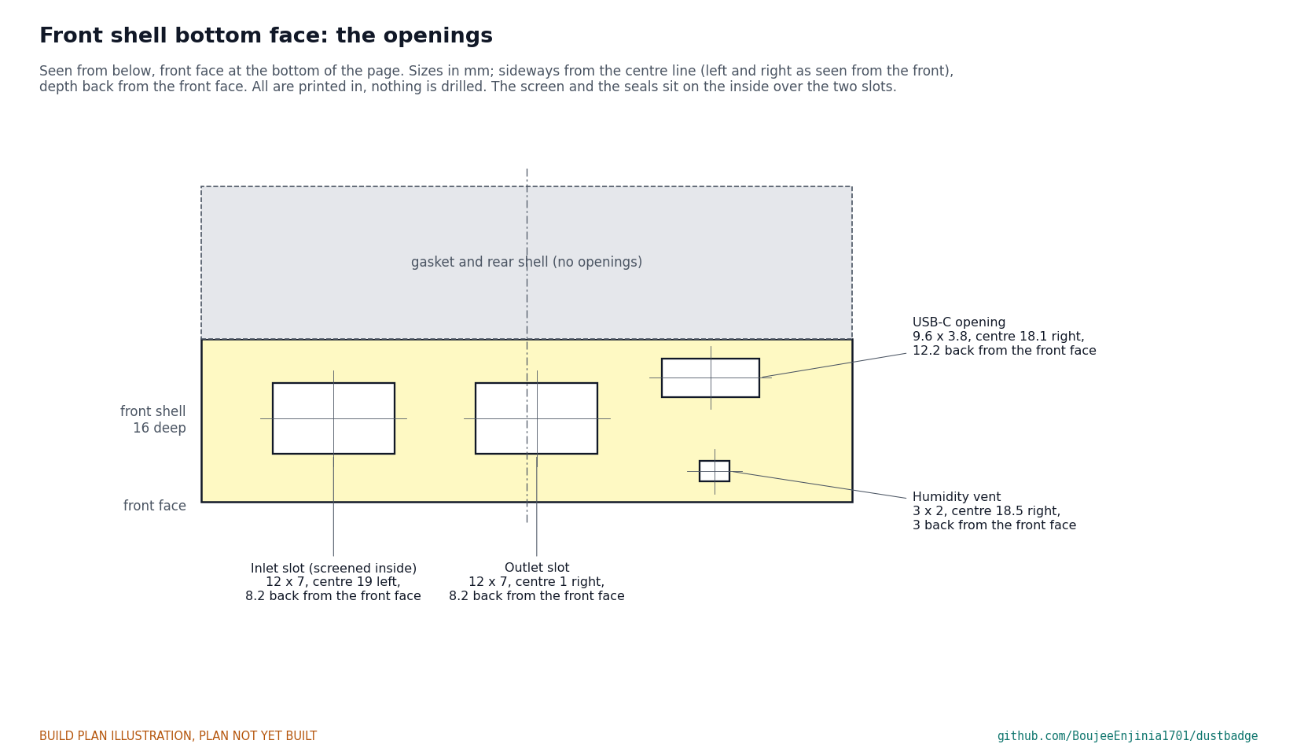
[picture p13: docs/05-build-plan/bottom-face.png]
Figure 3. The openings in the bottom face


*Figure 3. The four openings in the bottom face, seen from below, front face at the bottom of the page.*

**What it is and what it is made from.** The yellow front half of the badge, 64 x 52 x 16 mm, open at the back, with the inlet and outlet slots, the USB-C opening and the humidity vent in its bottom face, a hole for the light pipe in its front face, three screw bosses and two stop ribs inside. PETG, high-visibility yellow, printed at 0.2 mm layers with four walls.

**How to make it.**

1. Print it face down (the front face on the bed). No supports are needed: the openings in the bottom face bridge 12 mm at most.
2. Check the four bottom openings against Figure 3 and the 4.4 mm light-pipe hole, 21 right and 20 up from the centre of the front face. Clear any stringing with a craft knife.
3. Open the three bosses (27 left and 27 right, 21 up; 27 right, 21 down, seen from the front) to 1.7 mm, 11 deep, with a hand drill, so the thread-forming screws start straight.
4. Check the two stop ribs above the sensor's place: 1.2 thick, 20 left and 2 right of centre, their lower edges 42.2 mm above the inner floor.

**How it fits the parts next to it.** The light pipe goes through its hole from inside (Figure 5). The screen and the two seals sit on the inner floor over the slots, and the sensor rests on the seals under the ribs (Figure 7). The board rests on the ends of the three bosses, with the charger module's USB-C sitting in its opening 0.8 mm inside the bottom face. The gasket sits on the rim (Figure 18).

**Check before moving on.** The sensor, set in by hand without the seals, drops under the ribs with about 1.2 mm to spare; a USB-C plug enters its opening square.

### 3.2 Light pipe and LED

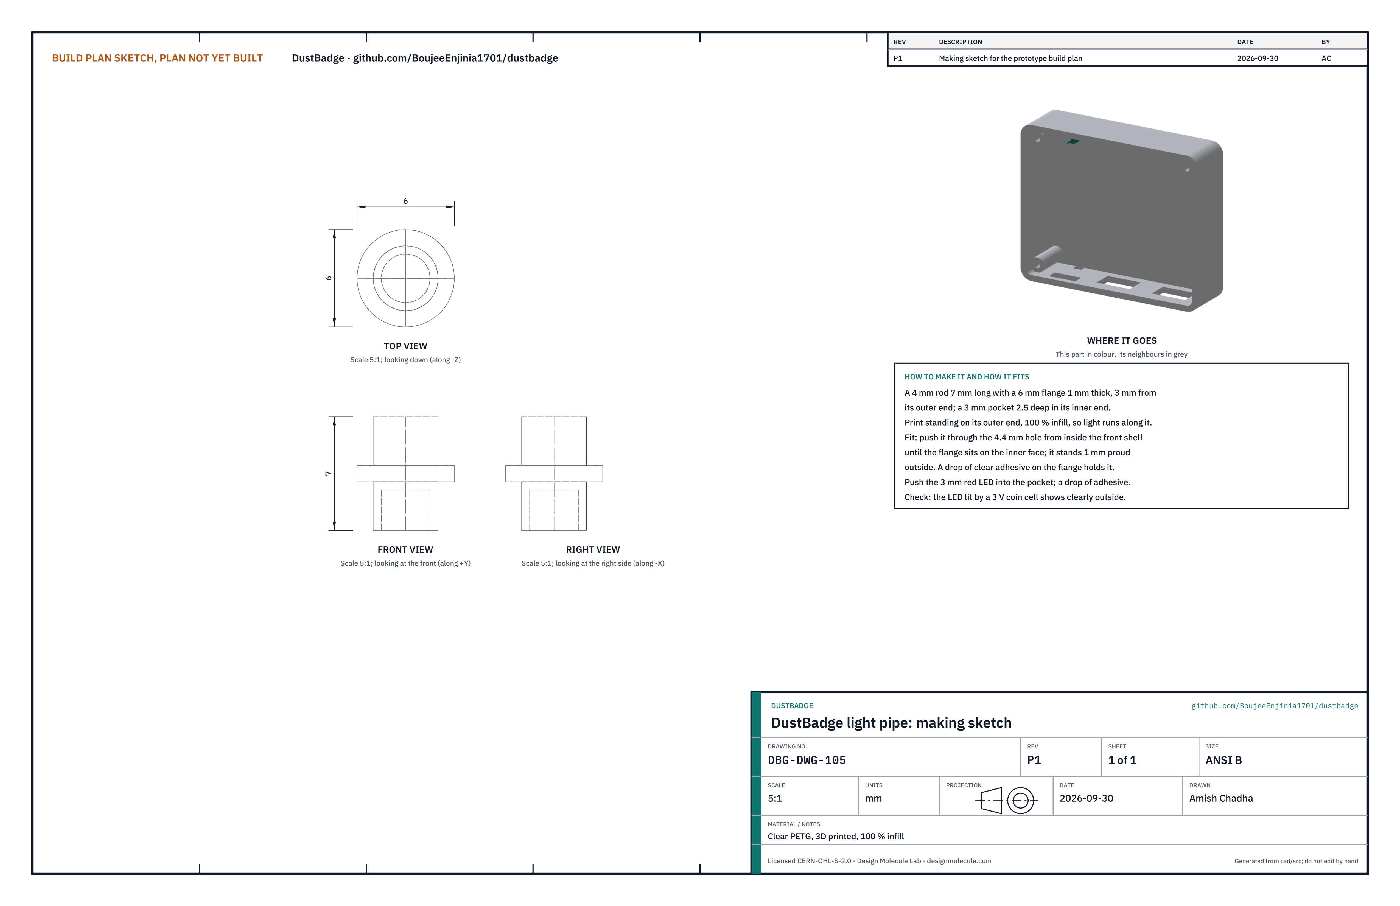
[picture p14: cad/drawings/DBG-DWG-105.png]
Figure 4. Making sketch of the light pipe


*Figure 4. Light pipe making sketch (DBG-DWG-105).*

**What it is and what it is made from.** A short clear rod that carries the alert LED's light through the front face. Clear PETG, printed at 100 % infill; a bought red 3 mm LED.

**How to make it.**

1. Print the pipe standing on its outer end: a 4 mm rod 7 mm long, with a 6 mm flange 1 mm thick 3 mm from the outer end, and a 3 mm pocket 2.5 deep in the inner end.
2. Solder 60 mm leads to the LED and sleeve them; mark the positive lead.
3. Push the LED into the pocket with a drop of clear adhesive.

**How it fits the parts next to it.**

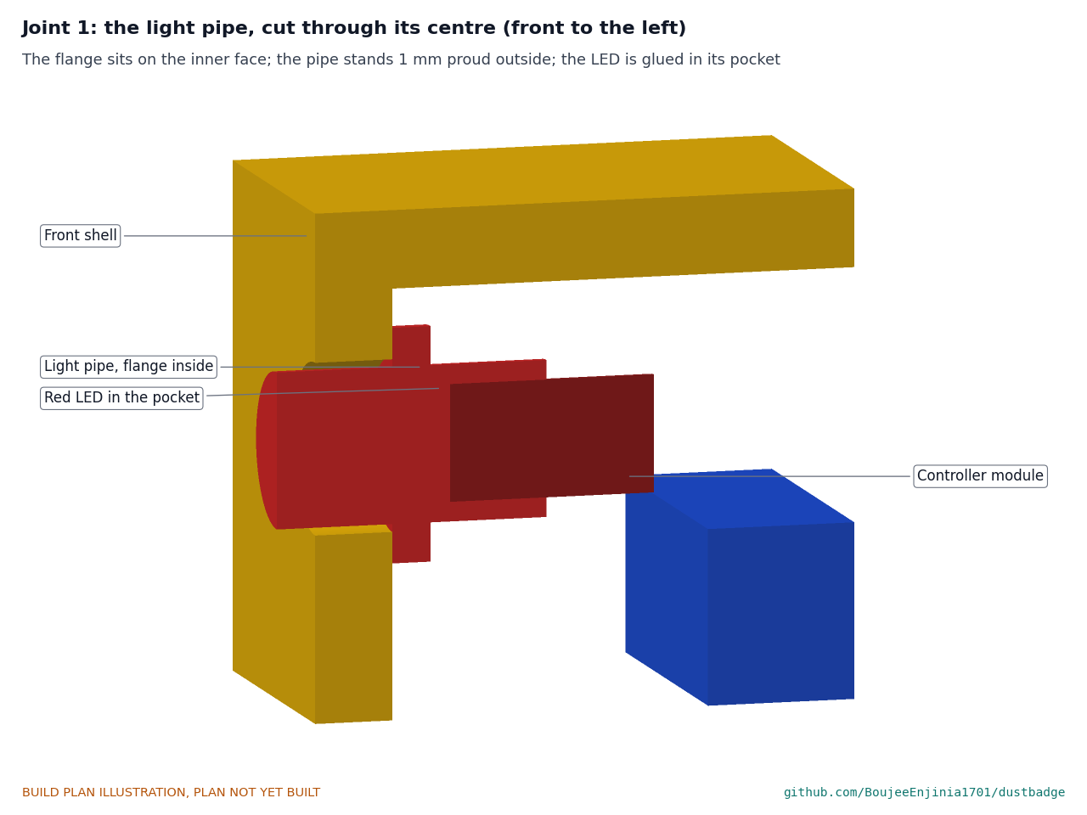
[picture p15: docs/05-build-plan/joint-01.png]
Figure 5. Joint 1: the light pipe in the front face


*Figure 5. The flange sits on the inside of the front face; the pipe stands 1 mm proud outside; the LED is in the pocket.*

The pipe goes through the 4.4 mm hole from inside until the flange sits flat on the inner face; a drop of clear adhesive on the flange holds it. The LED leads go back to the board past the controller module, 1.7 mm clear of it.

**Check before moving on.** Lit from a 3 V coin cell through a 100 Ω resistor, the light shows clearly from outside.

### 3.3 Inlet screen

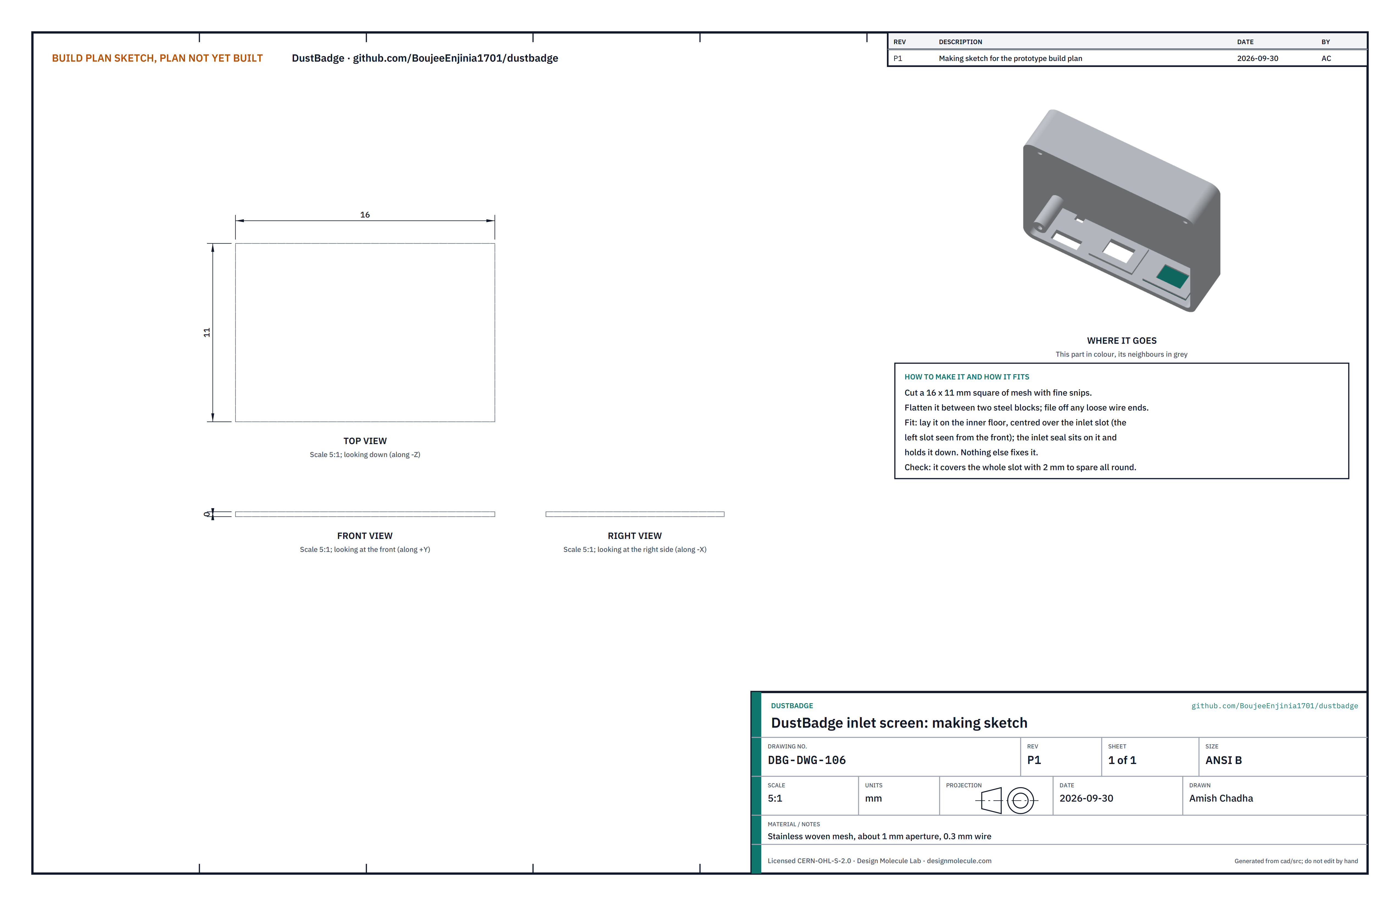
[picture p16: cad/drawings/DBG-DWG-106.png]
Figure 6. Making sketch of the inlet screen


*Figure 6. Inlet screen making sketch (DBG-DWG-106). The 0.3 mm thickness is shown rounded on the drawing.*

**What it is and what it is made from.** A square of mesh over the inlet slot that keeps grit and splash out of the sensor. Stainless woven mesh with about 1 mm openings and 0.3 mm wire; it must not act as a size filter for respirable particles, so do not use a finer mesh.

**How to make it.**

1. Cut a 16 x 11 mm square with fine snips.
2. Flatten it between two steel blocks and file off any loose wire ends.

**How it fits the parts next to it.**

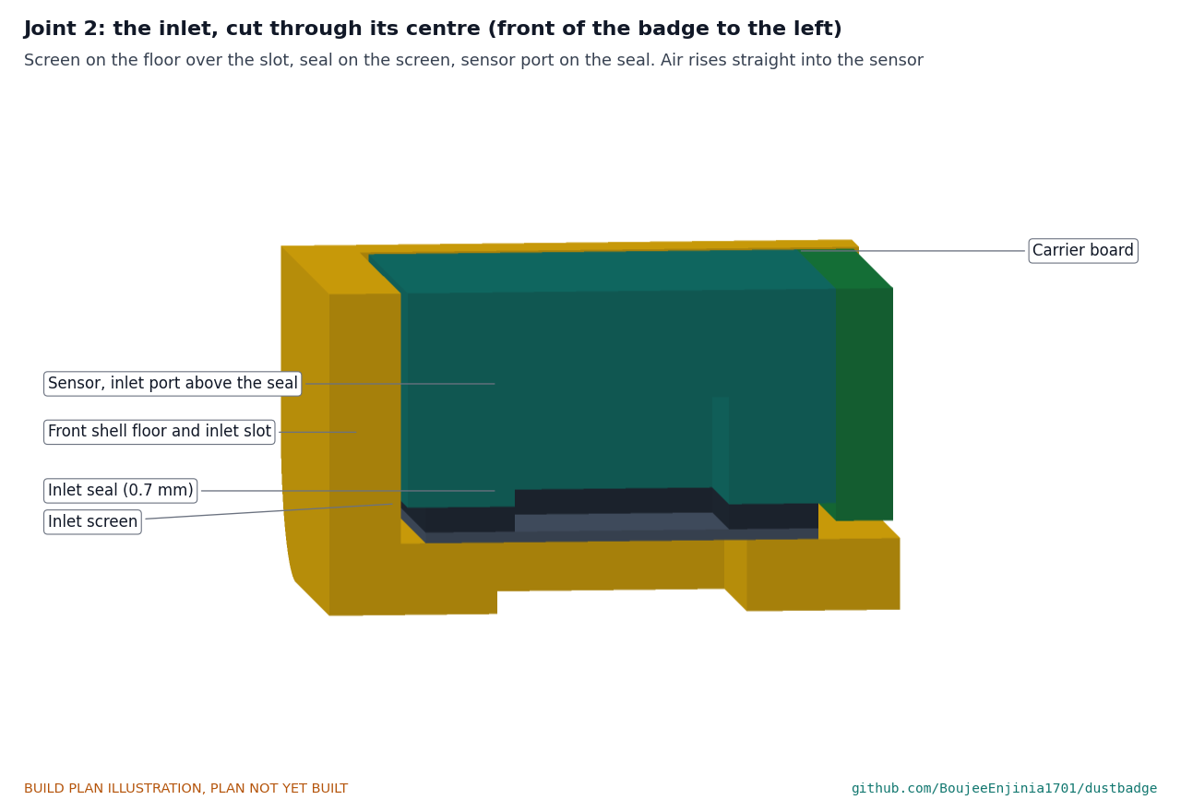
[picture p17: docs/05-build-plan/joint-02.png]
Figure 7. Joint 2: the inlet, cut through its centre


*Figure 7. Screen on the floor over the inlet slot, the thin seal on the screen, the sensor's inlet port on the seal.*

The screen lies on the inner floor centred over the inlet slot (the left-hand slot, 19 left of centre and 8.2 back from the front face), covering it with 2 mm to spare all round. The inlet seal sits on it and holds it down; nothing else fixes it.

**Check before moving on.** The screen lies flat with no wire ends standing up.

### 3.4 Port seals (make 2)

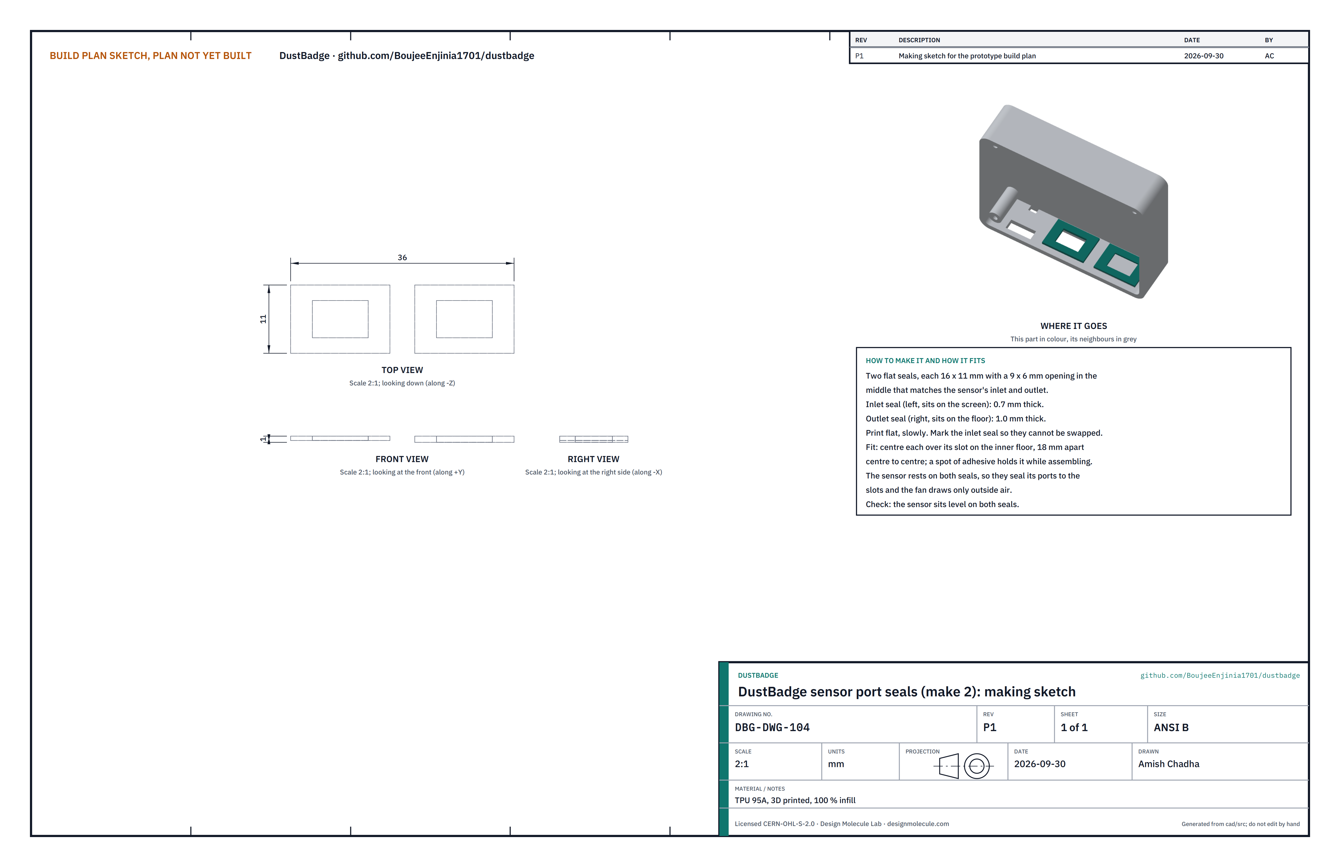
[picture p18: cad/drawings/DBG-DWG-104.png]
Figure 8. Making sketch of the port seals


*Figure 8. Port seal making sketch (DBG-DWG-104).*

**What they are and what they are made from.** Two flat seals that join the sensor's inlet and outlet ports to the slots in the floor, so the fan draws only outside air. TPU 95A, printed at 100 % infill.

**How to make them.**

1. Print both flat and slowly: each 16 x 11 mm with a 9 x 6 mm opening in the middle. The inlet seal is 0.7 mm thick; the outlet seal is 1.0 mm.
2. Mark the inlet seal with a dot so the two cannot be swapped.

**How they fit the parts next to them.** The inlet seal sits on the screen; the outlet seal sits on the floor over the outlet slot (1 right of centre), 18 mm centre to centre from the inlet seal (Figure 7). A small spot of adhesive at one corner of each, away from the opening, holds them while you assemble. The sensor rests on both, so the different thicknesses keep it level.

**Check before moving on.** With the sensor set on them, it sits level and does not rock.

### 3.5 Carrier board, with the controller and charger

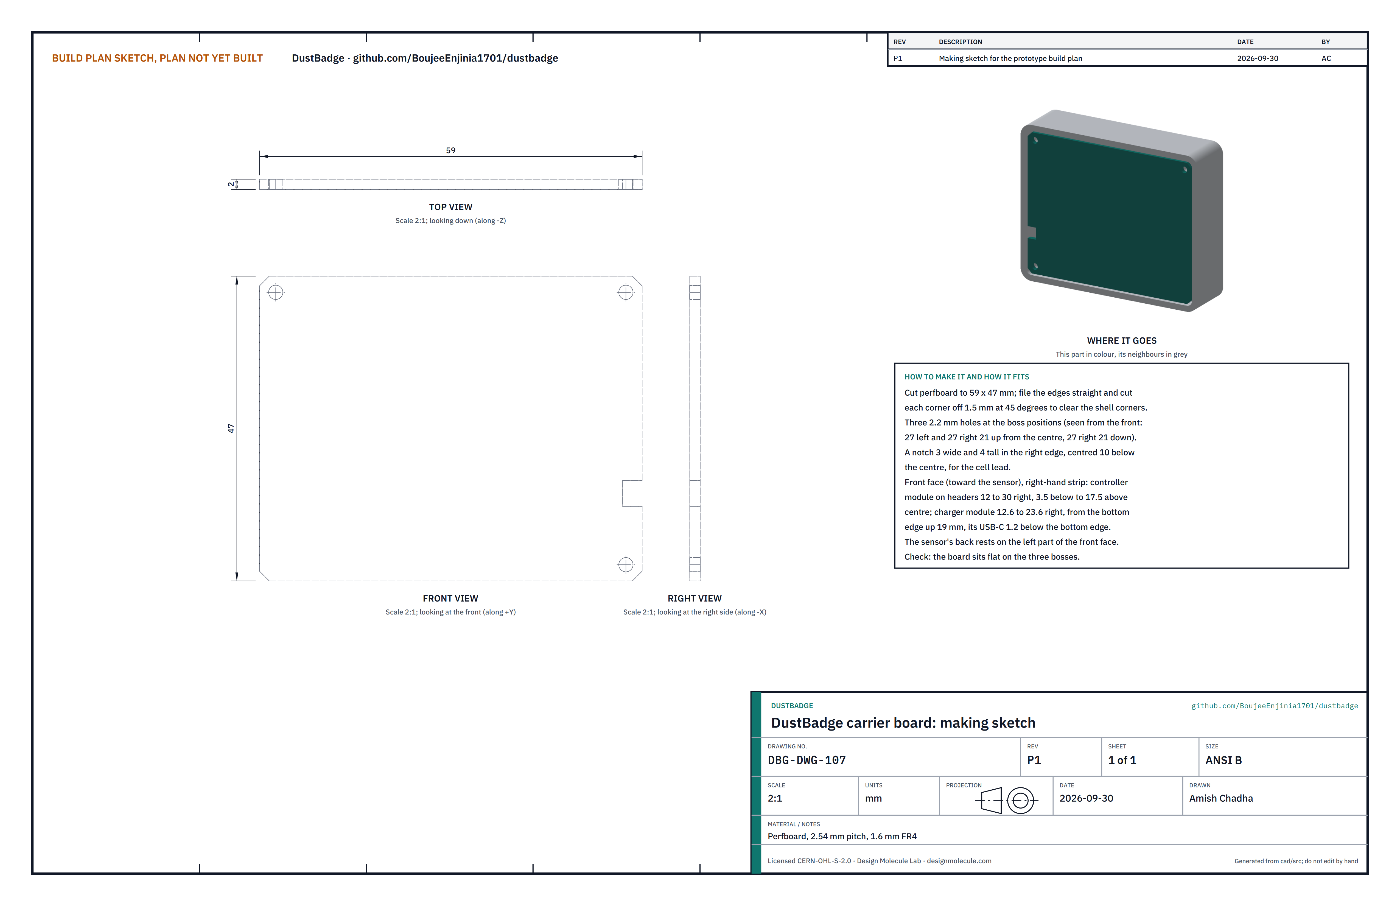
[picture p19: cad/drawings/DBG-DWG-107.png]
Figure 9. Making sketch of the carrier board


*Figure 9. Carrier board making sketch (DBG-DWG-107).*

**What it is and what it is made from.** The board behind the sensor that carries the controller module and the charger module, holds the sensor against the front shell, and is clamped by the three shell screws. Perfboard, 2.54 mm pitch, 1.6 mm thick.

**How to make it.**

1. Cut the perfboard to 59 x 47 mm and file the edges straight. Cut each corner off 1.5 mm at 45°.
2. Drill three 2.2 mm holes, seen from the front: 27 left and 21 up, 27 right and 21 up, 27 right and 21 down from the centre of the board.
3. Cut a notch 3 wide and 4 tall in the right edge, centred 10 below the centre, for the cell lead.
4. On the front face (the face toward the sensor), fit the controller module on header pins in the right-hand strip, from 12 to 30 right and from 3.5 below to 17.5 above the centre.
5. Below it, fit the charger module with its USB-C receptacle on its lower edge, from 12.6 to 23.6 right, its board starting at the board's lower edge and its USB-C standing 1.2 below that edge. Solder both.
6. Fit the polyfuse and the small transistor, diode and resistors for the motor and LED in the free holes on the right-hand strip.
7. Wire the board as Figure 12 shows (section 3.5.1).

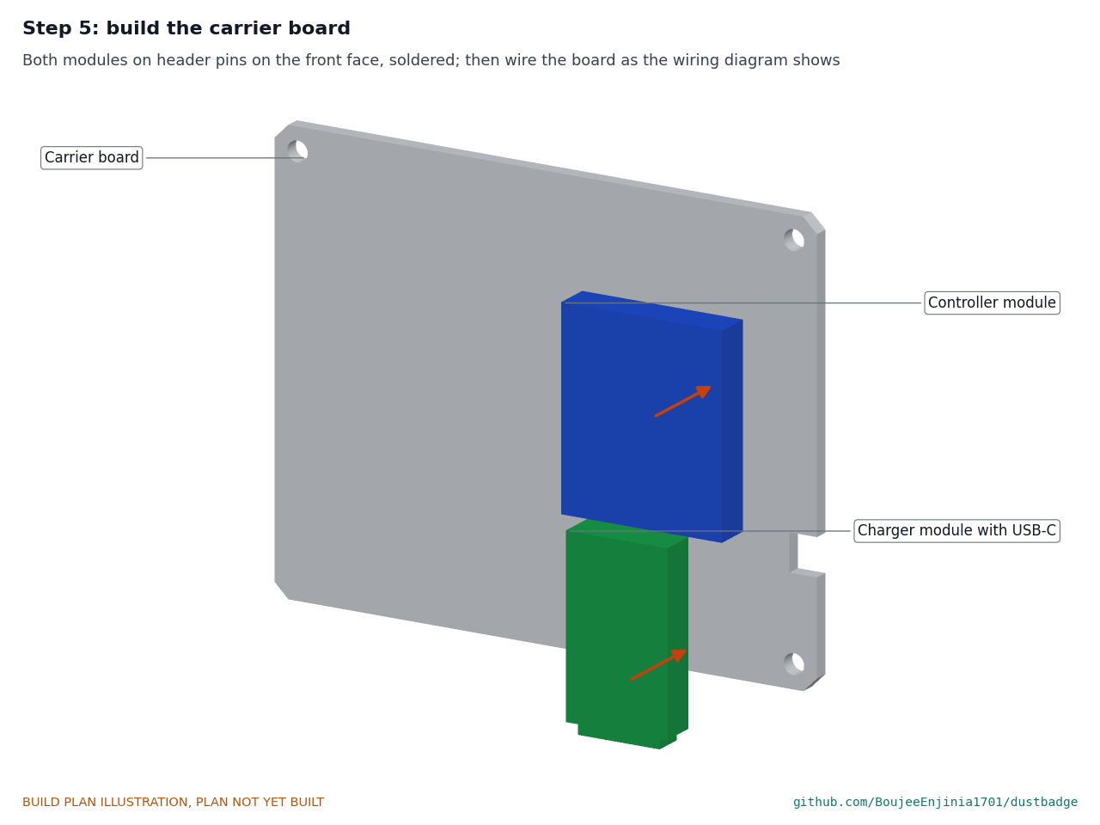
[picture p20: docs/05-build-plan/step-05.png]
Figure 10. Step 5 picture: the modules on the board


*Figure 10. Where the two modules go on the front of the board.*

**How it fits the parts next to it.**

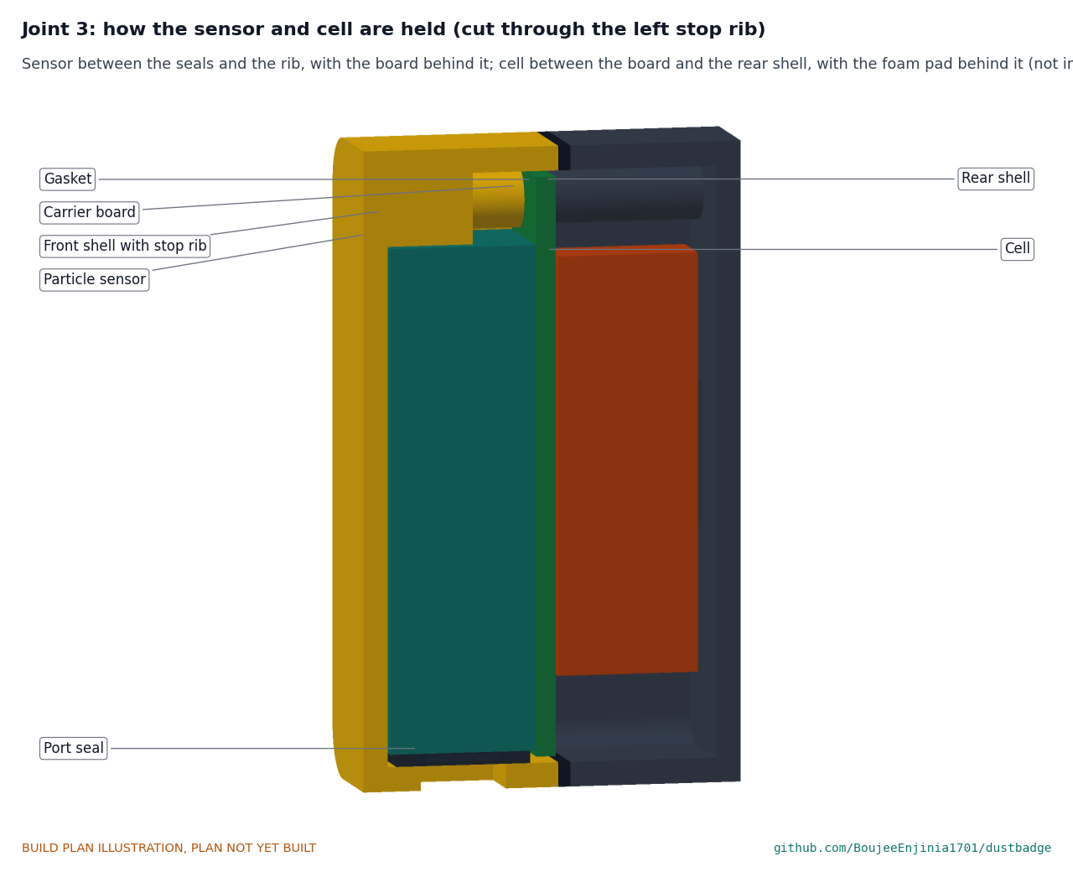
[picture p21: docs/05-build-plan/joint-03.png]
Figure 11. Joint 3: how the sensor and cell are held


*Figure 11. Cut through the left stop rib: the sensor between the seals, the rib and the board; the cell between the board and the rear shell.*

The board rests on the ends of the three front bosses. The sensor's back rests on the left part of the board's front face. The three rear tubes press on the board's back, so the shell screws clamp it (Figure 15). The cell sits 0.2 mm behind the board.

**Check before moving on.** The board sits flat on the three bosses in a trial fit, with the USB-C square in its opening.

#### 3.5.1 Wiring

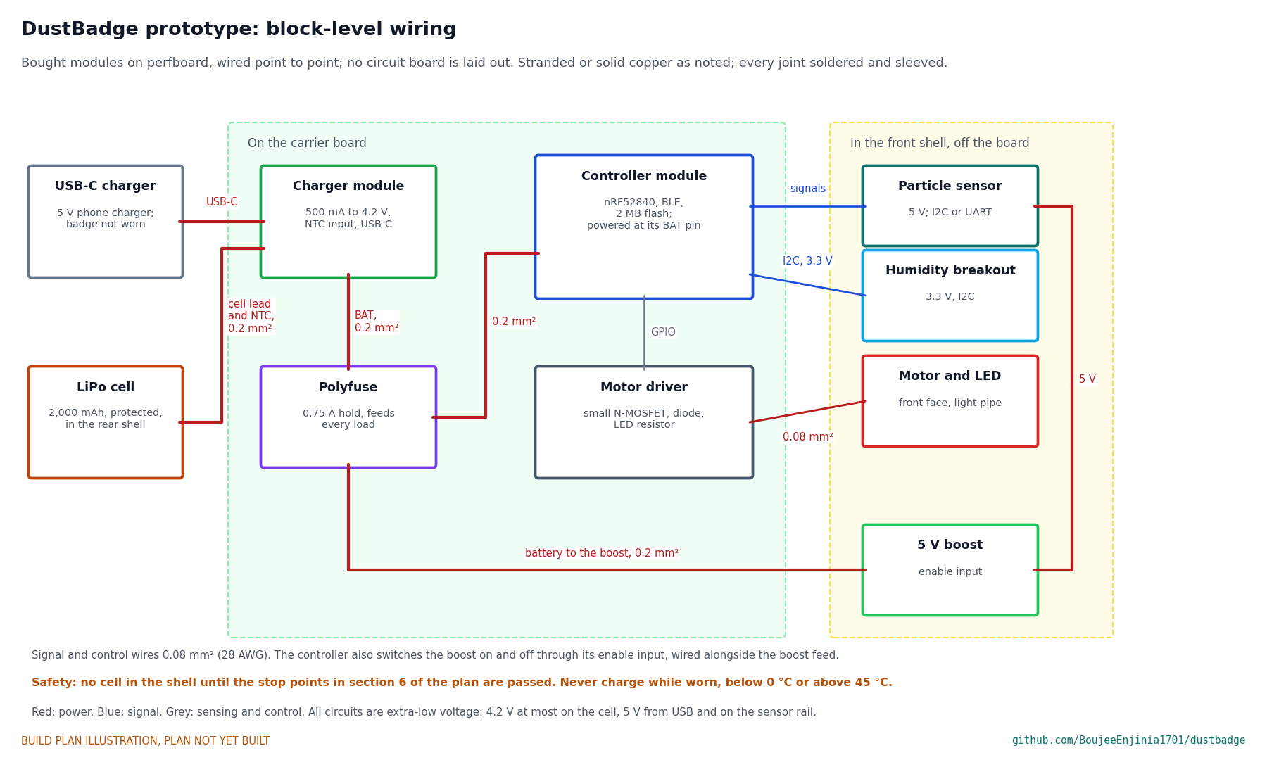
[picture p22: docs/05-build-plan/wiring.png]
Figure 12. Block-level wiring


*Figure 12. Block-level wiring with wire sizes. No circuit board is laid out at this stage; bought modules stand in for one.*

The modules are bought to this specification:

*Table 2. Modules and what to buy.*

| Module | What to buy |
| --- | --- |
| Controller | nRF52840 module with Bluetooth Low Energy and 2 MB flash, about 17.5 x 21 mm (Seeed XIAO nRF52840 class) |
| Charger | Single-cell lithium polymer charger, 4.2 V, 500 mA, with a cell temperature (NTC) input that stops charging below 0 °C and above 45 °C, and a USB-C receptacle on its short edge; no larger than 11 x 19 mm |
| 5 V boost | Boost converter from the cell to 5 V, at least 100 mA, with an enable input; no larger than 11.4 x 9 mm |
| Humidity sensor | SHT4x-class humidity and temperature breakout, I2C, 3.3 V, with the sensor at one edge; no larger than 10 x 10 mm |
| Polyfuse | Resettable fuse, about 0.75 A hold, on the cell side of every load |
| Motor driver | Small logic-level N-channel transistor, a diode across the motor, and a resistor for the LED |

Wire it like this, soldering every joint and sleeving it with heat shrink:

1. Cell lead (with its NTC wire) to the charger's battery and NTC terminals: 0.2 mm² (24 AWG), through the notch in the board's right edge.
2. Charger battery output through the polyfuse to the controller's battery pin: 0.2 mm².
3. Polyfuse to the 5 V boost on the front face: 0.2 mm², about 60 mm long, so the board can be laid aside while you work.
4. Boost 5 V output to the sensor's supply pins: 0.2 mm².
5. Sensor signals to the controller: 0.08 mm² (28 AWG), using the sensor's own cable.
6. Humidity breakout to the controller's I2C pins and 3.3 V: 0.08 mm².
7. Controller output to the boost's enable input, and to the motor driver: 0.08 mm².
8. Motor driver to the motor and to the LED: 0.08 mm², about 60 mm long.

Check that the charger's temperature window really is 0 to 45 °C in its datasheet before buying: some chargers of this class fix a different window.

**Check before moving on.** Every wire continues end to end; with no cell connected, the battery terminals read open to ground; every wire is labelled.

### 3.6 Rear shell

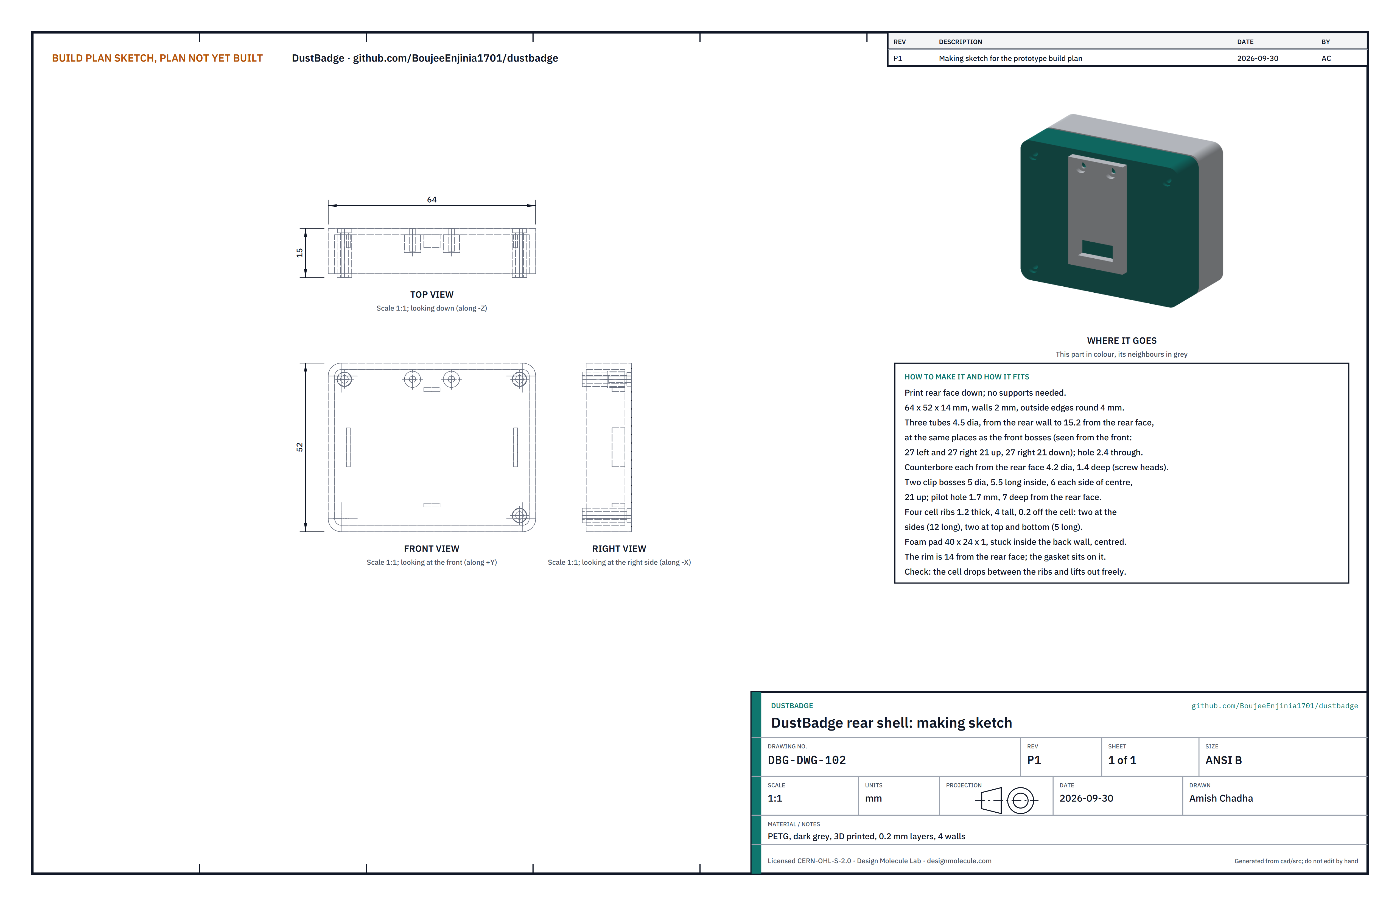
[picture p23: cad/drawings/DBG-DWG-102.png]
Figure 13. Making sketch of the rear shell


*Figure 13. Rear shell making sketch (DBG-DWG-102), front view looking into its open side.*

**What it is and what it is made from.** The dark back half of the badge, against the wearer, 64 x 52 x 14 mm, with three tubes for the shell screws, two bosses for the clip screws and four ribs that locate the cell. PETG, dark grey, printed at 0.2 mm layers with four walls.

**How to make it.**

1. Print it rear face down. No supports are needed.
2. Check the three tubes: 4.5 across with a 2.4 mm hole through, reaching 15.2 from the rear face, each counterbored 4.2 across and 1.4 deep from the rear face for a screw head.
3. Open the two clip bosses (6 each side of centre, 21 up) to 1.7 mm, 7 deep from the rear face.
4. Check the four cell ribs: 1.2 thick and 4 tall, 0.2 from the cell all round.
5. Cut the foam pad from 1 mm closed-cell foam sheet with an adhesive back, 40 x 24 mm, and stick it to the inside of the back wall, centred between the ribs. It sits 0.5 mm clear of the cell and takes up the cell's swelling.

**How it fits the parts next to it.**

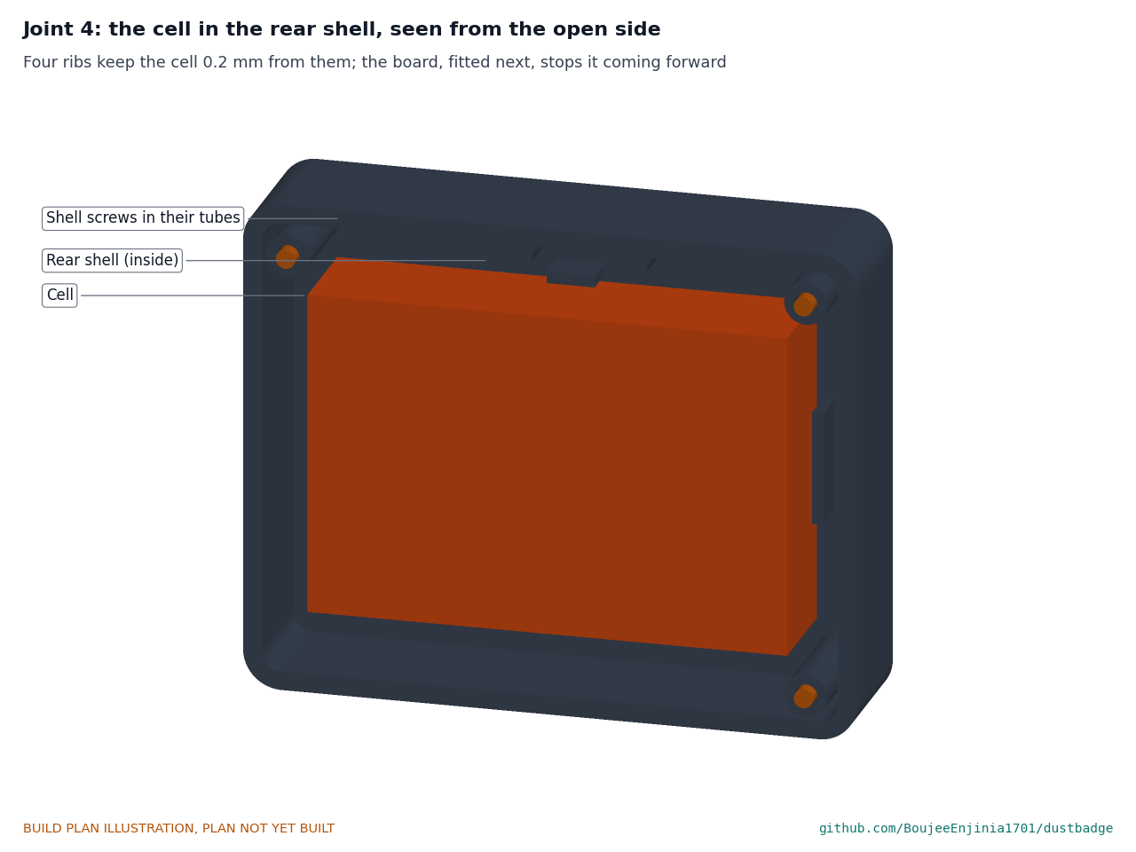
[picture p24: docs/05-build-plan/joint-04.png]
Figure 14. Joint 4: the cell in the rear shell


*Figure 14. The cell between its four ribs, seen from the open side, with the shell screws in their tubes.*

The cell sits between the ribs, with the foam pad on the rear wall behind it and 0.5 mm clear of it. The tubes press on the back of the board. The rim, 14 from the rear face, sits on the gasket.

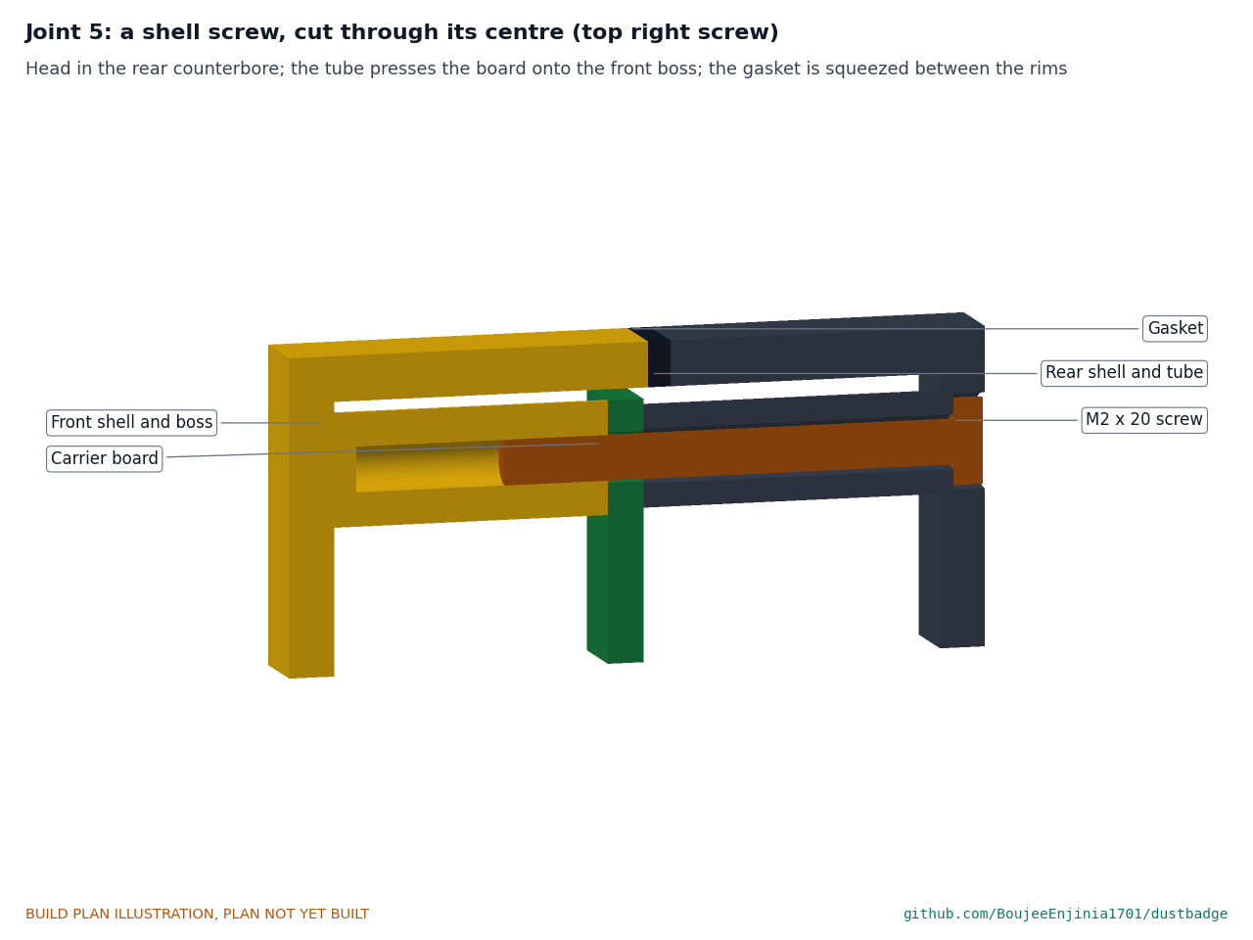
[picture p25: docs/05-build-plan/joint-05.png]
Figure 15. Joint 5: a shell screw


*Figure 15. A shell screw, cut through its centre: head in the counterbore, the tube pressing the board onto the front boss, the gasket squeezed between the rims.*

**Check before moving on.** The cell drops between the ribs and lifts out without force, and the pad is flat and does not touch the screw tubes or the clip bosses.

### 3.7 Spring clip, drilled

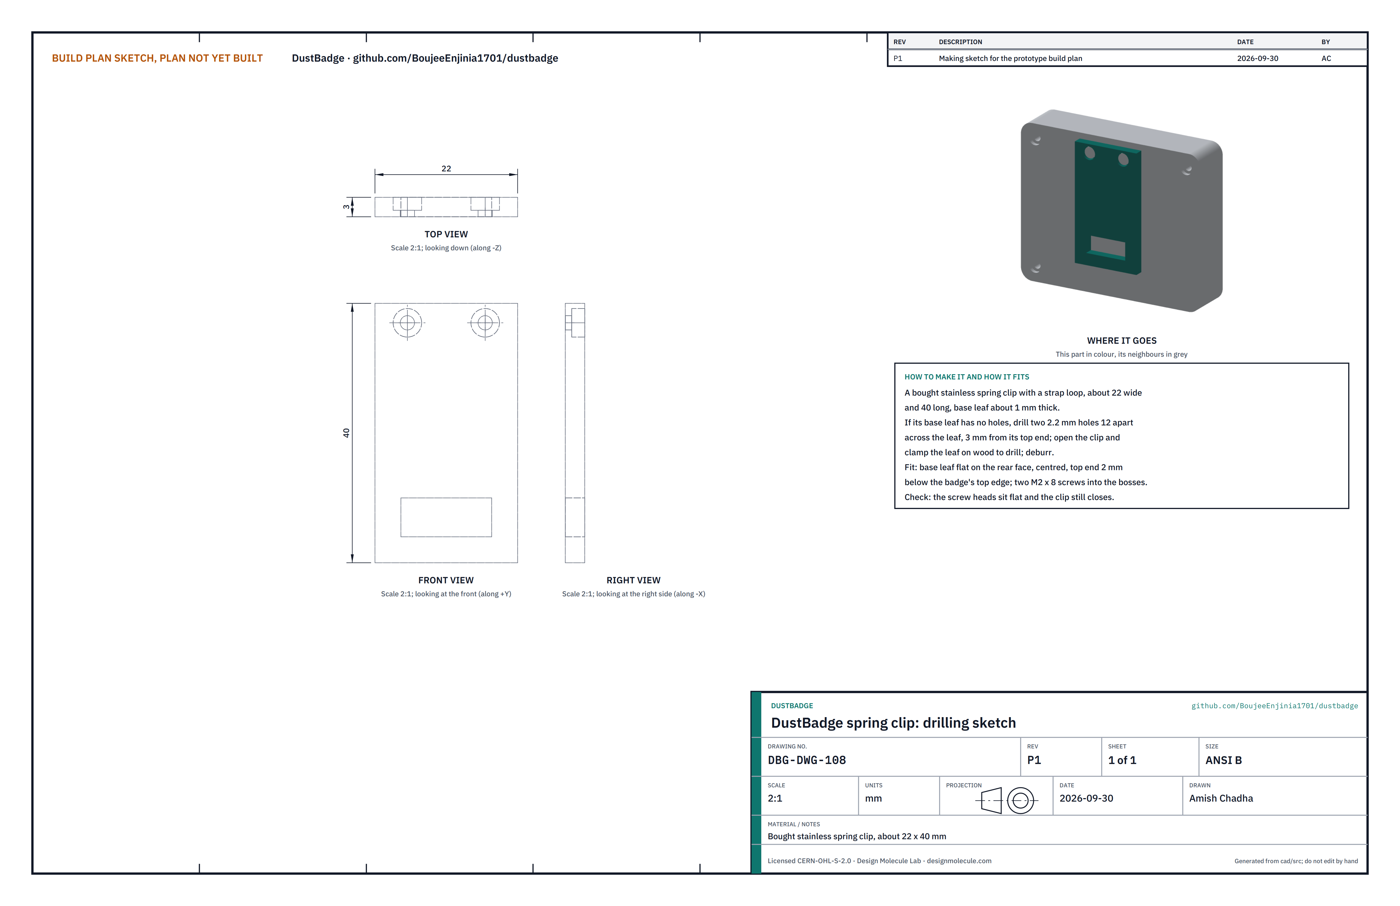
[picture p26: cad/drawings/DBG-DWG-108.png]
Figure 16. Drilling sketch of the spring clip


*Figure 16. Spring clip drilling sketch (DBG-DWG-108).*

**What it is and what it is made from.** A bought stainless spring clip with a strap loop, about 22 wide and 40 long, that holds the badge on a collar, pocket, harness strap or hi-vis vest.

**How to make it.**

1. If its base leaf has no holes, open the clip, clamp the base leaf on a piece of wood and drill two 2.2 mm holes across it, 12 apart and 3 mm from its top end.
2. Deburr both sides.

**How it fits the parts next to it.**

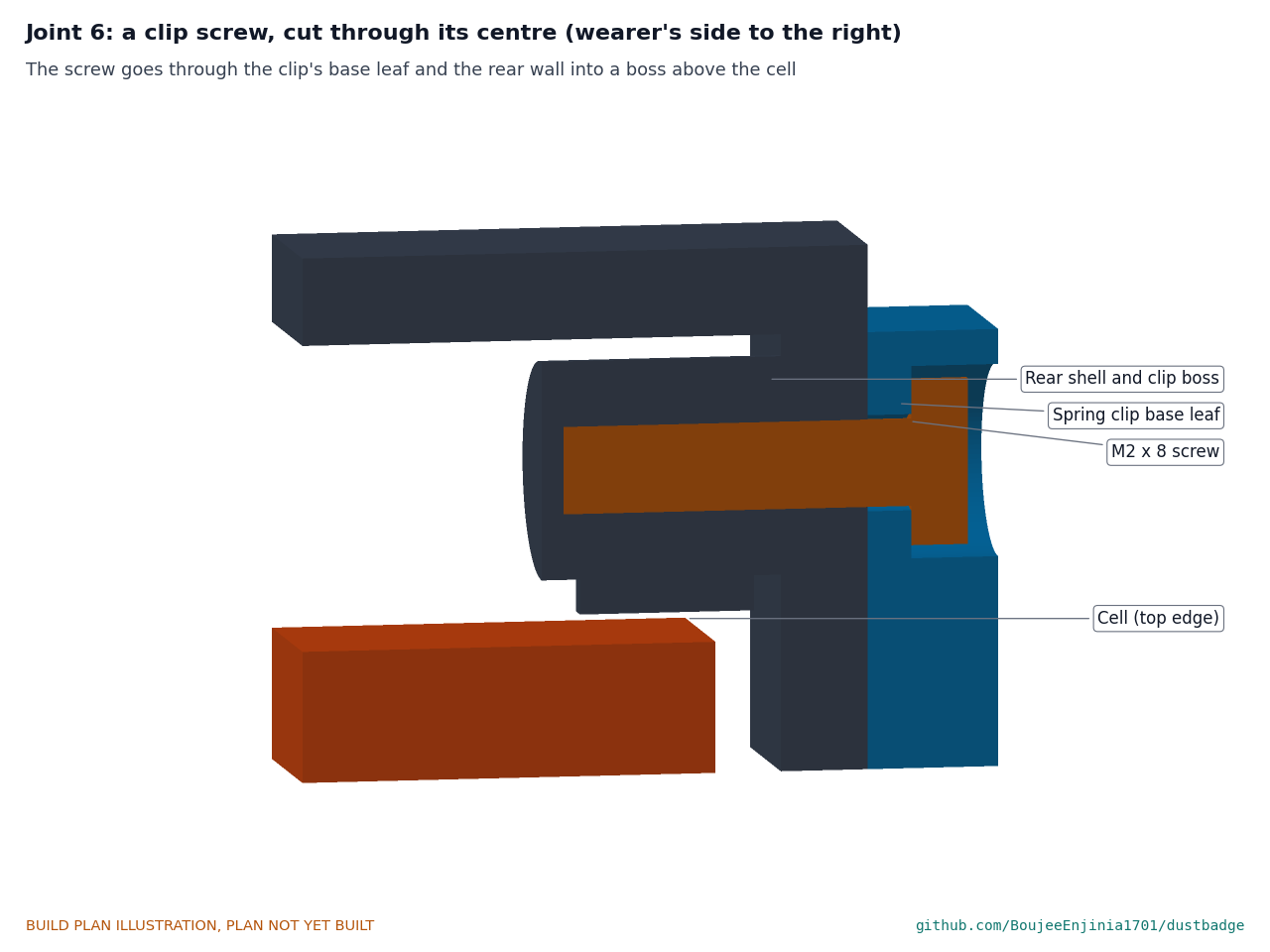
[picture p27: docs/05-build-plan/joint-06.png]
Figure 17. Joint 6: a clip screw


*Figure 17. A clip screw, cut through its centre: through the base leaf and the rear wall into a boss above the cell.*

The base leaf lies flat on the rear face, centred, its top end 2 mm below the badge's top edge. Two M2 x 8 thread-forming screws go through it into the two bosses, 3 mm clear of the cell.

**Check before moving on.** The screw heads sit flat and the clip still closes fully.

### 3.8 Gasket

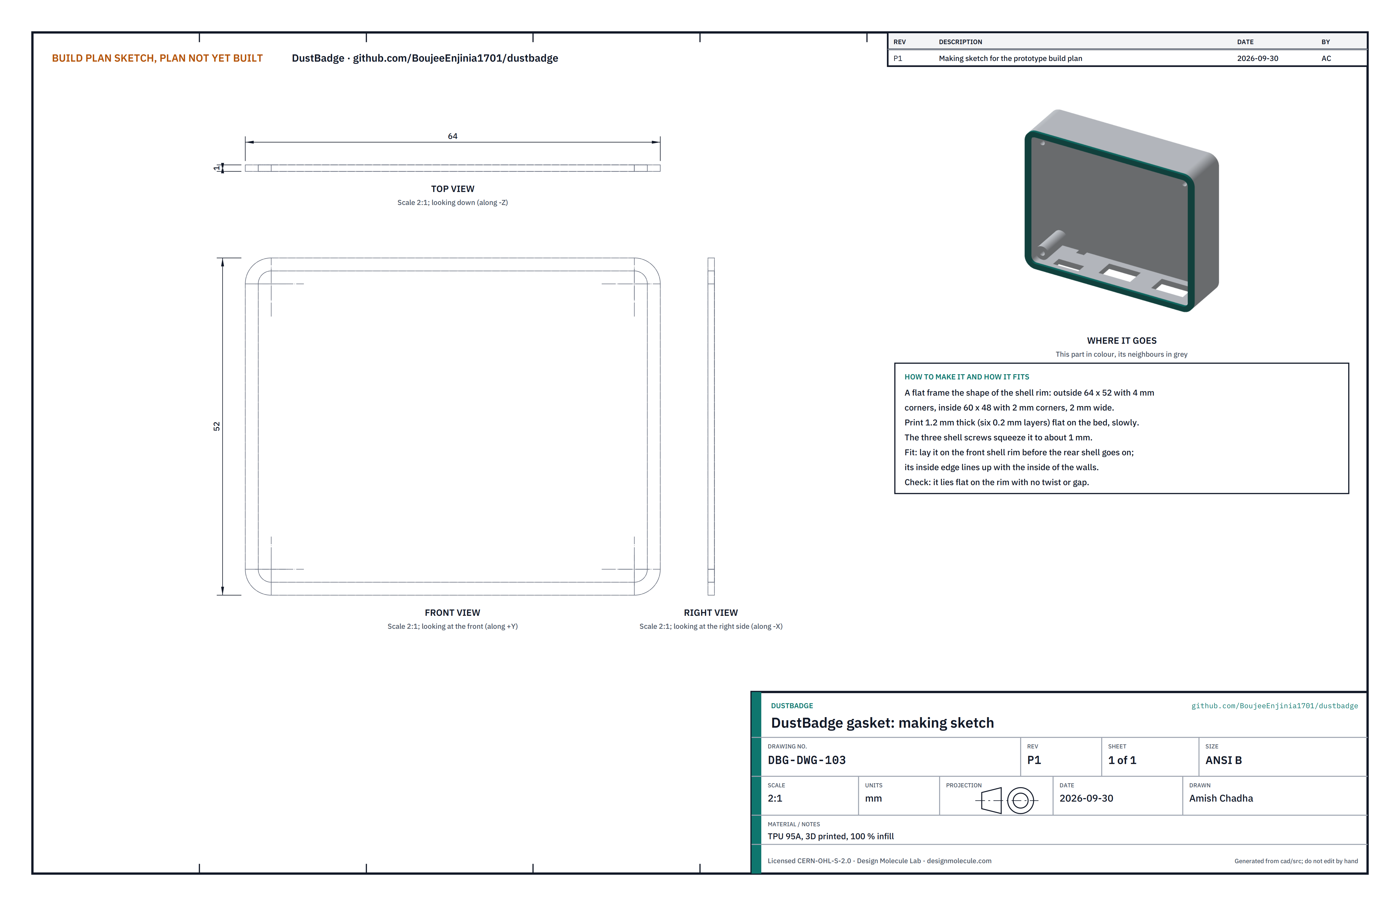
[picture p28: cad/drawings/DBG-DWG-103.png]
Figure 18. Making sketch of the gasket


*Figure 18. Gasket making sketch (DBG-DWG-103), shown in place on the front shell's rim.*

**What it is and what it is made from.** A flat frame that seals the joint between the two shells. TPU 95A, printed at 100 % infill.

**How to make it.** Print it flat and slowly, 1.2 mm thick (six 0.2 mm layers): 64 x 52 outside with 4 mm corners, 60 x 48 inside with 2 mm corners, 2 mm wide.

**How it fits the parts next to it.** It lies on the front shell's rim, its inside edge in line with the inside of the walls. The rear shell's rim sits on it, and the three shell screws squeeze it to about 1 mm (Figure 15).

**Check before moving on.** It lies flat on the rim with no twist or gap.

### 3.9 Bought components

Buy to specification, not brand. Line numbers are those of the bill of materials.

- **Particle sensor (line 3).** Sensirion SPS30 class: PM1, PM2.5, PM4 and PM10 mass, 0 to 1,000 µg/m³, 41 x 41 x 12 mm, 5 V, with its inlet and outlet on one narrow edge and its interface cable.
- **Controller (line 4) and carrier board modules (line 7).** As Table 2.
- **Vibration motor (line 5).** 10 mm coin motor, 3 V, about 3 mm thick, with an adhesive back and leads.
- **LED (line 6).** Red 3 mm LED.
- **Foam pad (line 13).** Closed-cell polyethylene foam sheet, 1 mm thick, with an adhesive back; a 40 x 24 mm piece is cut for each badge.
- **Cell (line 8).** 2,000 mAh 3.7 V protected lithium polymer cell, no larger than 50 x 34 x 11.5 mm including its protection board, with a 10 kΩ NTC lead, from a maker that publishes a datasheet.
- **Clip (line 10).** As section 3.7.
- **Fixings and consumables (line 11).** Three M2 x 20 and two M2 x 8 thread-forming pan-head screws for plastics; thin double-sided foam tape; 0.2 mm² and 0.08 mm² wire; heat shrink; clear adhesive.

## 4. Putting it together

In each picture the parts already fitted are grey and the part being fitted is in colour, with an arrow showing the way it goes in. Steps 1 to 6 are done with the front shell lying face down on a soft cloth, looking into its open back.

### Step 1: light pipe and LED into the front shell

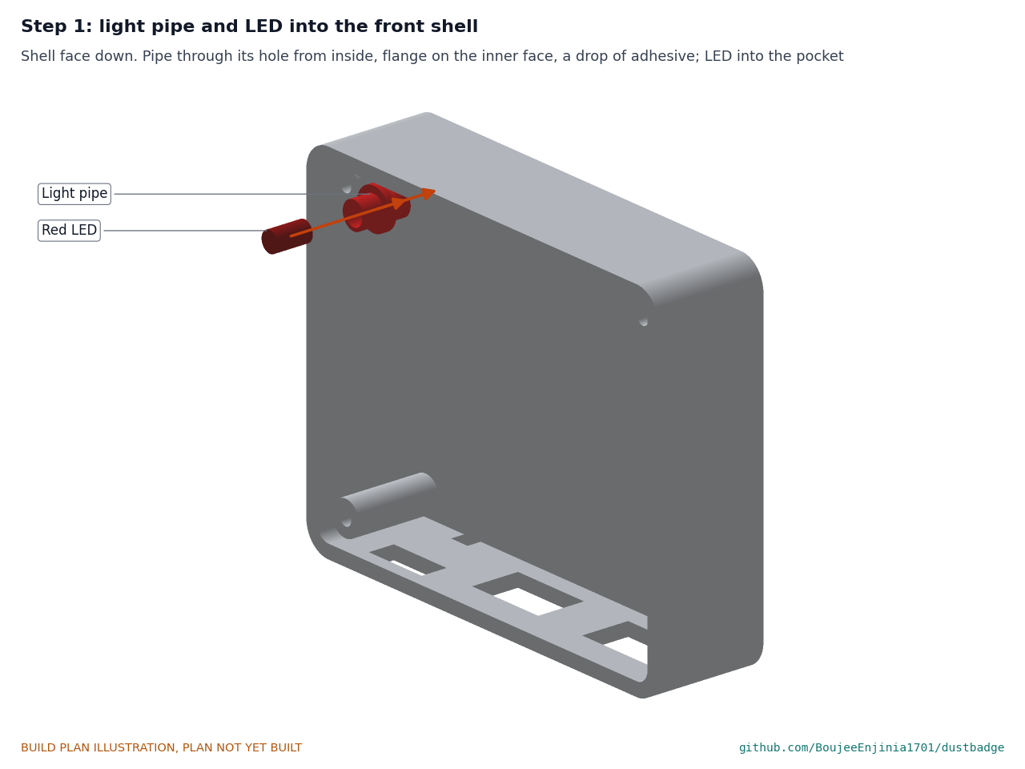
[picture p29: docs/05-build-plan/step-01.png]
Step 1


The pipe goes through its hole from inside, flange down on the inner face, with a drop of clear adhesive; then the LED goes into its pocket.

### Step 2: motor, boost module and humidity breakout onto the front face

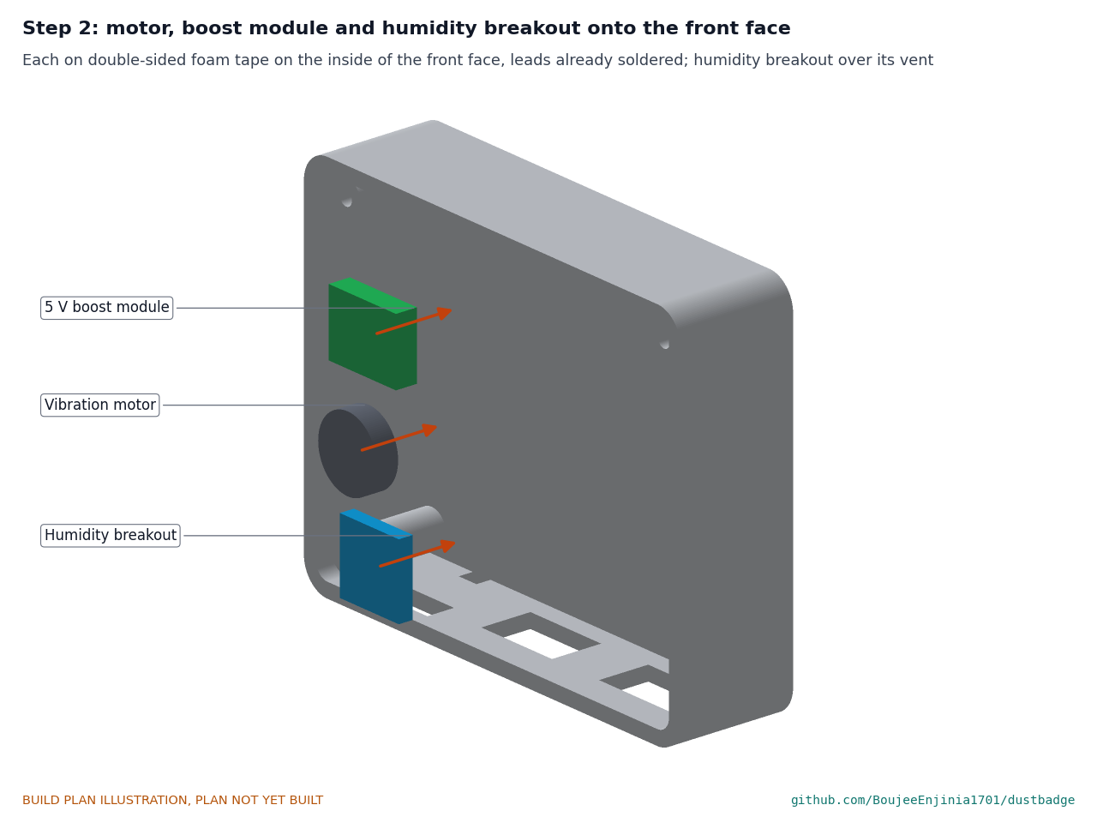
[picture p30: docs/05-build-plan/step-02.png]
Step 2


Each goes on a piece of thin double-sided foam tape on the inside of the front face, in the strip right of the sensor's place, with its leads already soldered: the boost module highest, the motor in the middle, the humidity breakout at the bottom, sitting on the floor over its vent.

### Step 3: screen and port seals onto the inner floor

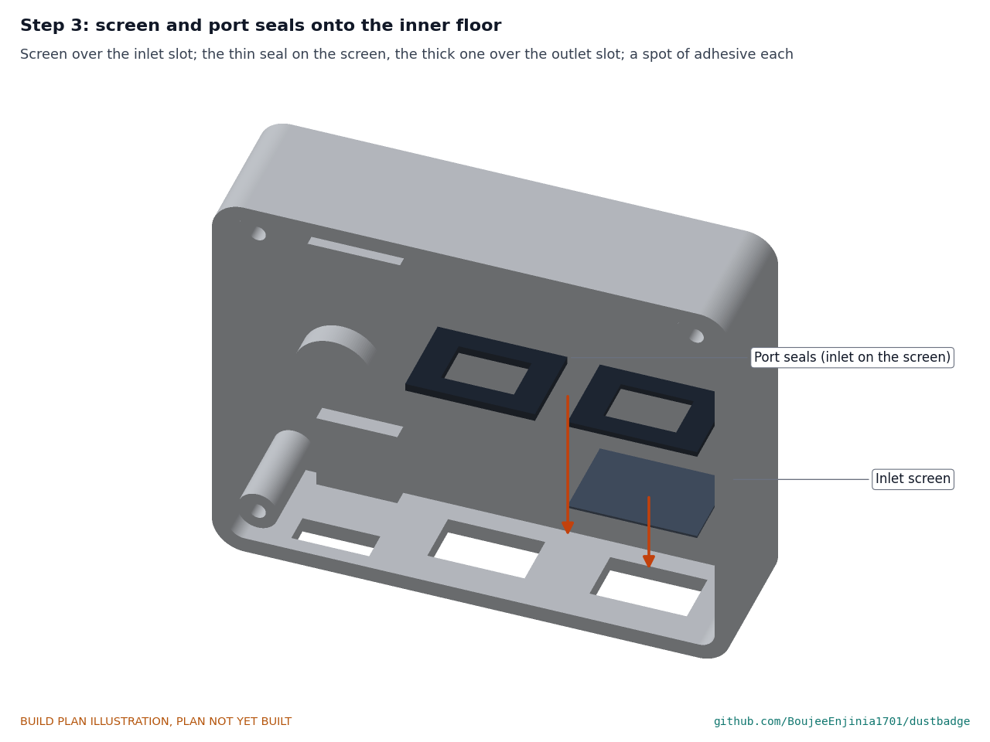
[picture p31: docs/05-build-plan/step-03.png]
Step 3


The screen over the inlet slot; the thin, marked seal on the screen; the thick seal over the outlet slot. A spot of adhesive at one corner of each seal.

### Step 4: particle sensor into its pocket

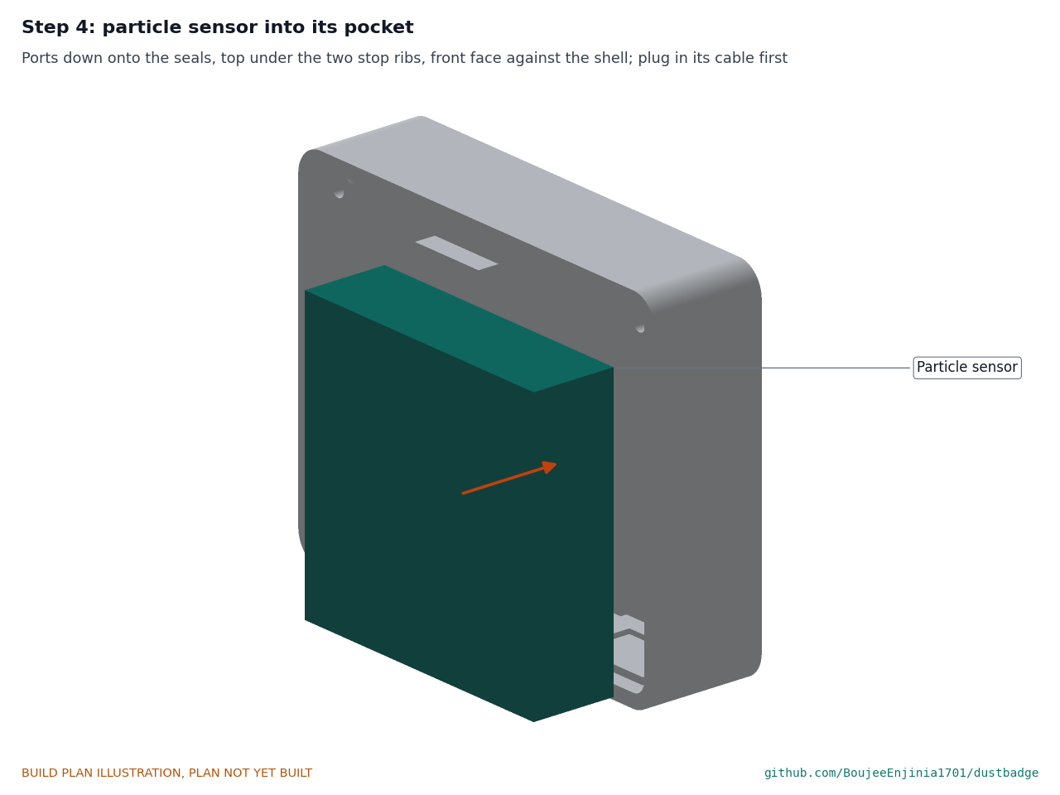
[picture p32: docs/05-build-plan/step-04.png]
Step 4


Plug in its cable first. Lower the sensor with its ports down onto the seals, its top under the two stop ribs and its front face against the shell. It should sit level and not rock.

### Step 5: build the carrier board

Step 5

As section 3.5. **Hold point:** the wiring checks of section 3.5.1 pass before going on.

### Step 6: carrier board onto the front bosses

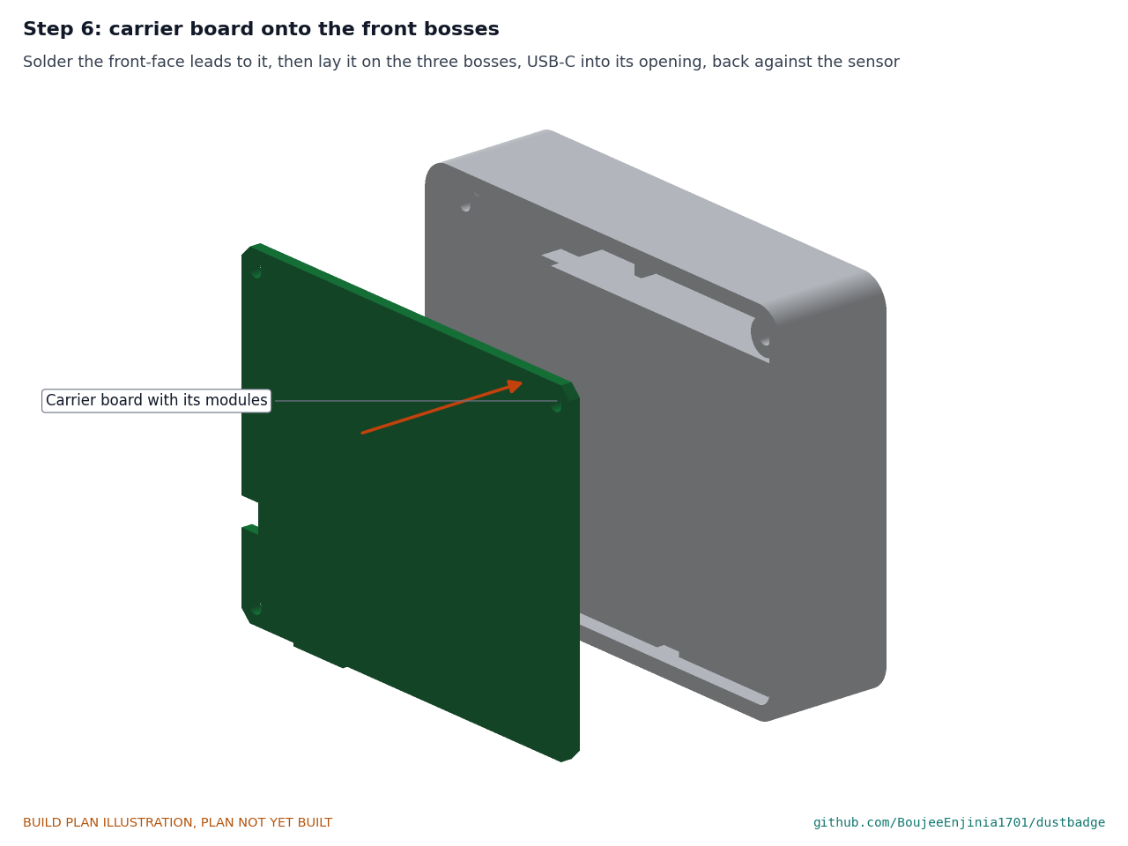
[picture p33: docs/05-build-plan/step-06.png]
Step 6


Solder the leads from the front-face parts and the LED to the board and plug in the sensor cable. Lay the board on the three bosses, front face toward the sensor, with the USB-C in its opening. **Hold point:** no wire lies across a boss, the rim or the sensor's seals.

### Step 7: spring clip onto the rear shell

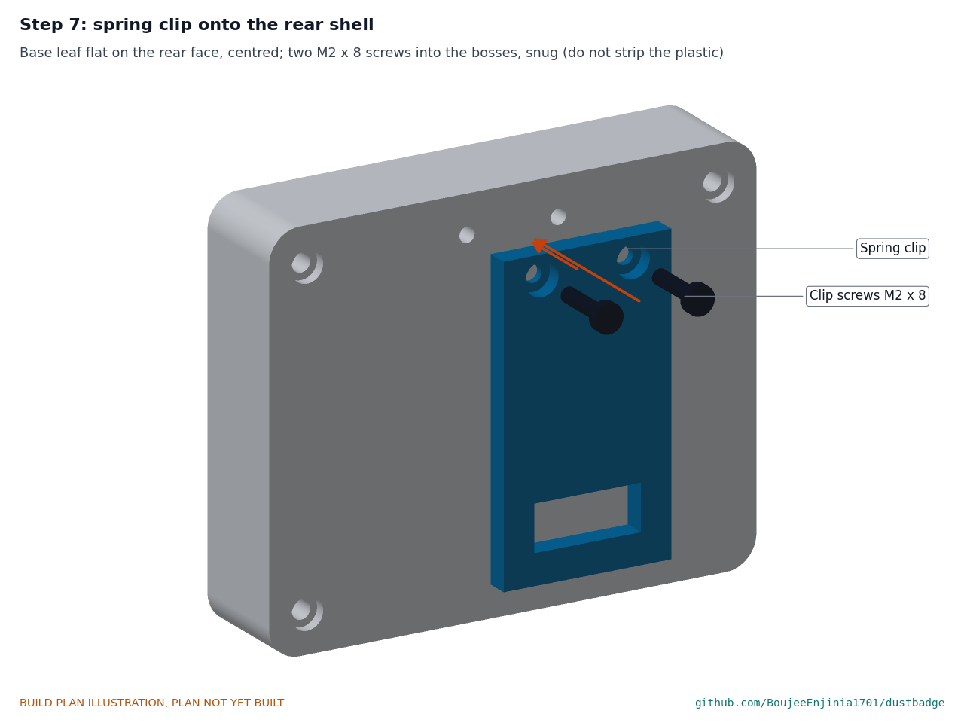
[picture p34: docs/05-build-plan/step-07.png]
Step 7


Base leaf flat on the rear face, centred; two M2 x 8 screws into the bosses, snug. Thread-forming screws strip PETG if overtightened: stop when the head seats.

### Step 8: foam pad and cell into the rear shell

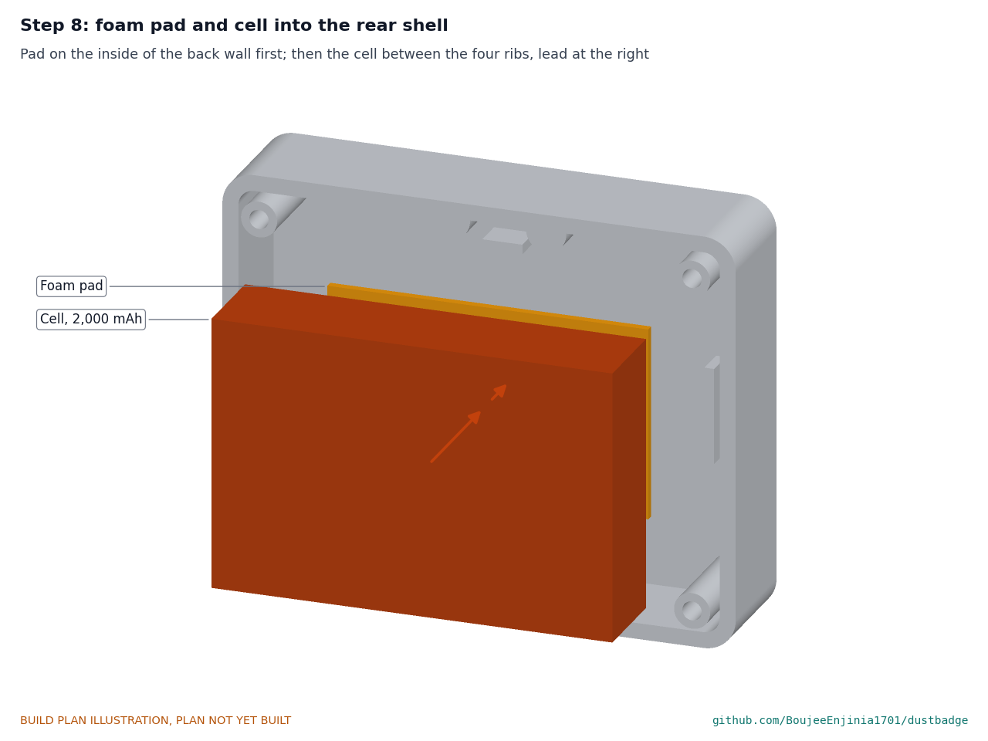
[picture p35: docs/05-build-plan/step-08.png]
Step 8


**Hold point:** safety stops S1 to S4 in section 6. Stick the foam pad to the inside of the back wall, centred. Lay the cell between the four ribs with its lead at the right, pass the lead through the notch in the board and plug it into the charger module.

### Step 9: close the badge

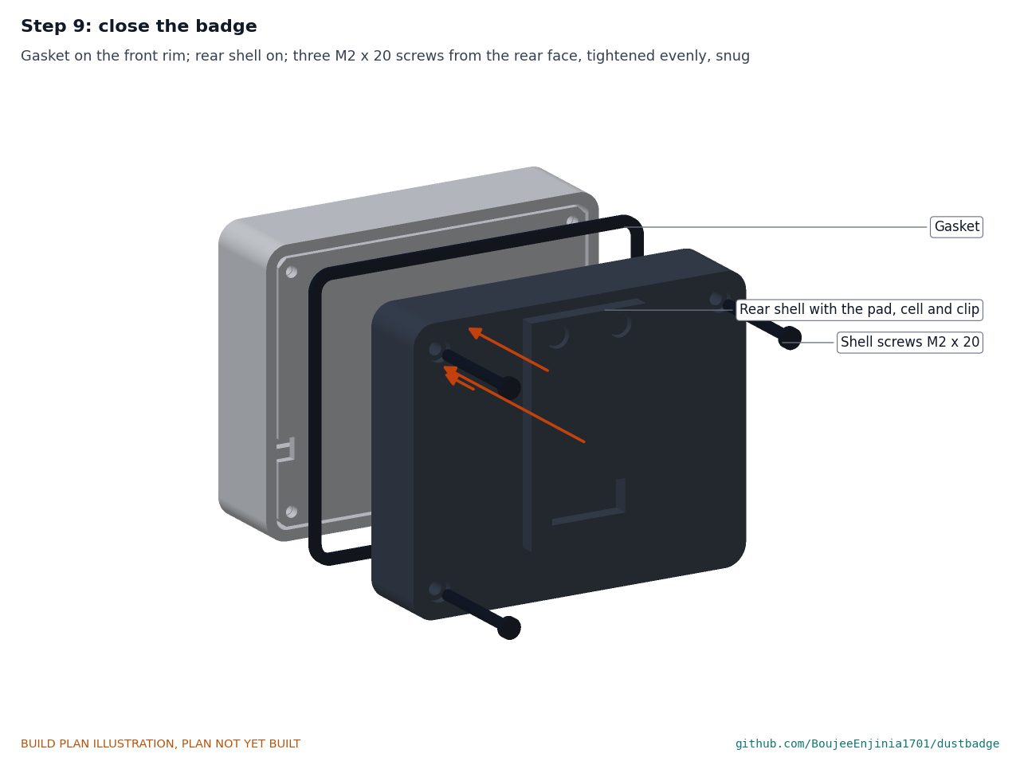
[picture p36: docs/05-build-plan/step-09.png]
Step 9


Lay the gasket on the front rim. Fit the rear shell, checking that no wire is caught on the rim or between the cell and the board. Fit the three M2 x 20 screws from the rear face and tighten them in turn, a little at a time, until the gasket is evenly squeezed and the joint is closed all round. **Hold point:** safety stop S5.

## 5. First checks

These are the checks a TRL 4 test report would record; this plan only lists them. Requirement numbers are those of DBG-REQ-001.

*Table 3. First checks.*

| Check | Requirement | How | Pass when |
| --- | --- | --- | --- |
| Charge voltage and current | R7 | USB power meter between a phone charger and the badge; cell connected, badge on the bench | Charging ends at 4.2 V, give or take 0.05 V; current 500 mA or less |
| Cold and hot charge stop | R11 | Replace the cell's NTC with a resistor equal to its value at -1 °C, then at 46 °C | No charge current in either case (under 10 mA) |
| Air path | R1 | Badge closed; hold a smoke source 50 mm below the inlet, then cover the inlet slot with tape | The reading rises with smoke and falls to near zero with the inlet covered |
| Alert | R6 | Trigger the alert from the firmware sketch | The motor is felt through a shirt and the LED is seen from 2 m |
| Log over Bluetooth | R12 | Run 1 h, then pull the log to a phone | 60 one-minute records arrive |
| Humidity reading | R11 | Breathe gently at the bottom face | The humidity reading rises within 30 s |
| Shell joint | R10 | Feeler gauge round the joint after closing | No gap over 0.2 mm anywhere |
| Run time | R7 | Full charge, continuous sampling at room temperature | 12 h or more |
| Mass and size | R9 | Weigh on a 0.1 g scale; measure with calipers | 122 g or less (120.7 g estimated); 64 x 52 x 34 mm with the clip, 35 mm with the light pipe |
| Worn position | R8 | Clip to a collar or harness strap | The inlet faces down and is within 300 mm of the nose and mouth |

## 6. Safety stops

Stop at each point. Carry on only when everything listed is true.

- **S1. Before the cell comes into the workshop.** The cell is a protected cell from a maker that publishes a datasheet, at 3.6 to 4.0 V, with no swelling, dents or leaks. A charging spot is ready on a non-combustible surface (a ceramic tile or steel tray), away from anything that burns.
- **S2. Before the cell is plugged in.** The polarity of the cell's plug matches the charger module's socket, checked with a meter, not by wire colour: small connectors of this kind are made both ways round. With no cell, the charger's battery terminals and every supply read open to ground.
- **S3. Before any charging.** Both charge-stop checks of section 5 pass with the substitute resistors. The cell's NTC is then reconnected and lies against the cell.
- **S4. First charge.** Attended the whole time, with the badge open on the charging spot, the cell checked by hand every 15 minutes. Stop if the cell becomes warm to the touch, swells or smells, or if the charger reads above 4.25 V. Never bypass the charge stop.
- **S5. Before the badge is closed.** No wire is pinched under the board or across the gasket; the cell lead runs through the notch; the cell lies flat between its ribs.
- **S6. Before the badge is worn.** It is worn only for bench and indoor trials until a TRL 4 test plan says otherwise; never while charging; never in a gassy mine or any place with flammable gas or combustible dust; shaded when the ambient is above 40 °C in full sun. Its reading is a research estimate: it never replaces a respirator, engineering controls or regulatory sampling.
- **S7. At every charge.** Look at the cell through the open badge from time to time: retire it at the first sign of swelling, damage or heat. This is the worn version: the rear shell is 1 mm deeper and a foam pad sits behind the cell, so the cell has 0.2 mm in front, 0.5 mm clear behind the pad and the soft pad to swell into (decided by Amish, 2026-10-02). Do not build the shallower bench version for anyone to wear.

## 7. Tools, skills and workspace

**Tools.** 3D printer with a bed of at least 70 x 60 mm that prints PETG and TPU 95A (a direct-drive extruder helps with TPU); craft knife; fine snips; hand drill or pin vice with 1.7, 2.2 and 2.4 mm drills; small files; calipers; steel rule; soldering iron with a fine tip, solder and flux; wire strippers; heat gun for heat shrink; multimeter; USB-C power meter; small cross-head screwdriver; feeler gauges; scale reading to 0.1 g; two resistors to stand in for the NTC (values from the cell's datasheet).

**Skills.** No certified trade is needed. Basic 3D printing in PETG and TPU, fine soldering of modules and wires, and care with lithium cells. All circuits are extra-low voltage: 4.2 V at most on the cell, 5 V from USB and on the sensor supply. The USB charger must be a certified, undamaged unit; no mains wiring is part of this build.

**Workspace.** A bench about 1.0 x 0.6 m with an anti-static mat; a ventilated place for printing and soldering; the charging spot of S1.

**Personal protective equipment.** Safety glasses for soldering, cutting mesh and drilling; a fume extractor or open window when soldering.

## 8. Where the numbers come from

- Model and constructability checks: `cad/src/model.py` (`python cad/src/model.py --check`, 47 checks); STEP and STL exports in `cad/step/` and `cad/stl/`.
- Pictures: `cad/src/build_plan_media.py`, using `.kit/build_views.py`; written to `docs/05-build-plan/` and `cad/drawings/DBG-DWG-101` to `DBG-DWG-108`.
- General arrangement: `cad/drawings/DBG-DWG-001.pdf`, Rev P5.
- Calculations: `docs/04-calcs/01-sizing.md` (DBG-CAL-001 v0.7) and `docs/04-calcs/sizing.py`; mass [J1], [J2]; drop retention [K1]; run time [A3]; cost [L1, L2]; low-voltage cutoff [A7].
- Bill of materials: `bom/bom.csv`.
- Decisions: `docs/decisions/0003-design-for-construction.md` (DBG-DDR-003), with DBG-DDR-001 and DBG-DDR-002.
- Requirements: `docs/03-requirements.md` (DBG-REQ-001 v0.9).

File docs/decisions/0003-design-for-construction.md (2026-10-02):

---
doc_id: DBG-DDR-003
title: DustBadge design for construction
project: DustBadge
doc_type: Design decision record
version: "0.3"
status: Draft
date: '2026-10-02'
author: Amish Chadha
license: CERN-OHL-S-2.0
revisions:
- version: "0.1"
  date: '2026-09-30'
  author: Amish Chadha
  change: Changes that make the concept physically buildable, with the reason for each; made under Amish's 2026-09-30 instruction to make the design physically buildable; open for his review
- version: "0.2"
  date: '2026-10-01'
  author: Amish Chadha
  change: Budget treated as a value-engineering target
- version: "0.3"
  date: '2026-10-02'
  author: Amish Chadha
  change: 'Accepted by Amish on 2026-10-02 with the drop-test addition; A1 (as changed in review), A2 and A3 decided; record stays Draft'
---

# 0003: Design for construction

- **Date:** 2026-09-30
- **Status:** accepted. Amish, 2026-10-02: "i approve your recommendations for all 555 open decisions." This covers every change in Tables 1 and 2, with one addition: the TRL 4 drop test also checks that the boost module, humidity board and motor stay on their foam tape. The questions in Table 3 (A1 to A3) are decided as recommended in review and recorded in the design decisions register (DBG-DEC-001); A1 was changed in review, so the badge is deepened before anyone wears it. The record stays Draft.

## Context

On 2026-09-30 Amish asked for every repo to have an illustrated build plan and wrote: "If you are realising that the design cannot be built as per concept - fix the design assumptions to match and be physically feasible as you draw the illustrations." The DustBadge model of DBG-DDR-002 showed what the badge does and that it fits its envelope, but it was a massing model: the shells had no closure, several parts floated with nothing holding them, the sensor's air path was open to the inside of the badge, and the carrier board's modules were not placed. Checking the model with build123d (overlaps, contacts and clearances between every pair of parts that meet) found the ten problems below.

The changes keep what the badge does: the same 64 x 52 x 30 mm envelope (33 mm with the clip), the same sensor, cell, controller, downward screened inlet, alert motor and LED, the same charger and humidity sensor, and the same parts cost. Nothing here changes the pitch. Every change is in `cad/src/model.py`, which now runs 43 constructability checks (`python cad/src/model.py --check`): parts that must touch do touch with no overlap, and parts that must not touch are apart by at least the stated clearance. All 43 pass.

## Decision

*Table 1. Changes made to the model, the BOM and the calculations.*

| # | Problem in the concept | Change made | Why this way |
| --- | --- | --- | --- |
| P1 | The shells had no fasteners. The three front bosses stopped 0.2 mm short of the carrier board, and nothing stood between the board and the rear shell 14 mm behind it. | Three tubes 4.5 mm across in the rear shell press the board onto the three front bosses (now ending at the board). Three M2 x 20 thread-forming pan-head screws go in from the rear face, heads in 4.2 mm counterbores 1.4 mm deep, through the tubes and the board into 1.7 mm pilot holes in the front bosses. | One screw path closes the badge, clamps the board and squeezes the gasket. The screws match the product renders' rear screws (REVIEW 2026-09-26, item 3) and are within BOM line 11. Screws from the rear keep the hi-vis front face unbroken. |
| P2 | The TPU gasket of BOM line 9 was not modelled and had no room: the rims met face to face. | A flat printed TPU frame the shape of the rim (64 x 52 outside, 2 mm wide), 1 mm thick when squeezed. The rear shell is 1 mm shallower (13 mm) so the badge stays 30 mm deep. | A flat gasket needs no groove in a 2 mm wall and is printed from the TPU already in line 9. |
| P3 | The sensor's inlet and outlet ports hovered 1 mm above the floor slots, so the fan could draw air from inside the badge and recirculate its own exhaust. | Two printed TPU port seals, 16 x 11 mm with a 9 x 6 mm opening: 0.7 mm thick on the inlet (over the screen), 1.0 mm on the outlet. The sensor rests on both. | The fan now draws only outside air through the screened inlet, which the concept assumed. Different thicknesses keep the sensor level over the screen. |
| P4 | The 1.2 mm inlet screen sat "flush in the slot" with nothing holding it, and BOM line 2 gave a 30 x 8 mm piece. | A 16 x 11 mm square of 0.3 mm mesh laid on the inner floor over the inlet slot, held down by the inlet seal. | The seal both clamps and seals the screen; no adhesive in the air path. |
| P5 | Nothing held the sensor upward: 6 mm of space above it, and it needs 194 to 387 N of retention in a drop [DBG-CAL-001, K1]. | Two stop ribs 1.2 mm thick in the front shell, 20 mm left and 2 mm right of centre, 7 mm deep from the front face, their lower edges 0.2 mm above the sensor. With the seals below and the board behind, the sensor is boxed in. | Ribs print with the shell and leave room for the sensor's cable beside them. |
| P6 | The boost and charger modules and the humidity sensor were not placed; the humidity vent opened under the sensor, where only 1 mm of space was left; the USB-C socket was modelled 3.6 mm long where a receptacle is about 7.3 mm. | The charger module (about 11 x 19 mm, with its USB-C on its lower edge, mouth 0.8 mm inside the face) sits on the board's right-hand strip below the controller. The 5 V boost module, the humidity breakout and the vibration motor are stuck with foam tape to the inside of the front face, in front of the controller, on flying leads. The USB-C opening moves from 16 to 18.1 mm right of centre and grows to 9.6 x 3.8 mm; the humidity vent moves from 8 to 18.5 mm right, 3 mm behind the front face, under the breakout. The controller moves 0.2 mm left to clear the side wall. | The only free space in the 12 mm between the front face and the board is the strip to the right of the sensor; two layers use both its depth and its height. |
| P7 | The 56 x 44 mm board's screw holes broke its edges (centres 1 mm from the edge). | Board 59 x 47 mm with its corners cut 1.5 mm at 45° to clear the shells' inside corners; 1.4 mm of board round each hole; a 3 x 4 mm notch in the right edge for the cell lead. | Uses the 0.5 mm left between the board and the walls; the corner cuts keep it clear of the 2 mm inside radius. |
| P8 | The cell could slide 5 mm sideways and 7 mm up and down behind the board; it needs 280 to 559 N of retention in a drop [K1]. | Four locating ribs 1.2 mm thick and 3 mm tall on the inside of the rear wall, 0.2 mm from the cell's sides, top and bottom. The board stops it coming forward. | Holds the cell without glue, so it can be inspected and replaced. |
| P9 | The spring clip had no fixing to the rear shell, and the cell lies 0.5 mm behind the rear wall, so nothing could pass through the wall over it. | Two M2 x 8 thread-forming screws through the clip's base leaf (two 2.2 mm holes 12 mm apart, drilled if the bought clip has none) into two bosses inside the rear shell, 6 mm each side of centre and 21 mm up, above the cell. | The only place above the cell clear of the shell screws; the bosses double as a stop over the cell. |
| P10 | The light pipe was a plain rod with nothing holding it, and no LED behind it: the board is 10 mm back from the front face. | A printed clear PETG pipe: a 4 mm rod with a 6 mm flange that sits on the inside of the front face, standing 1 mm proud outside, and a 3 mm pocket in its inner end for the red LED on leads. | The flange takes the push from outside; the LED sits where the light pipe needs it. |

*Table 2. Knock-on changes.*

| Item | Change | Reason |
| --- | --- | --- |
| Mass | 119.9 g (was 119.8 g); R9 margin 0.1 g (was 0.2 g) [DBG-CAL-001 v0.5, J2]. The gasket and seals are now taken from the model volume in TPU (0.8 g, was an assumed 1.0 g); the rear tubes are 4.5 mm and the stop ribs 1.2 mm to keep the badge under 120 g. | Bosses, ribs and seals added for construction. |
| Cost | Unchanged at an estimated $91.00, within the $91 value-engineering target. Specifications of BOM lines 2, 6, 7, 9, 10 and 11 updated; no price changed. | The gasket and seals use line 9's TPU; the screws, foam tape and the motor driver parts fall within lines 7 and 11. |
| Drawings | DBG-DWG-001 Rev P4; making sketches DBG-DWG-101 to 108 added. | Follows the model. |
| Documents | DBG-CAL-001 v0.5, DBG-PRC-001 v0.7, DBG-REQ-001 v0.7. No requirement changed status. | Follows the model. |
| Run time, heat, breathing zone | Unchanged: the electrical loads, the envelope and the inlet position are the same. | |

*Table 3. Questions on the safety case and what the product does; decided by Amish on 2026-10-02.*

| # | Question | Options | Recommendation |
| --- | --- | --- | --- |
| A1 | Cell swelling allowance. The cell has 0.7 mm of free depth (0.2 mm in front, 0.5 mm behind), about 6 % of its 11.5 mm; pouch cells can swell more as they age. This is part of the lithium-cell safety case. | (a) accept for the prototype, inspect the cell at each charge and retire it at the first visible swelling; (b) deepen the badge by 1 mm and add a foam pad behind the cell (about 1.5 g more, so R9 is no longer met). | (a) for the prototype; revisit at TRL 4 with the bought cell's datasheet. **Decided by Amish, 2026-10-02, as changed in review:** (a) only for bench work with nobody wearing the badge; before anyone wears it, (b), with R9 relaxed to 122 g. Return to (a) only if the bought cell's datasheet states swelling under about 6 %. |
| A2 | On and off. The concept has no switch, so the sensor runs until the cell's protection cuts out unless firmware turns it off. | (a) firmware only: the controller switches the boost off through its enable input and sleeps, and wakes on USB power; (b) a reed switch inside with a magnet outside (no new opening); (c) a sealed push button (a new opening in the shell). | (a): no change to the shell; the enable line is already wired. **Decided by Amish, 2026-10-02:** (a), with a firmware low-voltage cutoff set above the cell protection threshold so the cell is never run down to the protection cut-out. |
| A3 | The R9 mass margin is 0.1 g on catalogue masses. | (a) accept, weigh the prototype at TRL 4; (b) look for mass now (for example a 1.8 mm rear wall). | (a). **Decided by Amish, 2026-10-02:** (a); with the deeper shell of A1 the R9 limit is 122 g. |

## Consequences

- `design_state: constructable` in `project.yaml`. The build plan DBG-BLD-001 shows every component and step in pictures generated from the model (`cad/src/build_plan_media.py`).
- Requirement status is unchanged: one not met (R14, out of scope), two at risk (R3, R11), one not verifiable at TRL 3 (R10), seven met on paper and four met by design (DBG-CAL-001 v0.5).
- R10 (drop and ingress) is still not verifiable at TRL 3, but the sensor and cell now have a load path and the shell joint has a gasket, so the drop and spray tests at TRL 4 have something to test.
- The photoreal renders (`media/render-*.png`), `media/card.png` and `media/social-preview.png` still show the concept: the USB-C opening and humidity vent have moved, the clip screws are new and the gasket is now a flat 1 mm band. They need regenerating on Amish's Mac, where Blender is. `cad/src/product_model.py` still runs against the new model.
- The bought modules, sensor connector, cell and clip are chosen at TRL 4; their sizes must be checked then (DBG-DEC-001, items to confirm).

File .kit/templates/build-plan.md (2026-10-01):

---
doc_id: PRJ-BLD-001
title: Project prototype build plan
project: Project name
doc_type: Build plan
version: "0.1"
status: Draft
date: YYYY-MM-DD
author: Amish Chadha
license: CERN-OHL-S-2.0
revisions:
  - version: "0.1"
    date: YYYY-MM-DD
    author: Amish Chadha
    change: First build plan; design made constructable
---

# Project prototype build plan

**Plan, not yet built.** How to build the first proof-of-concept prototype, component by component. Building and testing to it is TRL 4 work. Decisions still to be made are kept in the design decisions register (`docs/06-design-decisions.md`), not here.

## 1. What you are building

Every component, pulled apart and numbered in build order

One short paragraph: what the prototype is, how many components, which are made and which are bought, and the main ways they are made.

## 2. What changed to make it buildable

| Component | The concept had | The buildable design has | Why |
| --- | --- | --- | --- |

## 3. Making the components

### 3.1 Component name

Making sketch

**What it is and what it is made from.**

**How to make it.**

1. Mark out ...
2. Cut ...

**How it fits the parts next to it.**

Close-up of the joint

**Check before moving on.**

## 4. Putting it together

### Step 1: ...

Step 1

## 5. First checks

| Check | Requirement | How | Pass when |
| --- | --- | --- | --- |

## 6. Safety stops

## 7. Tools, skills and workspace

## 8. Where the numbers come from

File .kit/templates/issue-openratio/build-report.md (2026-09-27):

---
name: Build report
about: Tell us what happened when you built, printed or tested part of this design
title: "Build report: "
labels: build-report
---

This is a research and educational prototype, not a medical device. It is a TRL 3 concept and is not released for fabrication. If you build any part of it, you do so at your own risk. Reports help everyone.

**What you built** (part, sub-assembly or test)

**Materials, tools and settings**

**What worked**

**What did not work, with photos or measurements if you have them**

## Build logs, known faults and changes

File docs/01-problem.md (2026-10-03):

---
doc_id: DBG-PRB-001
title: DustBadge problem statement
project: DustBadge
doc_type: Problem statement
version: "0.8"
status: Draft
date: '2026-10-02'
author: Amish Chadha
license: CERN-OHL-S-2.0
revisions:
- version: "0.1"
  date: '2026-09-25'
  author: Amish Chadha
  change: Initial scaffold
- version: "0.2"
  date: '2026-09-25'
  author: Amish Chadha
  change: Populate to TRL 2 (problem, users, context, constraints, prior work with sources)
- version: "0.3"
  date: '2026-09-25'
  author: Amish Chadha
  change: "TRL 3, record decisions D3 and D6 from DBG-DDR-001 (adopted for TRL 3 pending Amish's review); partner and silica fraction method stay open"
- version: "0.4"
  date: '2026-09-25'
  author: Amish Chadha
  change: "Recommendations accepted by Amish (DDR-002): D3 and D6 decided; low-dust reference rule noted; partner and silica fraction method stay open"
- version: "0.5"
  date: '2026-09-26'
  author: Amish Chadha
  change: Budget approved by Amish; constraint now $91
- version: "0.6"
  date: '2026-10-01'
  author: Amish Chadha
  change: Budget treated as a value-engineering target
- version: "0.7"
  date: '2026-10-01'
  author: Amish Chadha
  change: BioMedical area (DBG-DEC-001 v0.3); constraints state a research and educational prototype, not a medical device
- version: "0.8"
  date: '2026-10-02'
  author: Amish Chadha
  change: 'Estimated cost USD 91.50, USD 0.50 over the value-engineering target (foam pad of the worn version)'
---

# DustBadge problem statement

Respirable crystalline silica (RCS) causes silicosis, which is incurable, yet most exposed workers never learn their own exposure while it can still be changed. Personal sampling with a pump and filter is costly, needs a trained hygienist, and reports a single shift average days later, so a worker cannot tell during the shift that a saw, a dry sweep or a dusty haul road is putting them over the limit.

## The problem

Silicosis killed more than 12,900 people worldwide in 2019, and the burden falls hardest on lower-income regions where protection is weakest ([Chen, Liu and Xie, BMC Pulmonary Medicine, 2022](https://link.springer.com/article/10.1186/s12890-022-02040-9)). In the United States about 2.3 million workers are exposed, and OSHA estimated that its 2016 limit of 50 µg/m³ (8 h average) would prevent more than 600 deaths a year once fully effective ([US Department of Labor, 2016](https://www.dol.gov/newsroom/releases/osha/osha20160324)). An estimated 44 million artisanal and small-scale miners work mostly in developing economies, and a systematic review found a pooled silicosis prevalence of 23.9 % among those studied, with some disease after fewer than 6 years of mining ([Howlett et al., PLOS Global Public Health, 2023](https://journals.plos.org/globalpublichealth/article?id=10.1371%2Fjournal.pgph.0002085)).

Limits exist, but exposure is rarely measured where the work happens. The reference method draws air through a size-selective cyclone onto a filter, which a laboratory analyzes afterward. NIOSH has shortened the wait with its Field Analysis of Silica Tool, which gives results the same or next day using a portable infrared analyzer ([NIOSH, FAST](https://www.cdc.gov/niosh/publications/numbered/2021-118.html)), but that still reports after the shift and needs equipment most small quarries and workshops do not have. Real-time feedback during the shift exists for US underground coal miners through the continuous personal dust monitor ([US Department of Labor, 2016](https://www.dol.gov/newsroom/releases/msha/msha20160801)), a specialized instrument well beyond the budget of an informal quarry.

## Prior work and the gap

- **Continuous personal dust monitors** (for example the Thermo PDM3700 used in US coal mines) give in-shift results for coal mine dust but are costly and not designed for silica fraction estimates in other commodities.
- **Real-time optical monitors.** NIOSH notes that factory-calibrated optical monitors can differ by up to a factor of 10 from gravimetric samples, because the signal depends on particle size, shape and refractive index; a site correction factor from a filter sample is needed ([Cauda, NIOSH Manual of Analytical Methods, 2021](https://www.cdc.gov/niosh/nmam/pdf/chapter-am.pdf)).
- **Low-cost particle sensors in mining.** A calibration study found that a Plantower PMS5003 reached R² of 0.70 to 0.90 against a reference below 3.0 mg/m³ of coal dust, and suggested such sensors could extend personal monitoring to all miners ([Amoah et al., Science of the Total Environment, 2023](https://www.sciencedirect.com/science/article/abs/pii/S0048969722074381)).
- **Sensor modules with a respirable size bin.** The Sensirion SPS30 reports PM4 mass (particles up to 4 µm), close to the respirable convention, over 0 to 1,000 µg/m³ ([Sensirion SPS30 datasheet](https://sensirion.com/media/documents/8600FF88/64A3B8D6/Sensirion_PM_Sensors_Datasheet_SPS30.pdf)).

The gap is an open, low-cost, wearable reference design that estimates respirable dust and silica exposure through the shift, tells the worker when the shift average is heading over a limit, and keeps the worker in control of the data. No optical sensor can identify silica; DustBadge can only estimate it from respirable dust and a site-specific silica fraction, and it must say so.

## Users and context

| User | Need | Context |
| --- | --- | --- |
| Quarry, pit or stone yard worker | Know during the shift when dust is high enough to act (wet the cut, move upwind, fit a respirator, stop) | Surface quarries and open pits, 8 to 12 h shifts, heat, dust, water sprays |
| Stone benchtop fabricator | Warning when cutting, grinding or polishing raises exposure | Small workshops, often without any exposure sampling |
| Construction worker | Feedback when cutting concrete, brick or tile | Building sites, short high-dust tasks |
| Supervisor or safety officer | Which tasks and places drive exposure, with worker consent | Site safety reviews |
| Occupational hygienist, researcher or worker organization | A cheap screening tool between regulatory samples; open data format | Surveys, research, community health programs |

## Constraints

- Garage-buildable prototype, a value-engineering target of $91 USD in parts (`budget_usd`, a hypothetical control target, not a limit; moved from $90 by Amish on 2026-09-26, DBG-DDR-002), with an estimated cost of $91.50 ($0.50 over the target, the foam pad of the worn version), from off-the-shelf modules and 3D-printed parts.
- Small and light enough to wear on the chest within 30 cm of the nose and mouth for a full shift.
- Must work in heat, dust and wet spray without clogging or false alarms dominating.
- Exposure data belongs to the worker. Sharing with an employer is by consent, and the device must not become a tool for discipline.
- Research and educational prototype only. It is not a medical device, is not certified monitoring or personal protective equipment, does not replace regulatory sampling or respirators, and is not certified for explosive atmospheres.

## Out of scope

- Direct measurement of silica content (needs a filter and laboratory or field infrared analysis).
- Regulatory compliance sampling.
- Use in underground coal mines or any atmosphere that may contain flammable gas or combustible dust, which would require an intrinsically safe, certified design.
- Medical diagnosis or health surveillance.

## Open questions

- First sector: surface quarries and stone fabrication first, with underground coal and explosive atmospheres excluded. Decided by Amish, 2026-09-25: go with recommendation (DBG-DDR-001, D6; DBG-DDR-002).
- First co-design partner: a worker organization, NGO or university occupational hygiene group. Proposed, awaiting Amish (DBG-DDR-001, O1).
- Default exposure limits, which differ by country (for example 50 µg/m³ in the US and 100 µg/m³ as the EU binding limit): US values by default, configurable. Decided by Amish, 2026-09-25: go with recommendation (DBG-DDR-001, D3; DBG-DDR-002).
- How a site silica fraction is obtained where no laboratory is near. Proposed: one filter sample per site and task analyzed by a partner laboratory; At low-dust, high-silica sites the reference is now a 4.2 L/min cyclone over two shifts (decided by Amish, 2026-09-25, DBG-DDR-002 D9), but where the sample is analyzed when no laboratory is near remains open. Proposed, awaiting Amish (DBG-DDR-001, O2).

## User research and co-design

This design is for communities the author is not part of, so requirements come from the people who will use it.

- [ ] Identify a local partner organization (Helpful Engineering network, NGO or university)
- [ ] Run co-design sessions with intended users; record who, where and what was learned
- [ ] Validate load, distance, terrain and cost assumptions in the field
- [ ] Revise requirements (REQ) from findings before freezing the design

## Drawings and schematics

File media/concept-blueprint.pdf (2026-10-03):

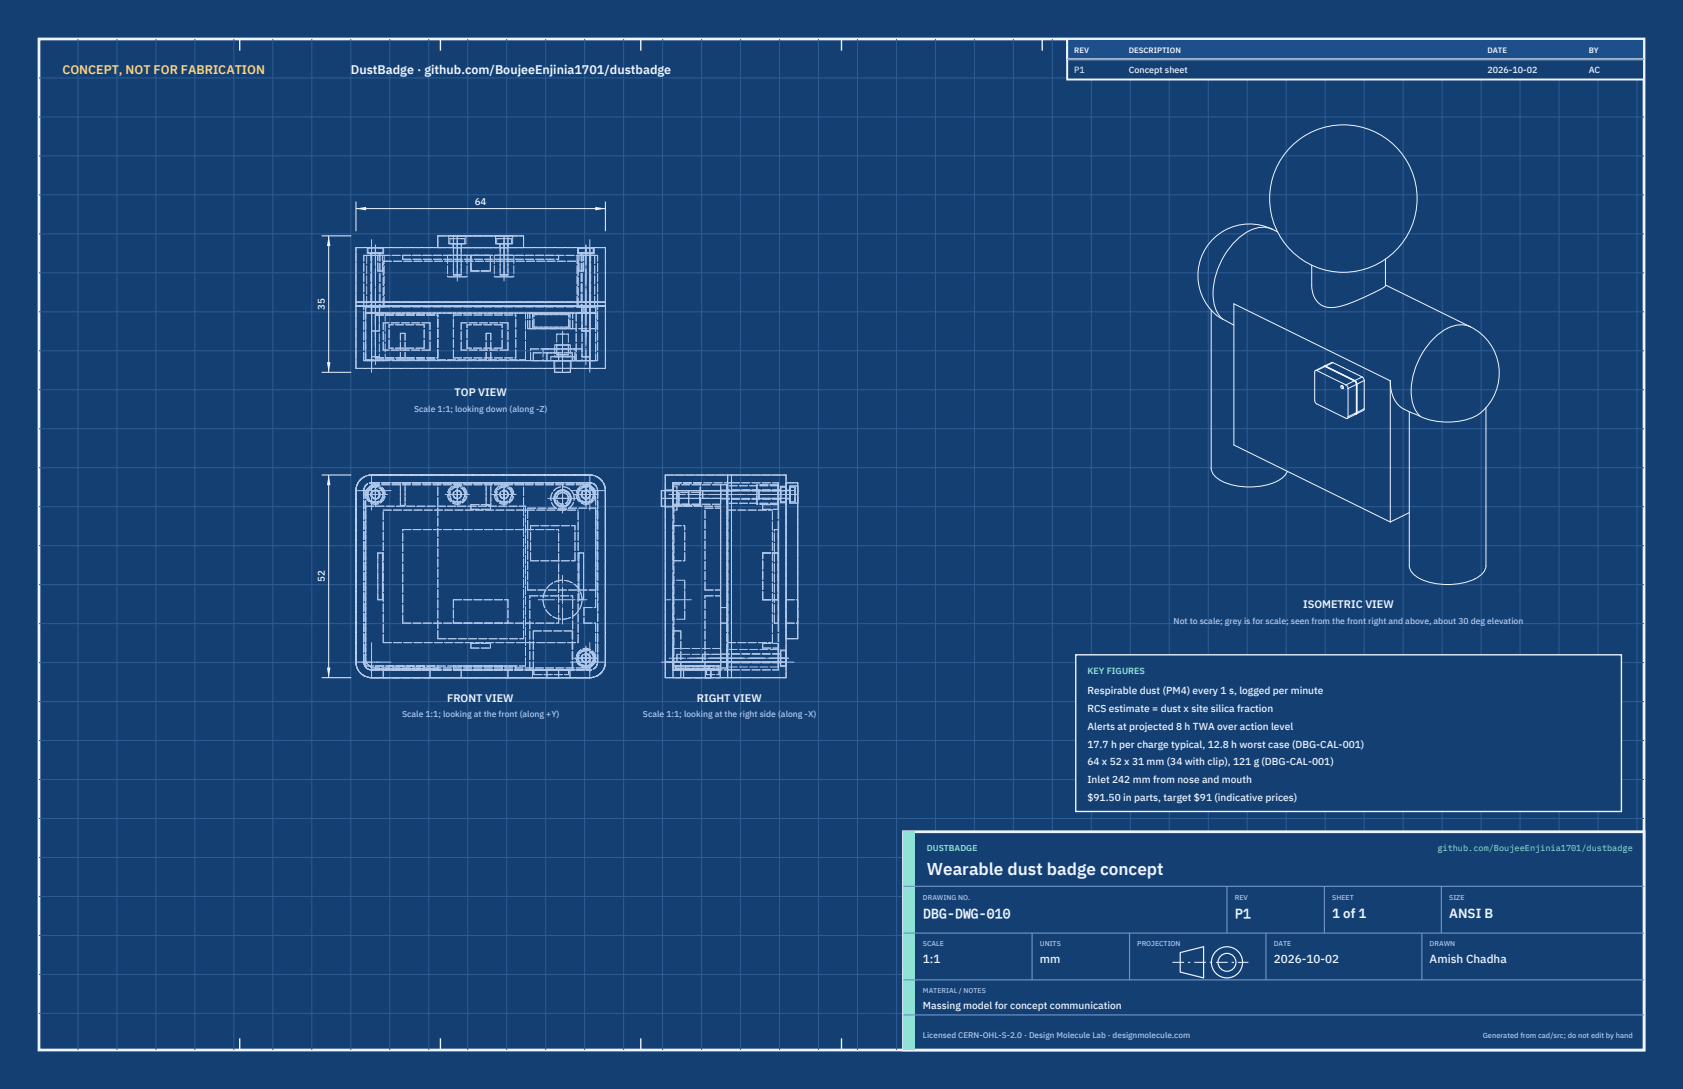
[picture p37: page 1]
CONCEPT, NOT FOR FABRICATION; DustBadge · github.com/BoujeeEnjinia1701/dustbadge; FRONT VIEW; TOP VIEW; RIGHT VIEW; ISOMETRIC VIEW; REV; DESCRIPTION; DATE; Concept sheet; DUSTBADGE; github.com/BoujeeEnjinia1701/dustbadge; DRAWING NO. DBG-DWG-010; REV P1; SHEET 1 of 1; SIZE ANSI B; SCALE 1:1; UNITS mm; PROJECTION; DRAWN Amish Chadha; Licensed CERN-OHL-S-2.0 · Design Molecule Lab · designmolecule.com; Generated from cad/src; do not edit by hand

Scale 1:1; looking down (along -Z)

Not to scale; grey is for scale; seen from the front right and above, about 30 deg elevation

KEY FIGURES
Respirable dust (PM4) every 1 s, logged per minute
RCS estimate = dust x site silica fraction
Alerts at projected 8 h TWA over action level
17.7 h per charge typical, 12.8 h worst case (DBG-CAL-001)
64 x 52 x 31 mm (34 with clip), 121 g (DBG-CAL-001)
Inlet 242 mm from nose and mouth
$91.50 in parts, target $91 (indicative prices)

Scale 1:1; looking at the front (along +Y)

Scale 1:1; looking at the right side (along -X)

Wearable dust badge concept

MATERIAL / NOTES
Massing model for concept communication

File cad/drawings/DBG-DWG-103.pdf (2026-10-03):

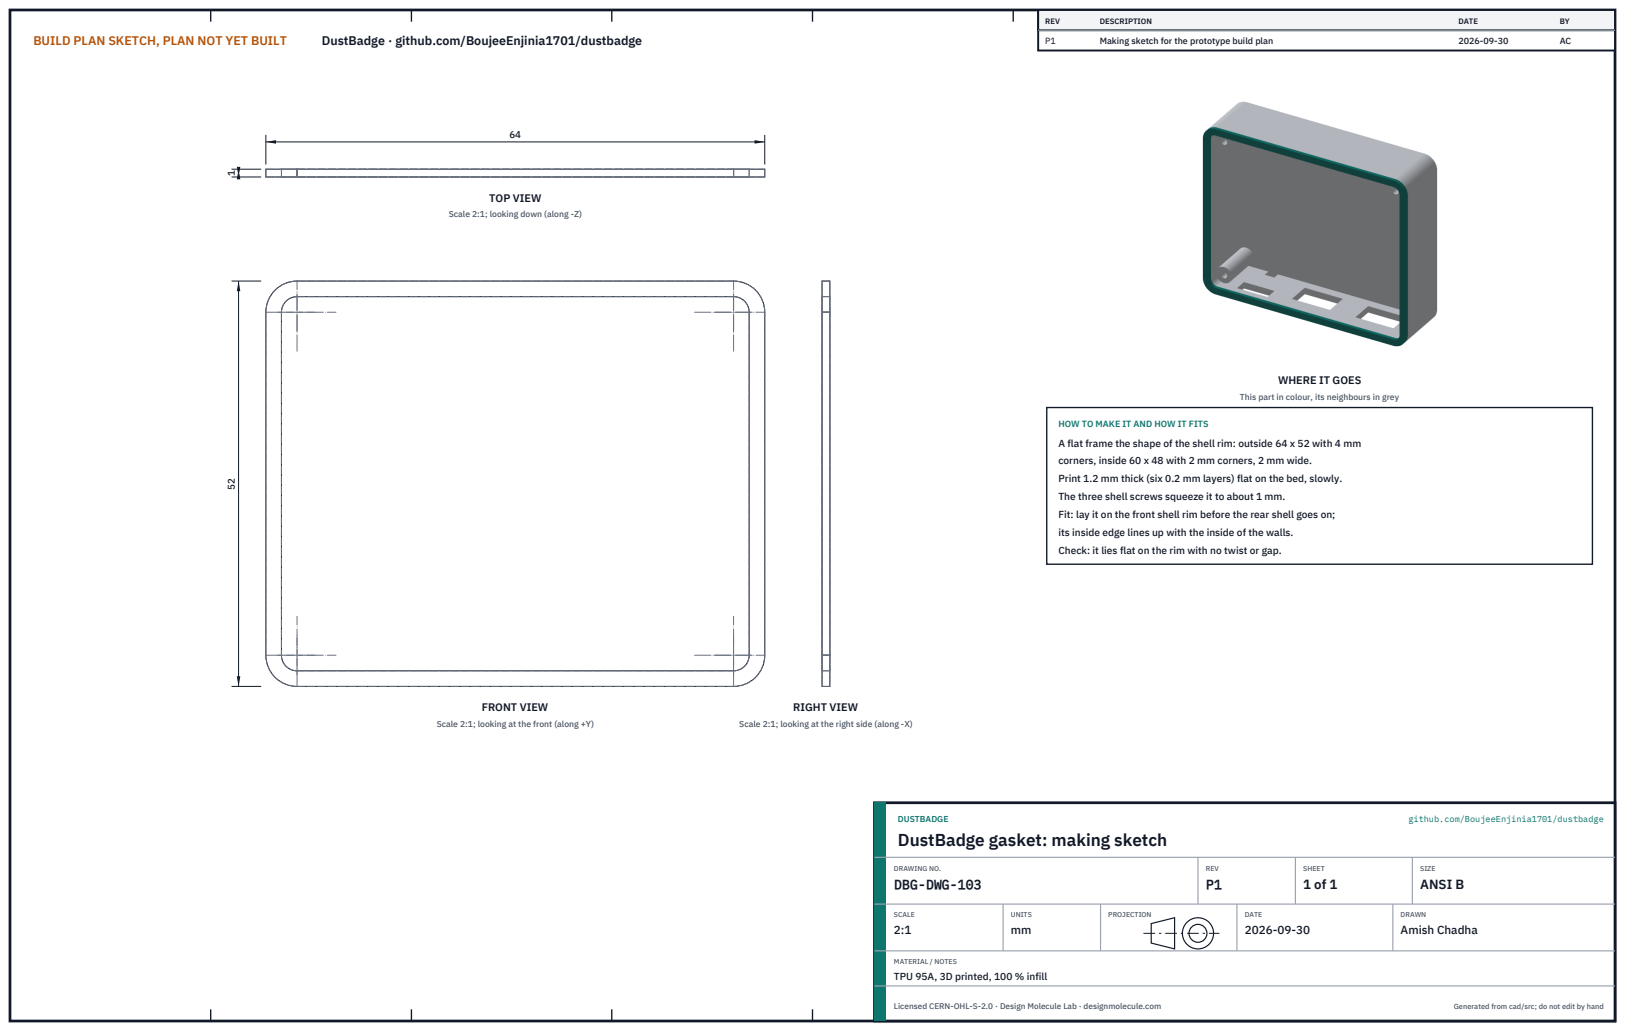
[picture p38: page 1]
BUILD PLAN SKETCH, PLAN NOT YET BUILT; DustBadge · github.com/BoujeeEnjinia1701/dustbadge; FRONT VIEW; TOP VIEW; RIGHT VIEW; REV; DESCRIPTION; DATE; Making sketch for the prototype build plan; DUSTBADGE; github.com/BoujeeEnjinia1701/dustbadge; DRAWING NO. DBG-DWG-103; REV P1; SHEET 1 of 1; SIZE ANSI B; SCALE 2:1; UNITS mm; PROJECTION; DRAWN Amish Chadha; Licensed CERN-OHL-S-2.0 · Design Molecule Lab · designmolecule.com; Generated from cad/src; do not edit by hand

Scale 2:1; looking down (along -Z)

WHERE IT GOES

This part in colour, its neighbours in grey

HOW TO MAKE IT AND HOW IT FITS
A flat frame the shape of the shell rim: outside 64 x 52 with 4 mm
corners, inside 60 x 48 with 2 mm corners, 2 mm wide.
Print 1.2 mm thick (six 0.2 mm layers) flat on the bed, slowly.
The three shell screws squeeze it to about 1 mm.
Fit: lay it on the front shell rim before the rear shell goes on;
its inside edge lines up with the inside of the walls.
Check: it lies flat on the rim with no twist or gap.

Scale 2:1; looking at the front (along +Y)

Scale 2:1; looking at the right side (along -X)

DustBadge gasket: making sketch

MATERIAL / NOTES
TPU 95A, 3D printed, 100 % infill

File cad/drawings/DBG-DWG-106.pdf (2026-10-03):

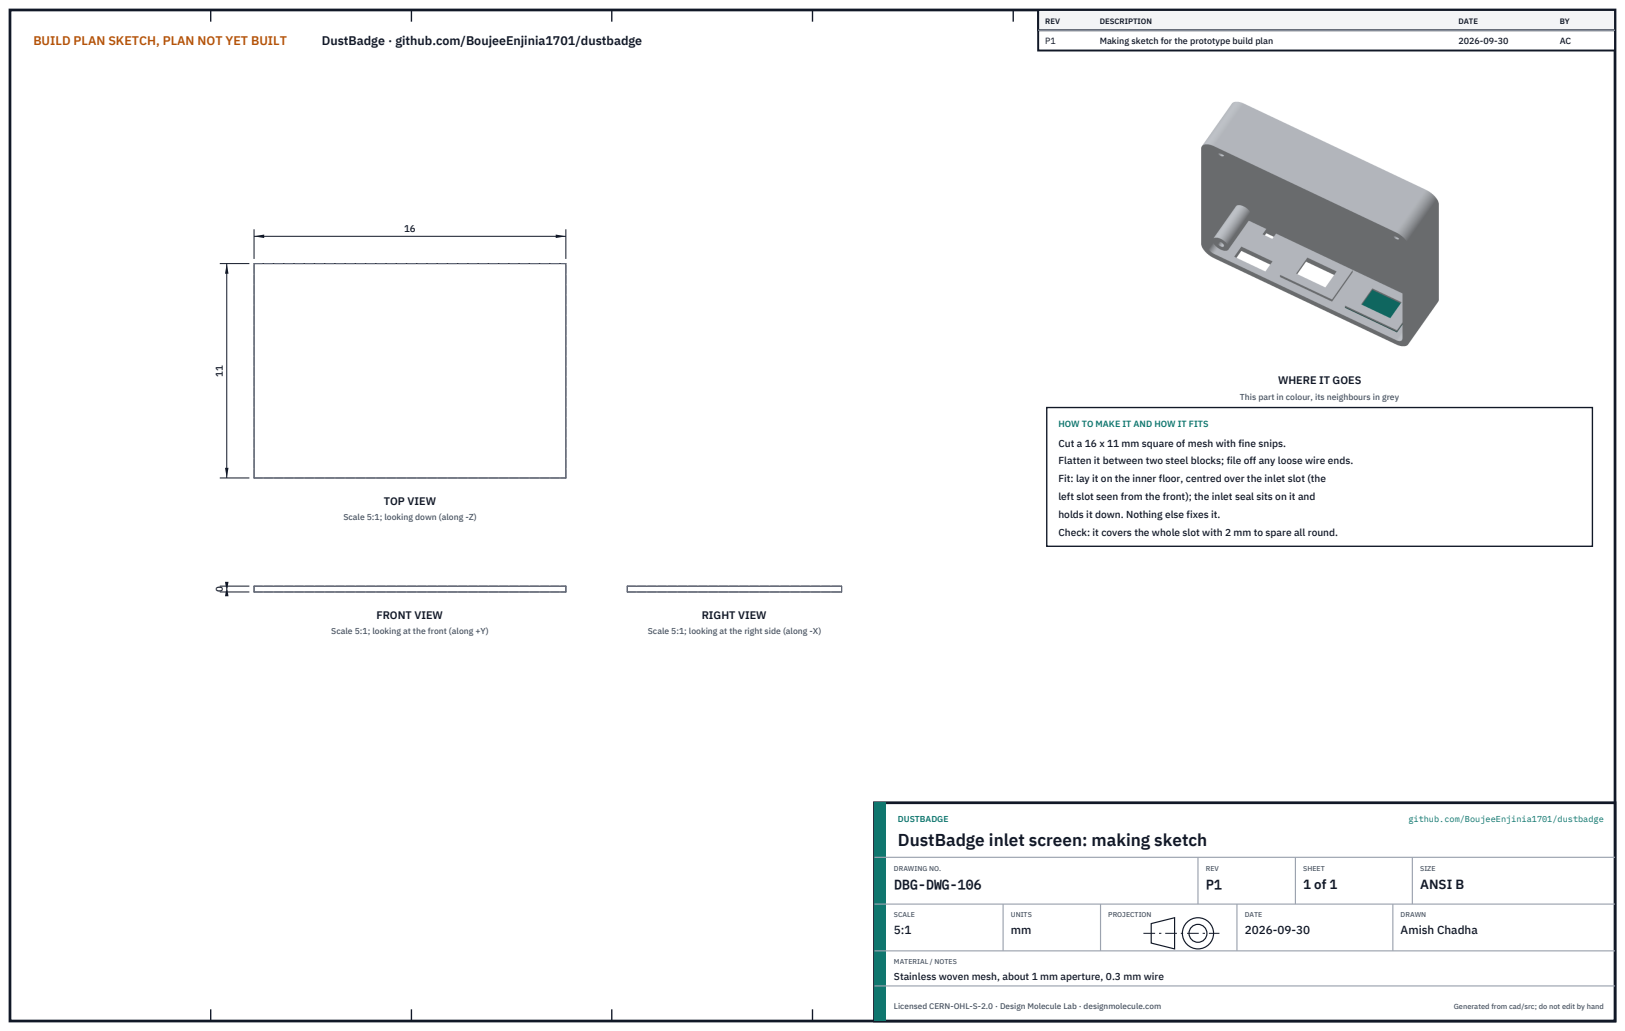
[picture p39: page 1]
BUILD PLAN SKETCH, PLAN NOT YET BUILT; DustBadge · github.com/BoujeeEnjinia1701/dustbadge; FRONT VIEW; TOP VIEW; RIGHT VIEW; REV; DESCRIPTION; DATE; Making sketch for the prototype build plan; DUSTBADGE; github.com/BoujeeEnjinia1701/dustbadge; DRAWING NO. DBG-DWG-106; REV P1; SHEET 1 of 1; SIZE ANSI B; SCALE 5:1; UNITS mm; PROJECTION; DRAWN Amish Chadha; Licensed CERN-OHL-S-2.0 · Design Molecule Lab · designmolecule.com; Generated from cad/src; do not edit by hand

WHERE IT GOES

This part in colour, its neighbours in grey

HOW TO MAKE IT AND HOW IT FITS
Cut a 16 x 11 mm square of mesh with fine snips.
Flatten it between two steel blocks; file off any loose wire ends.
Fit: lay it on the inner floor, centred over the inlet slot (the
left slot seen from the front); the inlet seal sits on it and
holds it down. Nothing else fixes it.
Check: it covers the whole slot with 2 mm to spare all round.

Scale 5:1; looking down (along -Z)

Scale 5:1; looking at the front (along +Y)

Scale 5:1; looking at the right side (along -X)

DustBadge inlet screen: making sketch

MATERIAL / NOTES
Stainless woven mesh, about 1 mm aperture, 0.3 mm wire

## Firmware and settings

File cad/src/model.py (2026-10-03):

"""DustBadge parametric model (build123d), TRL 3, constructable design.
Revised 2026-09-25 for DBG-DDR-002 (2,000 mAh cell, 11.5 mm thick).
Revised 2026-10-02 for the worn version (DBG-DDR-003, A1, decided 2026-10-02): rear shell 1 mm deeper
(rear face at Y = rear_extra) and a foam pad behind the cell.
Revised 2026-09-30 for DBG-DDR-003 (design for construction): shell screws and rear bosses,
TPU gasket, sensor port seals and stop ribs, screen under the inlet seal, cell locating ribs,
clip screws, the carrier board's modules placed and the light pipe given a flange and an LED.

Run from the repo root:  python cad/src/model.py            exports STEP and STL, prints the checks
                         python cad/src/model.py --check    prints the constructability checks only
Exports STEP and STL into cad/step and cad/stl:
    dustbadge-assembly.step / .stl   the whole badge with its bought-in parts
    front-shell.step / .stl          printed front shell with inlet and outlet slots
    rear-shell.step / .stl           printed rear shell with the clip mount

Axes (badge frame, mm): X across the badge, Z up, Y from the wearer outward is negative.
The rear face (against the wearer) is at Y = 0 and the front face at Y = -depth. The badge
center is on the Z axis at Z = 0, so the kit's cutaway (which cuts near the origin) works.
Bought parts are drawn as envelopes. The same PARAMS feed docs/04-calcs/sizing.py
(DBG-CAL-001), the drawing DBG-DWG-001 (cad/src/sheets.py), the concept media
(cad/src/concept_media.py) and the build plan pictures (cad/src/build_plan_media.py).
"""
import math
import sys
from pathlib import Path

# Top-level parameters (mm unless stated). Edit these, not the geometry below.
PARAMS = {
    # envelope and shells (1 front, 9 rear)
    "W": 64.0, "H": 52.0, "D": 30.0,        # width X, height Z, depth Y (shells only, clip excluded)
    "wall": 2.0,
    "rear_extra": 1.0,                       # rear shell deeper by this much: rear face at Y = rear_extra (worn version)
    "split_y": -14.0,                        # Y of the front shell's rim (the gasket sits on it)
    "gasket_t": 1.0,                         # flat TPU gasket between the rims, squeezed thickness
    "corner_r": 4.0,                         # vertical edge radius
    "boss_d": 5.0,                           # three screw bosses in the front shell, clear of the sensor
    "rear_boss_d": 4.5,                      # matching tubes in the rear shell that press on the board
    "bosses": ((-27.0, 21.0), (27.0, 21.0), (27.0, -21.0)),   # X, Z; the board rests on them
    "boss_end_y": -15.8,                     # front boss ends; the board's front face
    "screw_len": 20.0,                       # M2 x 20 thread-forming screws through the rear shell
    "cbore": (4.2, 1.4),                     # counterbore in the rear face for the screw heads (dia, depth)
    # 3 particle sensor, SPS30 class: 41 x 41 x 12 mm, inlet and outlet on the lower edge
    "sensor": (41.0, 12.0, 41.0),            # X, Y, Z
    "sensor_x": -9.0, "sensor_y": -21.8,     # center; ports face down onto the slots
    "sensor_port": (9.0, 6.0),               # inlet and outlet port size on the sensor edge (X, Y)
    "sensor_port_dx": 10.0,                  # inlet at -dx, outlet at +dx from the sensor center
    "rib_x": (-20.0, 2.0), "rib_t": 1.2, "rib_y1": -21.0,   # two stop ribs above the sensor (front shell)
    # 2 inlet screen under the inlet seal; two slots in the bottom face of the front shell
    "slot": (12.0, 7.0),                     # X, Y of each slot
    "screen": (16.0, 11.0, 0.3),             # mesh square laid on the inner floor over the inlet slot
    "seal": (16.0, 11.0), "seal_t": (0.7, 1.0),   # printed TPU port seals: inlet (on the screen), outlet
    # 4 controller module, 5 motor, 6 LED and light pipe
    "module": (17.5, 4.0, 21.0), "module_pos": (20.8, -17.8, 7.0),
    "motor_d": 10.0, "motor_t": 3.0, "motor_pos": (21.0, -26.5, -6.0),   # stuck to the front face inside
    "led_d": 4.0, "led_pos": (21.0, 20.0),   # X, Z of the light pipe through the front face
    "pipe_flange": (6.0, 1.0), "pipe_len": 7.0, "lamp": (3.0, 5.3),
    # 7 carrier board (perfboard) with the charger, boost and humidity modules
    "pcb": (59.0, 1.6, 47.0), "pcb_y": -15.0, "pcb_chamfer": 1.5,
    "pcb_notch": (3.0, 4.0), "pcb_notch_z": -10.0,       # notch in the right edge for the cell lead
    "charger": (11.0, 4.0, 19.0), "charger_x": 18.1,     # on the board, USB-C on its lower edge
    "usb": (8.9, 3.2, 7.3), "usb_recess": 0.8,           # USB-C receptacle; mouth 0.8 mm inside the face
    "usb_x": 18.1,                                       # USB-C opening in the bottom face (X)
    "boost": (11.4, 3.0, 9.0), "boost_pos": (18.5, 4.0),  # X, Z of its lower left corner region, front face
    "rh": (10.0, 2.0, 10.0), "rh_vent_x": 18.5,          # humidity breakout on the floor; vent under it
    # 8 cell, 2,000 mAh protected LiPo (DBG-DDR-002 D8; was 1,500 mAh, 10 mm thick)
    "cell": (50.0, 11.5, 34.0), "cell_y": -8.25, "cell_mah": 2000.0,
    "cell_rib": (1.2, 4.0),                  # locating ribs on the rear shell: thickness, height
    "pad": (40.0, 1.0, 24.0), "pad_gap": 0.5,   # foam pad behind the cell (X, Y, Z), stuck to the rear wall; clear gap to the cell
    # 10 spring clip with strap loop, on the rear face
    "clip": (22.0, 3.0, 40.0), "clip_z": 4.0,
    "clip_holes": ((-6.0, 21.0), (6.0, 21.0)),   # X, Z of the two M2 x 8 clip screws
    "clip_leaf": 1.0,                         # base leaf thickness; screw heads sit on it
    # wearer interface (for R8): badge center relative to the midpoint of nose and mouth
    "mount_drop": 210.0,                     # below the nose and mouth midpoint (collar or upper strap)
    "mount_lateral": 70.0,                   # to one side of the midline
    "mount_forward": 10.0,                   # inlet forward of the face plane (badge proud of the chest)
    # masses of bought-in parts (g), for R9; shells, gasket and seals from volume
    "m_sensor": 26.3, "m_cell": 38.0, "m_module": 3.0, "m_board": 9.0, "m_motor": 1.0,
    "m_led": 0.5, "m_screen": 0.4, "m_clip": 6.0, "m_hardware": 3.0, "m_pad": 0.2,
    "rho_petg": 1.27, "rho_tpu": 1.21,       # g/cm3
}


def derived(p=PARAMS):
    """Dimensions and figures the calc note and drawing quote, computed from PARAMS."""
    W, H, D = p["W"], p["H"], p["D"]
    sx, sy, sz = p["sensor"]
    inlet_x = p["sensor_x"] - p["sensor_port_dx"]
    outlet_x = p["sensor_x"] + p["sensor_port_dx"]
    # inlet position relative to the nose and mouth midpoint
    inlet_z_rel = -p["mount_drop"] - H / 2
    dist = math.sqrt((p["mount_lateral"] + inlet_x) ** 2 + inlet_z_rel ** 2 + p["mount_forward"] ** 2)
    floor = -H / 2 + p["wall"]                        # inner floor
    s_bot = floor + p["screen"][2] + p["seal_t"][0]   # sensor rests on the inlet seal over the screen
    return {
        "overall": (W, D + p["rear_extra"] + p["clip"][1], H),            # X, Y incl. clip, Z
        "floor": floor,
        "sensor_bottom": s_bot, "sensor_top": s_bot + sz, "sensor_zc": s_bot + sz / 2,
        "inlet_x": inlet_x, "outlet_x": outlet_x,
        "inlet_to_face_mm": dist,
        "front_depth": D + p["split_y"],
        "rear_y0": p["split_y"] + p["gasket_t"],        # rim of the rear shell
        "rear_depth": p["rear_extra"] - (p["split_y"] + p["gasket_t"]),
        "rear_y": p["rear_extra"],                      # rear face
        "cell_back": p["cell_y"] + p["cell"][1] / 2,
        "pad_front": p["rear_extra"] - p["wall"] - p["pad"][1],
        "pcb_front": p["pcb_y"] - p["pcb"][1] / 2, "pcb_back": p["pcb_y"] + p["pcb"][1] / 2,
        "surface_m2": 2 * (W * H + W * D + H * D) * 1e-6,
        "front_area_m2": W * H * 1e-6,
    }


def _b3d():
    import build123d as b
    return b


def box(cx, cy, cz, sx, sy, sz):
    b = _b3d()
    return b.Pos(cx, cy, cz) * b.Box(sx, sy, sz)


def bx(x0, x1, y0, y1, z0, z1):
    return box((x0 + x1) / 2, (y0 + y1) / 2, (z0 + z1) / 2, abs(x1 - x0), abs(y1 - y0), abs(z1 - z0))


def rounded_box(cx, cy, cz, sx, sy, sz, r):
    """Box with its four edges parallel to Y rounded (the badge outline seen from the front)."""
    b = _b3d()
    shape = b.Box(sx, sy, sz)
    edges = shape.edges().filter_by(b.Axis.Y)
    shape = b.fillet(edges, r)
    return b.Pos(cx, cy, cz) * shape


def ycyl(x, y, z, r, h):
    b = _b3d()
    return b.Pos(x, y, z) * b.Rot(90, 0, 0) * b.Cylinder(r, h)


def ycyl2(x, z, y0, y1, r):
    """Cylinder along Y from y0 to y1."""
    return ycyl(x, (y0 + y1) / 2, z, r, abs(y1 - y0))


def fuse(shapes):
    out = None
    for s in shapes:
        out = s if out is None else out + s
    return out


def _seal(cx, cy, z0, t, p):
    ox, oy = p["seal"]
    ix, iy = p["sensor_port"]
    return bx(cx - ox / 2, cx + ox / 2, cy - oy / 2, cy + oy / 2, z0, z0 + t) - \
        bx(cx - ix / 2, cx + ix / 2, cy - iy / 2, cy + iy / 2, z0 - 1, z0 + t + 1)


def _screw(x, z, y_head, length, head=(3.8, 1.3), d=2.0, toward=-1):
    """Pan-head screw along Y. Head underside at y_head; shank runs toward -Y (toward=-1)."""
    hd, hh = head
    h = ycyl2(x, z, y_head, y_head - toward * hh, hd / 2)
    s = ycyl2(x, z, y_head, y_head + toward * length, d / 2)
    return h + s


def build_parts(p=PARAMS):
    """Return an ordered dict: key -> (name, shape, color, bom line)."""
    W, H, D, t = p["W"], p["H"], p["D"], p["wall"]
    sy_ = p["split_y"]
    r = p["corner_r"]
    sx, sdy, sz = p["sensor"]
    d = derived(p)
    fl = d["floor"]
    pf, pb = d["pcb_front"], d["pcb_back"]
    parts = {}

    # 1 front shell: from Y = -D to split, open toward the rear
    fd = D + sy_
    outer = rounded_box(0, (-D + sy_) / 2, 0, W, fd, H, r)
    inner = rounded_box(0, (-D + t + sy_) / 2 + 0.5, 0, W - 2 * t, fd - t + 1, H - 2 * t, max(r - t, 0.5))
    front = outer - inner
    # screw bosses from the inside of the front face back to the board, with screw holes
    by0, by1 = -D + t, p["boss_end_y"]
    for bxx, bz in p["bosses"]:
        front = front + ycyl2(bxx, bz, by0 - 0.01, by1, p["boss_d"] / 2)
    for bxx, bz in p["bosses"]:
        front = front - ycyl2(bxx, bz, by1 + 1, -D + t + 1.0, 1.0)
    # two stop ribs above the sensor, from the front face back 7 mm, 0.2 mm above it
    rt = p["rib_t"]
    for rx in p["rib_x"]:
        front = front + bx(rx - rt / 2, rx + rt / 2, -D + t - 0.01, p["rib_y1"], d["sensor_top"] + 0.2, H / 2 - t + 0.01)
    # bottom slots: sensor inlet (screened) and outlet, USB-C, humidity vent
    slx, sly = p["slot"]
    for xx in (d["inlet_x"], d["outlet_x"]):
        front = front - box(xx, p["sensor_y"], -H / 2, slx, sly, 2 * t + 2)
    ux, uy, uz = p["usb"]
    usb_y = pf - p["charger"][1] / 2
    front = front - box(p["usb_x"], usb_y, -H / 2, ux + 0.7, uy + 0.6, 2 * t + 2)
    rh_y = -D + t + p["rh"][1] / 2
    front = front - box(p["rh_vent_x"], rh_y, -H / 2, 3.0, 2.0, 2 * t + 2)
    # LED light pipe hole in the front face
    lx, lz = p["led_pos"]
    front = front - ycyl(lx, -D + t / 2, lz, p["led_d"] / 2 + 0.2, t + 2)
    parts["front"] = ("Front shell with bottom inlet", front, "#EAB308", 1)

    # 2 inlet screen, laid on the inner floor over the inlet slot
    scx, scy, sct = p["screen"]
    parts["screen"] = ("Inlet dust screen", bx(d["inlet_x"] - scx / 2, d["inlet_x"] + scx / 2, p["sensor_y"] - scy / 2,
                                                p["sensor_y"] + scy / 2, fl, fl + sct), "#374151", 2)
    # port seals (printed TPU, BOM line 9): inlet on the screen, outlet on the floor
    seals = _seal(d["inlet_x"], p["sensor_y"], fl + sct, p["seal_t"][0], p) + \
        _seal(d["outlet_x"], p["sensor_y"], fl, p["seal_t"][1], p)
    parts["seals"] = ("Sensor port seals (TPU)", seals, "#1F2937", 9)

    # 3 particle sensor with its two ports facing down onto the seals
    sensor = box(p["sensor_x"], p["sensor_y"], d["sensor_zc"], sx, sdy, sz)
    parts["sensor"] = ("Optical particle sensor (SPS30 class)", sensor, "#0F766E", 3)

    # 4 controller, 5 motor, 6 light pipe and LED
    mx, my, mz = p["module_pos"]
    parts["module"] = ("Controller and BLE module", box(mx, my, mz, *p["module"]), "#1D4ED8", 4)
    ox, oy, oz = p["motor_pos"]
    parts["motor"] = ("Vibration motor", ycyl(ox, oy, oz, p["motor_d"] / 2, p["motor_t"]), "#6B7280", 5)
    fdia, ft = p["pipe_flange"]
    y_in = -D + t                                       # inner face of the front wall
    pipe = ycyl2(lx, lz, -D - 1.0, y_in, p["led_d"] / 2) + ycyl2(lx, lz, y_in, y_in + ft, fdia / 2) + \
        ycyl2(lx, lz, y_in + ft, -D - 1.0 + p["pipe_len"], p["led_d"] / 2)
    ld, ll = p["lamp"]
    pocket_y0 = -D - 1.0 + p["pipe_len"] - 2.5
    pipe = pipe - ycyl2(lx, lz, pocket_y0, pocket_y0 + 5, ld / 2)
    parts["led"] = ("Alert light pipe", pipe, "#DC2626", 6)
    parts["lamp"] = ("Red LED, 3 mm", ycyl2(lx, lz, pocket_y0, pocket_y0 + ll, ld / 2), "#991B1B", 6)

    # 7 carrier board (perfboard) with screw holes, and its modules
    bx_, by_, bz_ = p["pcb"]
    pcb = box(0, p["pcb_y"], 0, bx_, by_, bz_)
    for hx, hz in p["bosses"]:
        pcb = pcb - ycyl(hx, p["pcb_y"], hz, 1.1, by_ + 1)
    import build123d as b_
    cf = p["pcb_chamfer"]
    for sxx in (-1, 1):                                  # corners cut to clear the shells' inside corners
        for szz in (-1, 1):
            pcb = pcb - b_.Pos(sxx * bx_ / 2, p["pcb_y"], szz * bz_ / 2) * b_.Rot(0, 45, 0) * b_.Box(cf * 2 ** 0.5, by_ + 2, cf * 2 ** 0.5)
    nx, nz = p["pcb_notch"]
    pcb = pcb - bx(bx_ / 2 - nx, bx_ / 2 + 1, p["pcb_y"] - 2, p["pcb_y"] + 2, -nz / 2 + p["pcb_notch_z"], nz / 2 + p["pcb_notch_z"])
    parts["pcb"] = ("Carrier board (perfboard)", pcb, "#15803D", 7)
    cx_, cy_, cz_ = p["charger"]
    ch = bx(p["charger_x"] - cx_ / 2, p["charger_x"] + cx_ / 2, pf - cy_, pf, fl, fl + cz_)
    ch = ch + box(p["usb_x"], usb_y, -H / 2 + p["usb_recess"] + uz / 2, ux, uy, uz)
    parts["charger"] = ("Charger module with USB-C", ch, "#16A34A", 7)
    bsx, bsy, bsz = p["boost"]
    bxc, bz0 = p["boost_pos"]
    parts["boost"] = ("5 V boost module", bx(bxc - bsx / 2, bxc + bsx / 2, y_in, y_in + bsy, bz0, bz0 + bsz), "#22C55E", 7)
    rx_, ry_, rz_ = p["rh"]
    parts["rh"] = ("Humidity sensor breakout", bx(p["rh_vent_x"] - rx_ / 2, p["rh_vent_x"] + rx_ / 2, y_in, y_in + ry_, fl, fl + rz_),
                   "#4ADE80", 7)

    # 8 cell behind the board
    parts["cell"] = (f"LiPo cell, {p['cell_mah']:,.0f} mAh, protected", box(0, p["cell_y"], 0, *p["cell"]), "#C2410C", 8)

    # gasket (BOM line 9): flat frame the shape of the rim
    g0 = sy_
    gout = rounded_box(0, g0 + p["gasket_t"] / 2, 0, W, p["gasket_t"], H, r)
    gin = rounded_box(0, g0 + p["gasket_t"] / 2, 0, W - 2 * t, p["gasket_t"] + 1, H - 2 * t, max(r - t, 0.5))
    parts["gasket"] = ("Gasket (TPU)", gout - gin, "#111827", 9)

    # 9 rear shell: from the gasket to Y = 0, closed at the back, with bosses and ribs
    ry0 = d["rear_y0"]
    Y0 = p["rear_extra"]                               # rear face
    rd = Y0 - ry0
    outer = rounded_box(0, (ry0 + Y0) / 2, 0, W, rd, H, r)
    inner = rounded_box(0, (ry0 + Y0 - t) / 2 - 0.5, 0, W - 2 * t, rd - t + 1, H - 2 * t, max(r - t, 0.5))
    rear = outer - inner
    for hx, hz in p["bosses"]:                         # tubes that press the board onto the front bosses
        rear = rear + ycyl2(hx, hz, Y0 - t + 0.01, pb, p["rear_boss_d"] / 2)
    for hx, hz in p["clip_holes"]:                     # bosses for the clip screws
        rear = rear + ycyl2(hx, hz, Y0 - t + 0.01, Y0 - 7.5, p["boss_d"] / 2)
    cw, chh = p["cell_rib"]
    ccx, ccy, ccz = p["cell"]
    yr0, yr1 = Y0 - t + 0.01, Y0 - t - chh
    for sgn in (-1, 1):                                # cell locating ribs, 0.2 mm off the cell
        x0 = sgn * (ccx / 2 + 0.2)
        rear = rear + bx(x0, x0 + sgn * cw, yr0, yr1, -6, 6)
        z0 = sgn * (ccz / 2 + 0.2)
        rear = rear + bx(-2.5, 2.5, yr0, yr1, z0, z0 + sgn * cw)
    cbd, cbh = p["cbore"]
    for hx, hz in p["bosses"]:
        rear = rear - ycyl2(hx, hz, Y0 + 1, pb - 1, 1.2) - ycyl2(hx, hz, Y0 + 1, Y0 - cbh, cbd / 2)
    for hx, hz in p["clip_holes"]:
        rear = rear - ycyl2(hx, hz, Y0 + 1, Y0 - 7.0, 1.0)
    parts["rear"] = ("Rear shell", rear, "#374151", 9)

    # foam pad (BOM line 13): stuck to the inside of the rear wall behind the cell, clear of it by pad_gap
    pw, pt, ph = p["pad"]
    parts["pad"] = ("Foam pad behind the cell", bx(-pw / 2, pw / 2, Y0 - t - pt, Y0 - t, -ph / 2, ph / 2), "#F59E0B", 13)

    # shell screws: M2 x 20, heads in the counterbores, into the front bosses
    parts["screws"] = ("Shell screws M2 x 20 (3)", fuse([_screw(hx, hz, Y0 - cbh, p["screw_len"]) for hx, hz in p["bosses"]]),
                       "#111827", 11)

    # 10 spring clip with strap loop, and its two screws
    cx_, cy_, cz_ = p["clip"]
    clip = box(0, Y0 + cy_ / 2, p["clip_z"], cx_, cy_, cz_) - box(0, Y0 + cy_ / 2, p["clip_z"] - cz_ / 2 + 7, cx_ - 8, cy_ + 2, 6)
    lf = p["clip_leaf"]
    for hx, hz in p["clip_holes"]:
        clip = clip - ycyl2(hx, hz, Y0 - 1, Y0 + cy_ + 1, 1.1) - ycyl2(hx, hz, Y0 + lf, Y0 + cy_ + 1, 2.2)
    parts["clip"] = ("Spring clip and strap loop", clip, "#9CA3AF", 10)
    parts["clip_screws"] = ("Clip screws M2 x 8 (2)", fuse([_screw(hx, hz, Y0 + lf, 8.0) for hx, hz in p["clip_holes"]]),
                            "#111827", 11)
    return parts


def masses(p=PARAMS, parts=None):
    """Mass breakdown in grams: printed parts from model volume, bought-in parts from PARAMS."""
    parts = parts or build_parts(p)
    rho = p["rho_petg"] / 1000.0                      # g per mm3
    rt = p["rho_tpu"] / 1000.0
    m = {"front shell (PETG)": parts["front"][1].volume * rho,
         "rear shell (PETG)": parts["rear"][1].volume * rho,
         "particle sensor": p["m_sensor"], "cell": p["m_cell"], "controller module": p["m_module"],
         "carrier board and modules": p["m_board"], "motor": p["m_motor"], "LED and light pipe": p["m_led"],
         "screen": p["m_screen"], "foam pad": p["m_pad"], "clip": p["m_clip"], "screws, wire, adhesive": p["m_hardware"],
         "gasket and port seals (TPU)": (parts["gasket"][1].volume + parts["seals"][1].volume) * rt}
    return m


def assembly(p=PARAMS):
    b = _b3d()
    return b.Compound([s for (_, s, _, _) in build_parts(p).values()])


# ------------------------------------------------------------------ constructability checks
def _vol(a, b_):
    try:
        s = a & b_
        return s.volume if s is not None else 0.0
    except Exception:
        return float("nan")
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

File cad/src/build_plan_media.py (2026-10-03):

"""DustBadge prototype build plan pictures (DBG-BLD-001, STANDARDS section 18).

Run from the repo root:  python cad/src/build_plan_media.py [overview|sheets|joints|steps|layouts|wiring ...]
With no argument it draws everything. Every picture is drawn from cad/src/model.py
(build_parts), so the pictures and the model never disagree:
    docs/05-build-plan/overview.png        every component pulled apart, numbered in build order
    cad/drawings/DBG-DWG-101 to 108        making sketches for the made and drilled components
    docs/05-build-plan/joint-NN.png        close-ups of the joints that need explaining
    docs/05-build-plan/step-NN.png         one picture per assembly step
    docs/05-build-plan/bottom-face.png     the openings in the bottom face, full size figures
    docs/05-build-plan/wiring.png          block-level wiring with wire sizes (matplotlib)
Uses .kit/build_views.py. The badge is small, so the 3D pictures scale the model up four times
before shading (the kit tessellates to 1 mm); the making sketches use the true size.
BUILD PLAN ILLUSTRATION, PLAN NOT YET BUILT.
"""
import sys
from pathlib import Path

ROOT = Path(__file__).resolve().parents[2]
sys.path[:0] = [str(ROOT / ".kit"), str(ROOT / "cad" / "src")]
import build_views as bv  # noqa: E402
from build_views import Part  # noqa: E402
from model import PARAMS as P, build_parts, derived, bx  # noqa: E402

OUT = ROOT / "docs" / "05-build-plan"
DWG = ROOT / "cad" / "drawings"
DATE = "2026-09-30"
D = derived(P)
C = build_parts(P)
K = 4.0                                   # picture scale factor (see the module note)

COL = {"front": "#EAB308", "led": "#DC2626", "lamp": "#991B1B", "motor": "#6B7280", "boost": "#22C55E",
       "rh": "#0EA5E9", "screen": "#475569", "seals": "#1F2937", "sensor": "#0F766E", "pcb": "#15803D",
       "module": "#1D4ED8", "charger": "#16A34A", "clip": "#0369A1", "clip_screws": "#111827",
       "rear": "#374151", "pad": "#F59E0B", "cell": "#C2410C", "gasket": "#111827", "screws": "#111827"}


def _fuse(shapes):
    out = None
    for s in shapes:
        out = s if out is None else out + s
    return out


def big(shape):
    """The shape scaled K times about the model origin (locations included)."""
    import build123d as b
    from OCP.gp import gp_Trsf, gp_Pnt
    from OCP.BRepBuilderAPI import BRepBuilderAPI_Transform
    t = gp_Trsf()
    t.SetScale(gp_Pnt(0, 0, 0), K)
    return b.Shape.cast(BRepBuilderAPI_Transform(shape.wrapped, t, True).Shape())


def part(name, keys, color=None, explode=(0, 0, 0), alpha=1.0, shape=None):
    """A picture part from one or more model parts, scaled for shading; explode in true mm."""
    sh = shape if shape is not None else _fuse([C[k][1] for k in keys])
    return Part(name, big(sh), color or COL[keys[0]], None, tuple(K * v for v in explode), alpha)


def win(sh, x0, x1, y0, y1, z0, z1):
    return sh & bx(x0, x1, y0, y1, z0, z1)


# ----------------------------------------------------------------- overview
ORDER = [  # key in the overview, name, model parts, explode (mm); front half above, rear half below
    ("front", "Front shell", ["front"], (0, -110, 0)),
    ("pipe", "Light pipe and LED", ["led", "lamp"], (0, -100, 50)),
    ("motor", "Vibration motor", ["motor"], (5, -98, 64)),
    ("boost", "5 V boost module", ["boost"], (15, -78, 66)),
    ("rh", "Humidity breakout", ["rh"], (15, -60, 80)),
    ("screen", "Inlet screen", ["screen"], (-10, -78, -28)),
    ("seals", "Port seals (2)", ["seals"], (-10, -55, -30)),
    ("sensor", "Particle sensor", ["sensor"], (-5, -30, 8)),
    ("pcb", "Carrier board (perfboard)", ["pcb"], (0, 5, 0)),
    ("module", "Controller module", ["module"], (55, -5, 22)),
    ("charger", "Charger module with USB-C", ["charger"], (55, -5, -14)),
    ("rear", "Rear shell", ["rear"], (0, -30, -95)),
    ("clip", "Spring clip", ["clip"], (0, 0, -95)),
    ("clip_screws", "Clip screws M2 x 8 (2)", ["clip_screws"], (0, 18, -95)),
    ("pad", "Foam pad behind the cell", ["pad"], (0, -48, -95)),
    ("cell", "Cell, 2,000 mAh", ["cell"], (0, -62, -95)),
    ("gasket", "Gasket", ["gasket"], (0, -86, -95)),
    ("screws", "Shell screws M2 x 20 (3)", ["screws"], (0, 40, -95)),
]


def overview():
    parts = [part(n, ks, explode=e) for _, n, ks, e in ORDER]
    return bv.overview(parts, OUT / "overview.png", "DustBadge prototype: every component, pulled apart",
                       subtitle="Numbered in build order. Top row: the front half; bottom row: the rear half. Front of the badge to the left",
                       elev=18, azim=-38, size=(11, 7.5), dpi=150, key=True)


# ----------------------------------------------------------------- making sketches
def ghost(name, keys):
    return Part(name, _fuse([C[k][1] for k in keys]), COL[keys[0]], None, (0, 0, 0), 1.0)
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

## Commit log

2026-09-25 Initial scaffold: standard open hardware layout, CERN-OHL-S v2 + MIT licenses
    Claude-Session: https://claude.ai/code/session_01XuhhSU4W6fYhgCfURbrkut
    [bom.csv]
2026-09-25 Populate to TRL 2: problem, requirements, precis, concept media, BOM and README use cases
    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
    [bom.csv]
2026-09-26 Advance to TRL 3: DDR-001, CAL-001 sizing, parametric model with STEP/STL, GA drawing, priced BOM; TRL 4 on hold
    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
    [bom.csv, dustbadge-assembly.step, dustbadge-assembly.stl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]
2026-09-26 Accept all recommendations (DDR-002), switch footer to designmolecule.com, add README write-up with new inspiration point
    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
    [bom.csv, dustbadge-assembly.step, dustbadge-assembly.stl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]
2026-09-26 Strengthen sources, apply approved budgets, add CITATION.cff and CONTRIBUTORS.md with credits
    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
    [concept_media.py]
2026-09-27 Product appearance model and photoreal renders
    Adds cad/src/product_model.py (appearance model for renders only, all main
    dimensions from model.py) and Blender renders in media/render-*.png,
    captioned with the project, repository and viewing direction. README leads
    with the product render; trl stays 3.
    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
2026-10-01 Image quality pass: legible exploded views, flow diagrams and drawing sheets
    Kit 1.6.1 image layout: the parts list sits in its own column, number bubbles sit on visible parts and never overlap, small parts get a leader, pictures are cropped to the subject, flow labels keep numbers with their units, and sheet captions and the revision table no longer overprint. Concept images, blueprint and general arrangement sheet regenerated; repo-specific labels moved clear of other text and lines.
    [sheets.py]
2026-10-01 Kit 1.7.0: constructable design, illustrated build plan and design decisions register
    The design is now constructable: every part can be made and fits its neighbours, with each change recorded in a Design for construction decision record (made under Amish's 2026-09-30 instruction; ope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
    [bom.csv, dustbadge-assembly.step, dustbadge-assembly.stl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]
2026-10-01 Budget treated as a value-engineering target
    Amish, 2026-10-01: the budget is a hypothetical control target that keeps the design on a value-engineering lens, not a spending limit. Documents now state the value-engineering target and the estima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
2026-10-01 Record Amish's 2026-10-01 decisions
    GrowRider and GravitySort: Amish accepted the recommendations in the design decisions register ("i agree with your recommendations for both GrowRider and GravitySort"). Accepted items, including the 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
2026-10-01 PicoFlow full-bore valve, GravitySort bump stop, BioMedical cards
    PicoFlow: Amish accepted the full-bore inlet valve ("picoflow - i agree with the recommendation", 2026-10-01); the 125 mm full-bore gate valve replaces the 90 mm valve and its reducer and expander, output 85.6 W at 10 L/s (5.6 W over R3); model, calculations, build plan, pictures, register and PDFs updated. GravitySort: the accepted adjustable rubber bump stop is now in the model, drawings, build plan pictures and documents ("gravitysort - update the documentation, CAD work and picture renderings"). BreatheBox and DustBadge: social preview cards regenerated with the BioMedical area.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
2026-10-02 Record Amish's approval of the open-decision recommendations
    Amish approved the recommendation on every open decision in the design decisions register ("i approve your recommendations for all 555 open decisions.", 2026-10-02). Each decision is moved to Decisio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
2026-10-03 Carry approved follow-ups into the design and redo photoreal renders
    Amish approved the follow-up actions from the open-decision sign-off ("APPROVED CHANGES, COMPLETE THESE", 2026-10-02), the design-for-construction change tables in ten repos, the last wave's open dec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
    [bom.csv, dustbadge-assembly.step, dustbadge-assembly.stl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]

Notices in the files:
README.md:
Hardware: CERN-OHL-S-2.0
